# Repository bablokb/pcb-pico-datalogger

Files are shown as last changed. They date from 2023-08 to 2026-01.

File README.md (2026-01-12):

Pico Datalogger with Integrated Power-Management
================================================

This is a hardware and software solution for low-frequency
data-logging with a Raspberry Pi Pico (W). The project started as a
hardware project, but the software runs independently of the special
hardware (PCBs) provided in this repository (see some example setups
as provided in the `examples` folder). Nevertheless, the full function
set of the software is not available with standard components.

Besides logging data to a SD-card, the dataloggers can send data to a
central system (called "gateway"). Normally the gateway acts as a
relay to upstream systems, but it could do anything with the data. See
[Gateway](docs/gateway.md) for details.

Core software functions
-----------------------

  * implemented in CircuitPython
  * support for an external RTC for exact time keeping
  * cyclical sensor readout for a wide range of mostly environmental
    [sensors](docs/sensors.md) (currently 25 directly support
    including Open-Meteo weather data and Tasmota power monitoring)
  * supports I2C (two busses), UART-3V3 and UART-5V devices
  * support I2C-multiplexers (PCA954xA, TCA954xA)
  * readout in intervals or using a time-table
  * implementation of additional sensors only need a small wrapper class
    (given a driver-library is available)
  * logging of data to a micro-SD card or equivalent (e.g. XTSD-chip)
  * configurable post-collection [tasks](docs/tasks.md)
    (e.g. update of a display, sending data using WLAN or LoRa)
  * send data to a gateway (see below)
  * power-optimized programs
  * [web-interface](docs/admin_mode.md) for configuration and data download
  * no programming required for standard setups
  * supports (almost) zero current sleep with specialized hardware

For installation and operation, read the documents linked in the next
section.

Quick Links
-----------

  * [Hardware Setup](docs/hardware.md)
  * [Software (Datalogger)](docs/software_datalogger.md)
  * [Software (Gateway)](docs/software_gateway.md)
  * [Configuration](docs/configuration.md)
  * [Software deployment](docs/deployment.md)
  * [Examples](examples/README.md)
  * [Initial setup of the RTC](docs/rtc_setup.md)
  * [Tools and Scripts](docs/tools.md)
  * [Administration mode](docs/admin_mode.md)
  * [Broadcast mode](docs/broadcast_mode.md)
  * [Setup of Blues-Gateway](docs/blues-gateway.md)

Background
----------

For background on and motivation for this project, please see
<https://opendeved.net/programmes/ilce-in-tanzania/>.

Additional resources
--------------------

  * [Sensors](docs/sensors.md)
  * [Tasks](docs/tasks.md)
  * [Components](docs/components.md)
  * [Hardware Architecture](docs/hw_architecture.md)
  * [Power](docs/power.md)
  * [Pinout](docs/pins.md)
  * [Pinout V2](docs/pins-v2.md)
  * [Pinout V3](docs/pins-v3.md)
  * Case for this PCB: https://github.com/OpenDevEd/case-for-pico-datalogger-rev1.00
  * [KiCAD design-files V1](./pico-datalogger.kicad/Readme.md)
  * [KiCAD design-files V2](./pico-datalogger-v2.kicad/Readme.md)
  * [KiCAD design-files sensor-PCB](./pico-sensor-pcb.kicad/Readme.md)
  * [KiCAD design-files display-adapter](./display-adapter.kicad/Readme.md)
  * [KiCAD design-files LoRa-adapter](./lora-adapter.kicad/Readme.md)
  * [References](docs/references.md)

License
-------

Software in `src` is licensed under the GPL3. Hardware is licensed by:

[![CC BY-SA 4.0][cc-by-sa-shield]][cc-by-sa]

This work is licensed under a
[Creative Commons Attribution-ShareAlike 4.0 International
License][cc-by-sa].

[][cc-by-sa]

[cc-by-sa]: http://creativecommons.org/licenses/by-sa/4.0/
[cc-by-sa-image]: https://licensebuttons.net/l/by-sa/4.0/88x31.png
[cc-by-sa-shield]:
https://img.shields.io/badge/License-CC%20BY--SA%204.0-lightgrey.svg

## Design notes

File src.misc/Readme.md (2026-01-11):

Miscellaneous Sources
=====================

This directory contains various source files for libraries used by the
datalogger.

rtc_ext
-------

This is the source for the rtc_ext module. The compiled version is in
`src.shared/lib9/`.

dataviews
---------

These are the source files from the dataviews-repository
<https://github.com/bablokb/circuitpython-dataviews>. The compiled
version is in `src.shared/lib9/`.

From this project are also the driver files `InkyPack.py` and `phat.py`
for the Pimoroni Inky-Pack and Pimoroni e-ink pHat.

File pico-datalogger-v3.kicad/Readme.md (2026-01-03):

KiCAD-Designfiles for Version 3 PCB
===================================

Here are the KiCAD (v7) design-files for the Datalogger-V3-PCB.

Schematic
---------

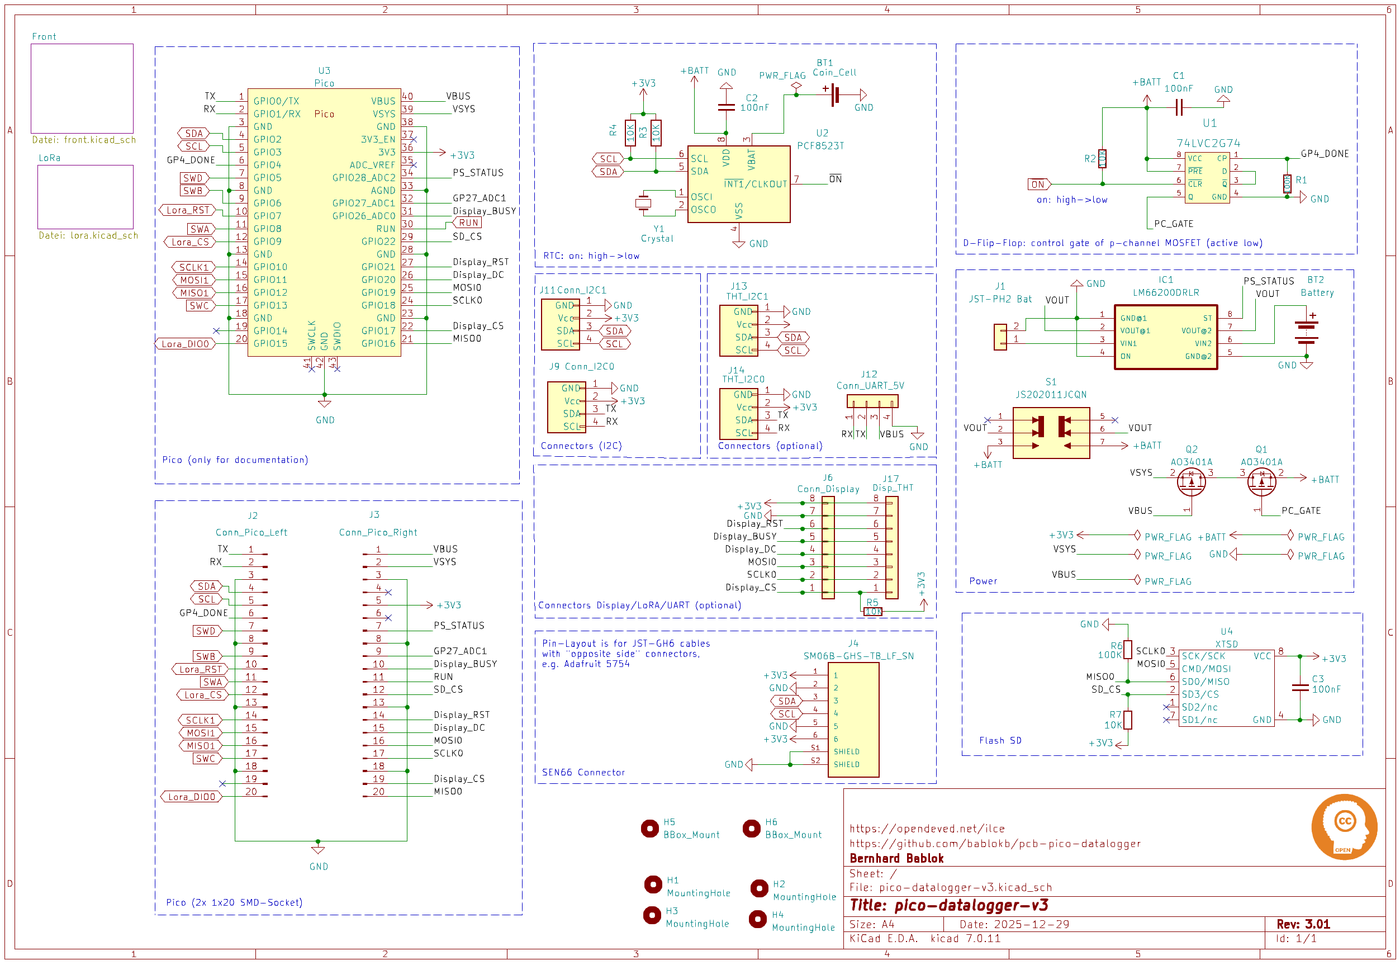
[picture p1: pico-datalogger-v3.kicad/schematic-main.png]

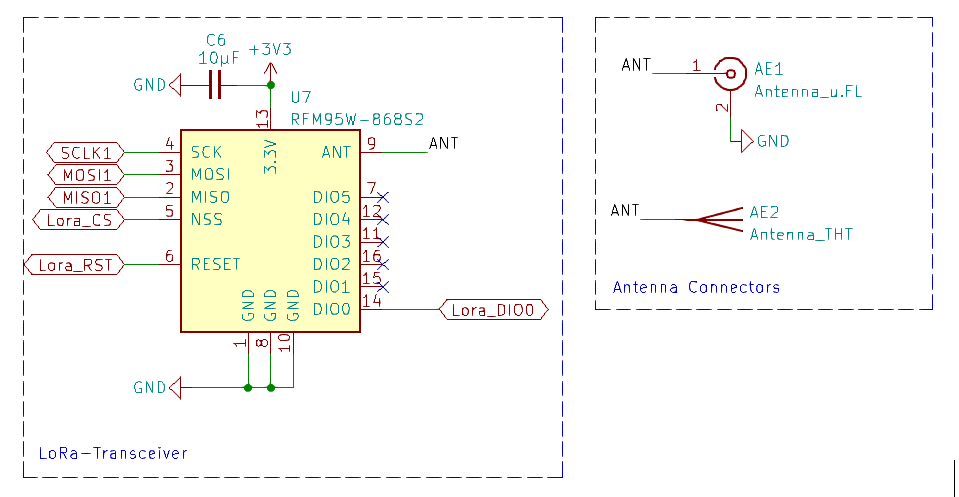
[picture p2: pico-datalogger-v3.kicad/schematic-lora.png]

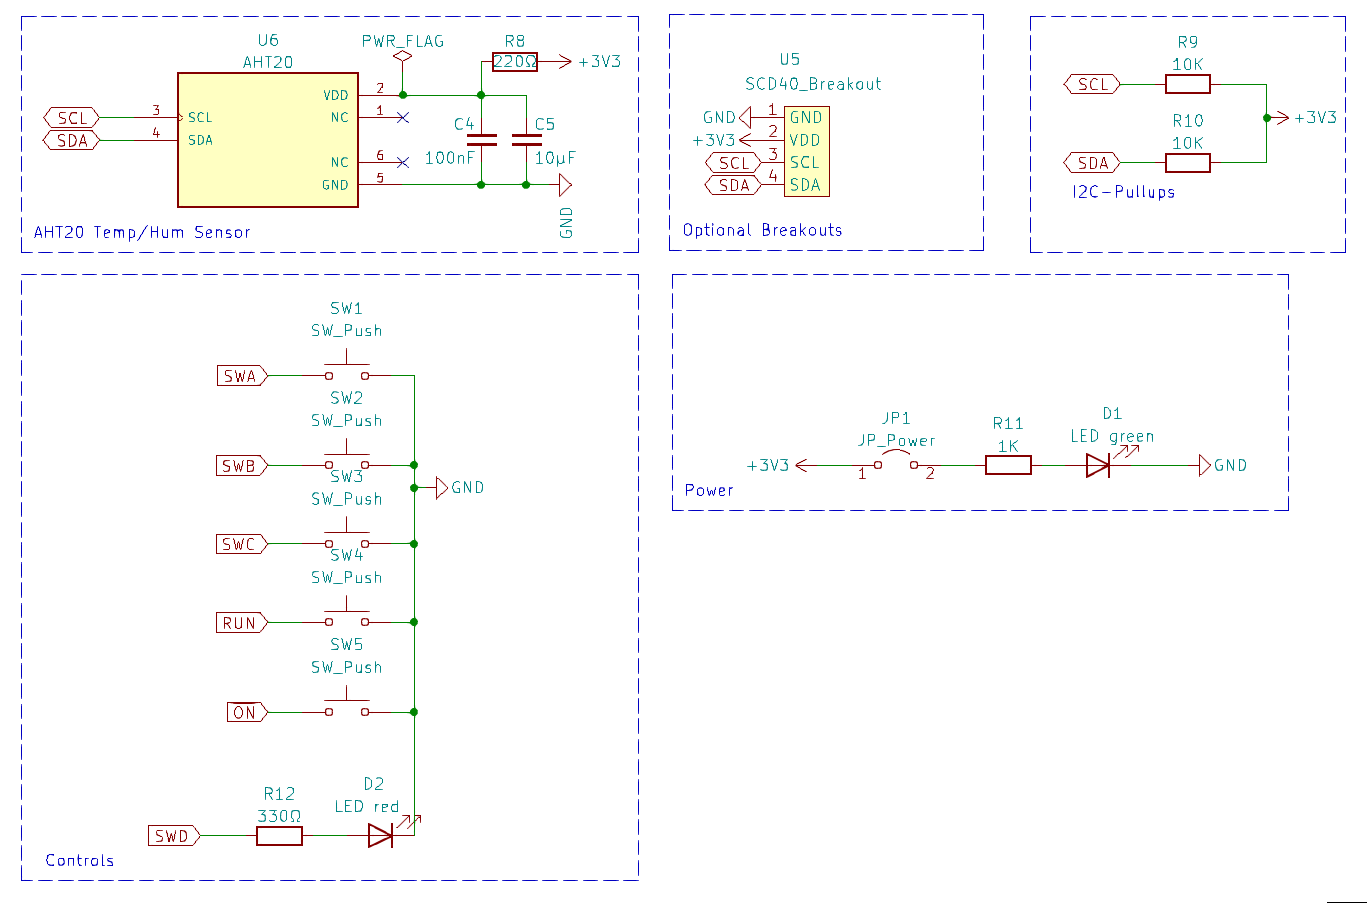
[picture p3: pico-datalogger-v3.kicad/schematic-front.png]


Layout
------

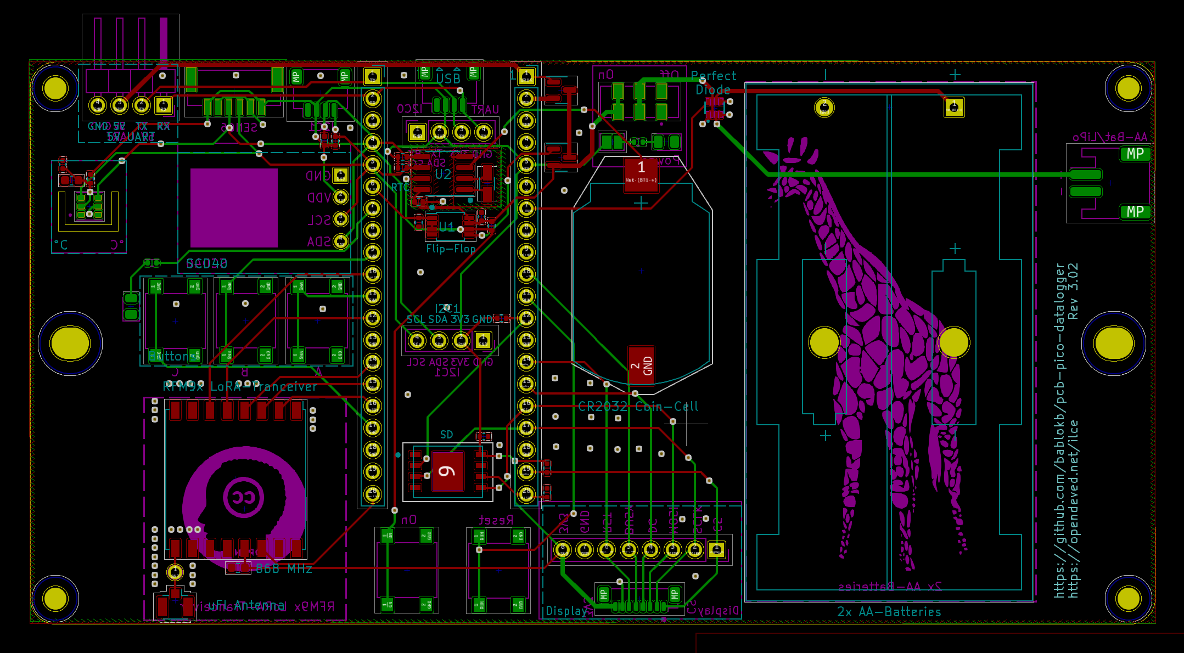
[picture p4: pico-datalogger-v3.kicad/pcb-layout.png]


3D-Views
--------

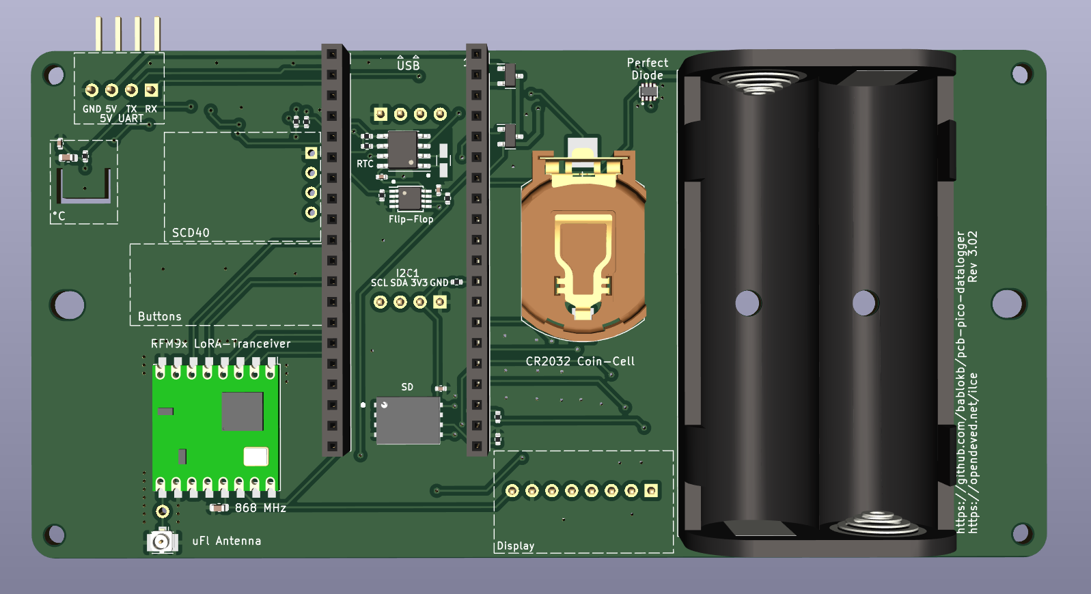
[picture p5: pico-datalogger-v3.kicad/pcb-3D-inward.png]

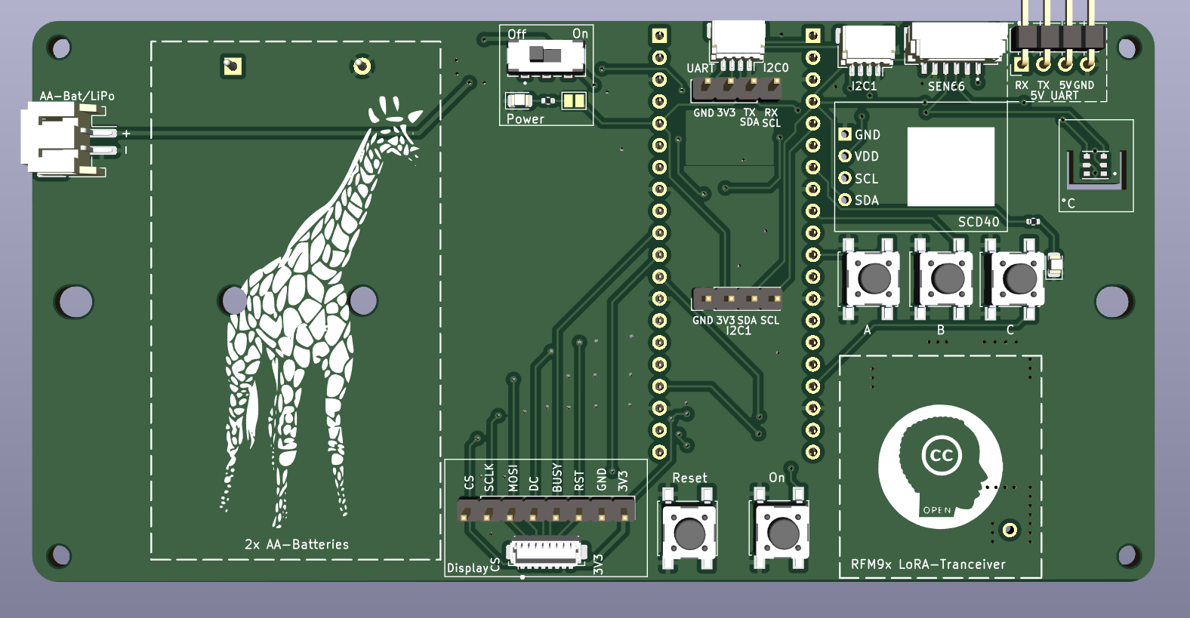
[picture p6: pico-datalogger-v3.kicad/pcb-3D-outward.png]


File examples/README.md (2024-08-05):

Examples
========

This directory contains a number of example setups for the
datalogger-software with standard breakout and components.

Badger2040W
-----------

The Badger2040W is an e-ink display with an integrated Pico-W from
Pimoroni. This device provides a RTC (PCF85063A) and very efficient
power management (with wake on RTC, so time-table based low power
operation is possible). A Stemma/Qt connector allows the connection of
standard sensor breakouts. There is no SD-card support, so data can be
collected and shown on the display, but not saved. Sending data to a
gateway using wifi is possible.

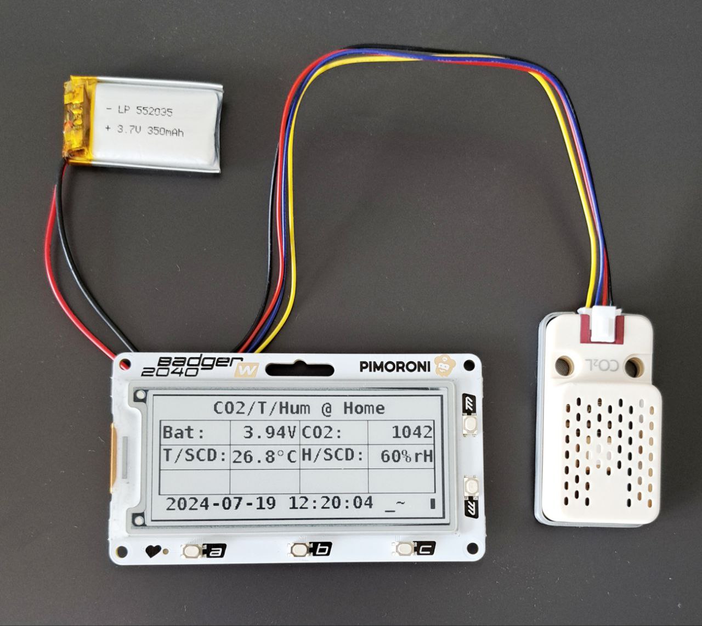
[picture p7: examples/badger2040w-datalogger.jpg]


In the example setup, an SCD41 measures temperature, humidity and
CO2. This setup is ideal for a small, mobile air-quality measurement
system.

PiCowbell-Adalogger
-------------------

The PiCowbell-Adalogger is a Pico-sized breakout with a RTC (PCF8523),
a coincell backup battery and a SD-card slot. The interrupt pin of the
RTC is not exposed, so the RTC does not support wake on RTC and
therefore time-table based operation is limited to continuous mode
with deep-sleep.

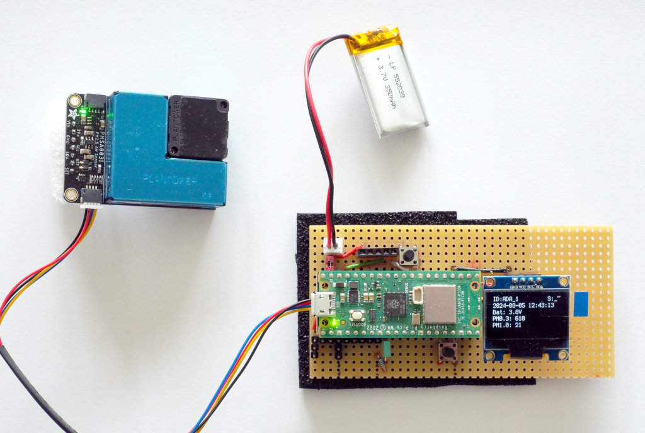
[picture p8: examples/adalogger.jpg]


The setup adds some external components on a perfboard, and thus
mimics most of the special datalogger hardware:

  - JST-PH2 connector for a battery pack/LiPo (upper left)
  - a 5-pin socket for a TPL5111 (to the right of the JST-PH2)
  - a reset button (the adalogger has one, but it is below the Pico-W)
  - a 4-pin socket for an I2C-OLED display (here with the display)
  - a button (used as application button SW_A, lower right)
  - a LED (used as application LED SW_D, in the middle)
  - some additional pins broken out (lower left)

The example here adds an PMS5003 particle sensor (connected via I2C)
and operates in continuous mode (without power-management,
i.e. without TPL511x). Data is not logged to the SD-card but the OLED
displays current data.

Picow-Solo
----------

This example is a standalone configuration for a Pico-W. It reads data
from <https://open-meteo.com> and prints the data to the console. The
sampling interval is 15 minutes, since the data-source does not
provide new data at a higher rate.

You should update the latitude and longitude in `config.py` to your
location (Open-Meteo provides a search function for this). Once up and
running, You should also disable logging in `log_config.py`:

    from log_writer import Logger
    g_logger = Logger(None)

This limits console-output to actual data:

    main.py Ausgabe:
    2024-08-05T13:22:34,22.1,63,1016,3,9.8,306,0.0
    2024-08-05T13:31:04,22.3,63,1016,3,9.7,309,0.0
    2024-08-05T13:46:04,22.5,63,1016,3,9.7,309,0.0

The configuration uses a time-table in continuous mode. In this mode,
the value of `INTERVAL` is ignored, but any interval shorter than 61
seconds still forces the system to use light-sleep instead of
deep-sleep in between sampling.

In a more realistic setup, the data would be at least written to a
SD-card.

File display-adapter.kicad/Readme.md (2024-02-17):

KiCAD-Designfiles
=================

Here are the KiCAD (v6) design-files for the display-adapter-PCB.

Schematic
---------

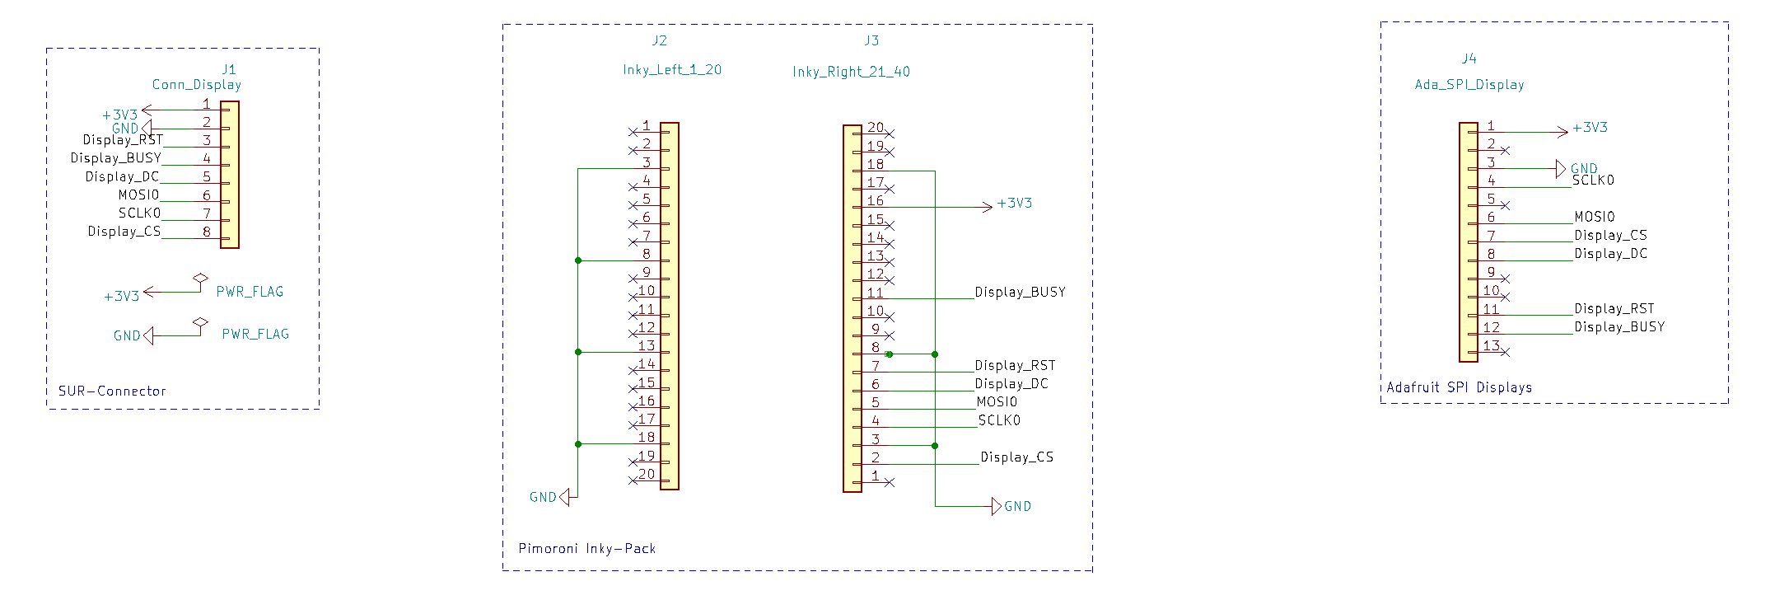
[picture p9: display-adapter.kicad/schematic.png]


Layout
------

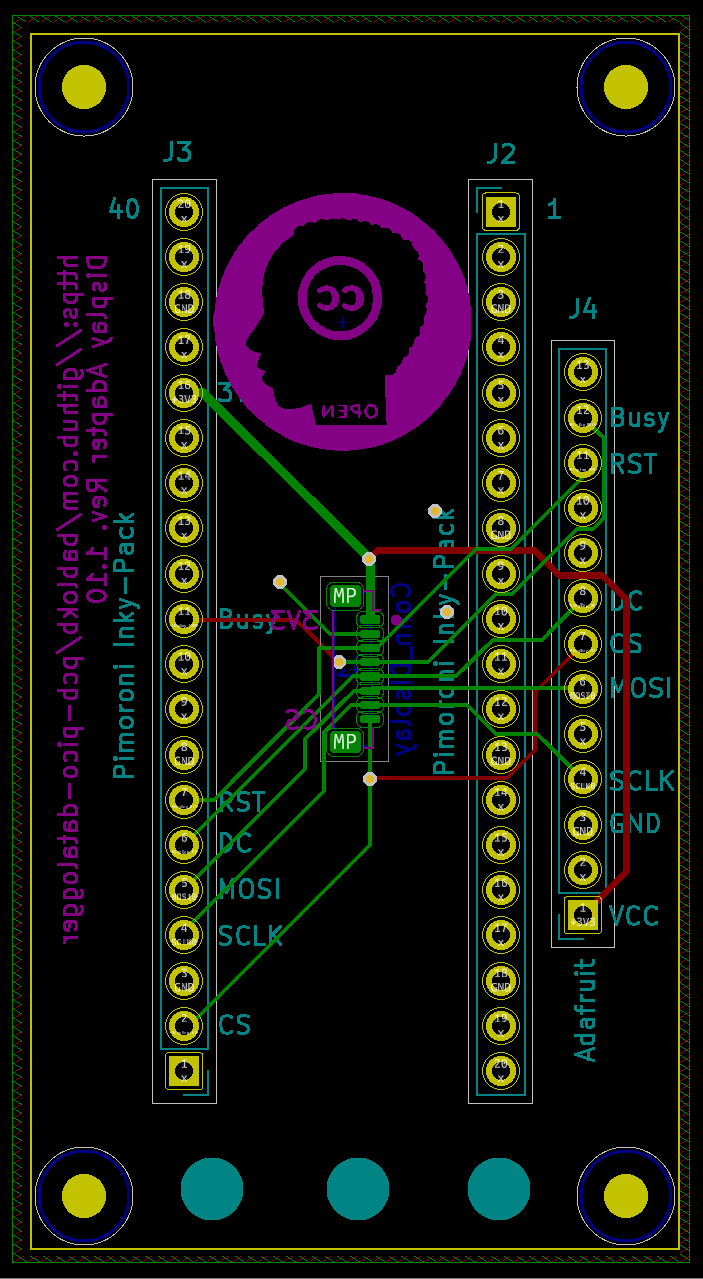
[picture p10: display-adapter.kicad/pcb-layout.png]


3D-Views
--------

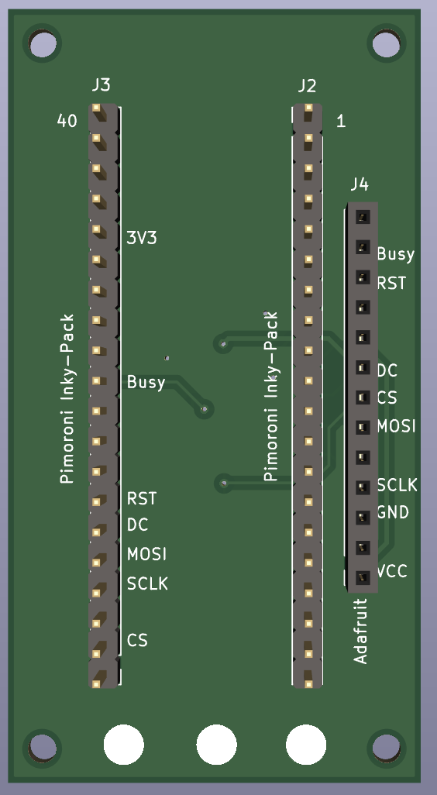
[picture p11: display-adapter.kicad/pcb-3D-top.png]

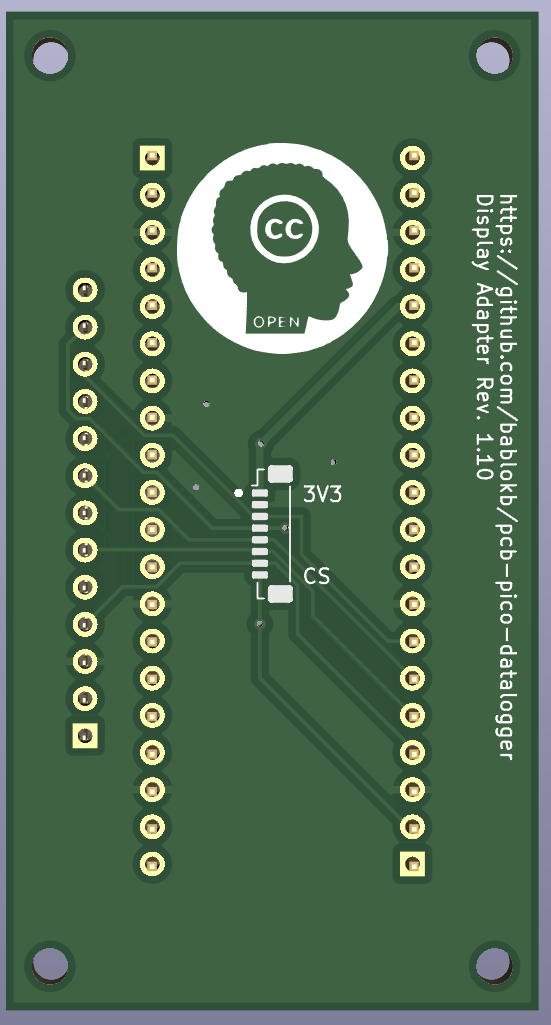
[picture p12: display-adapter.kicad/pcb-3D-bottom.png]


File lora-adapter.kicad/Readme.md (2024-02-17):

KiCAD-Designfiles
=================

Here are the KiCAD (v6) design-files for the LoRa-adapter-PCB.

Schematic
---------

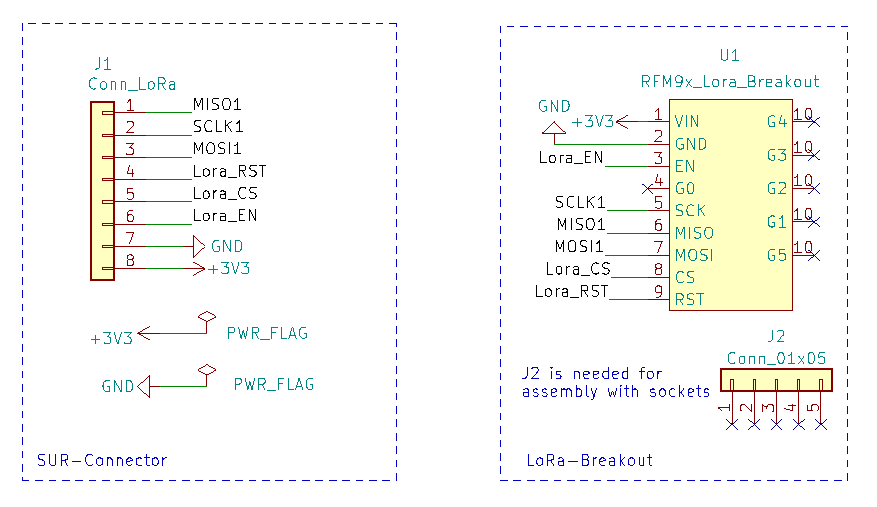
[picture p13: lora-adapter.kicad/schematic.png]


Layout
------

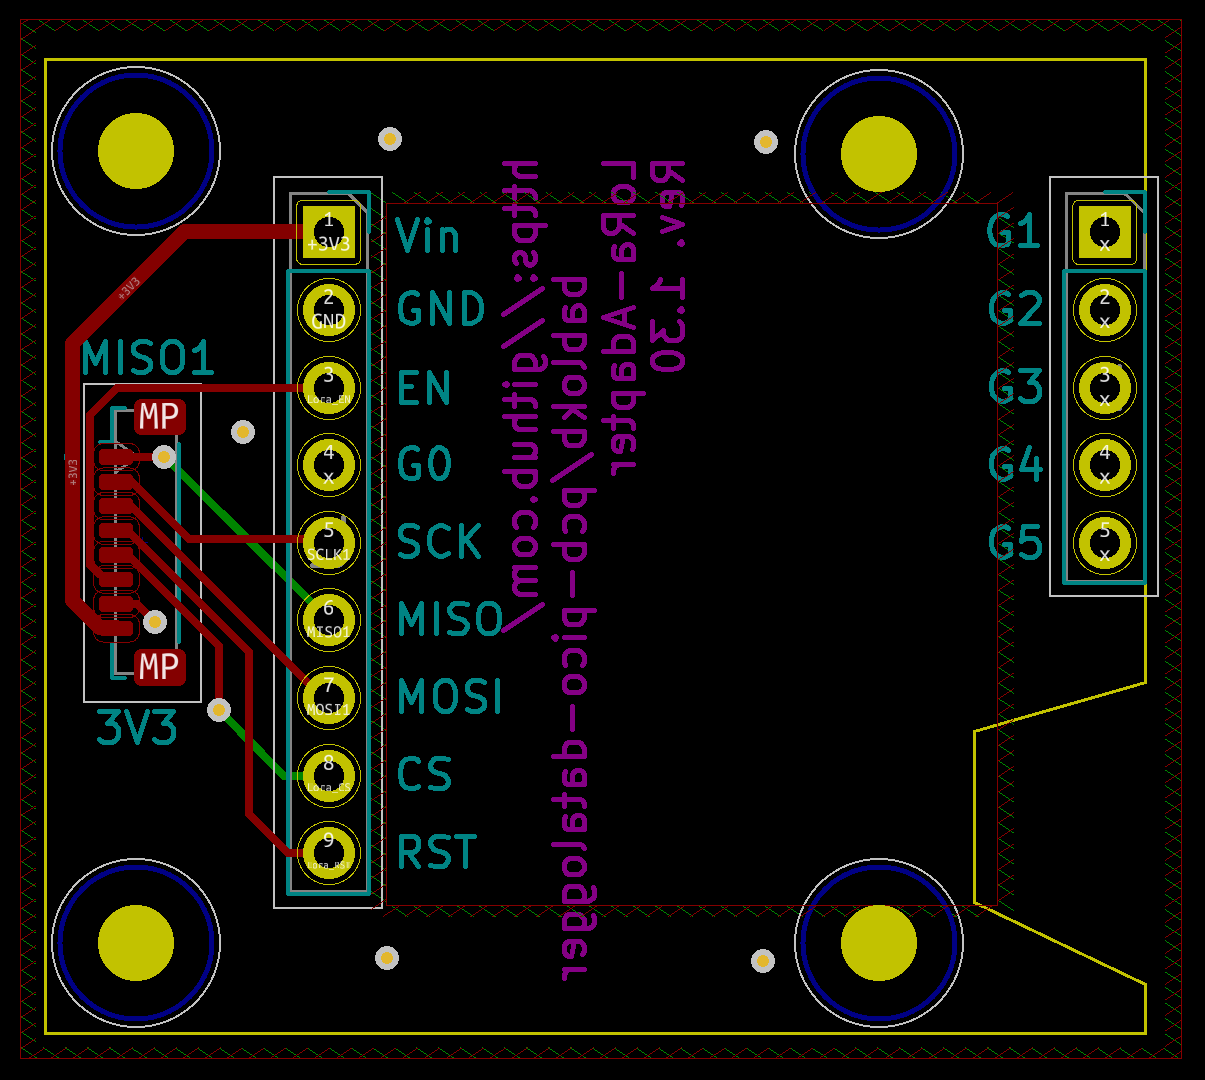
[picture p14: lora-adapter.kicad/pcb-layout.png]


3D-Views
--------

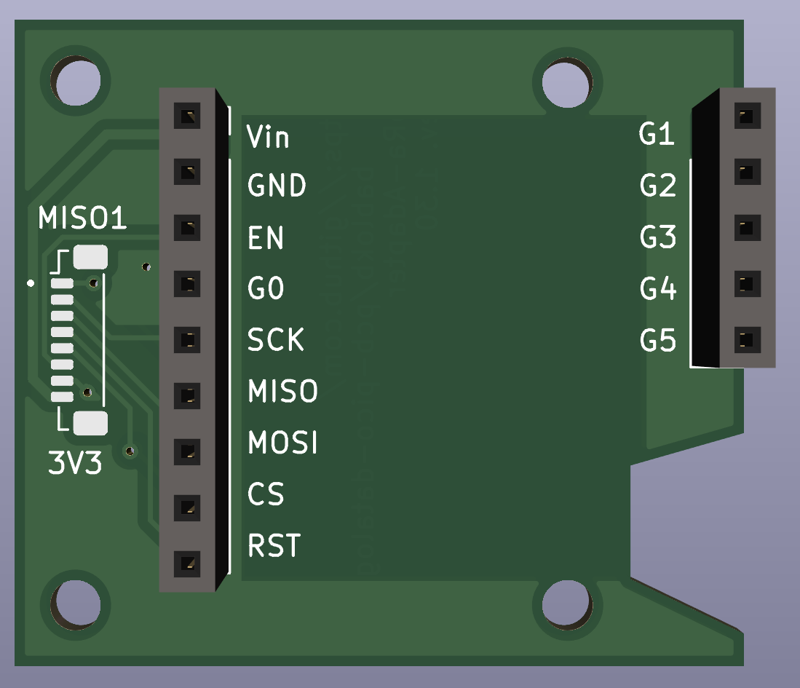
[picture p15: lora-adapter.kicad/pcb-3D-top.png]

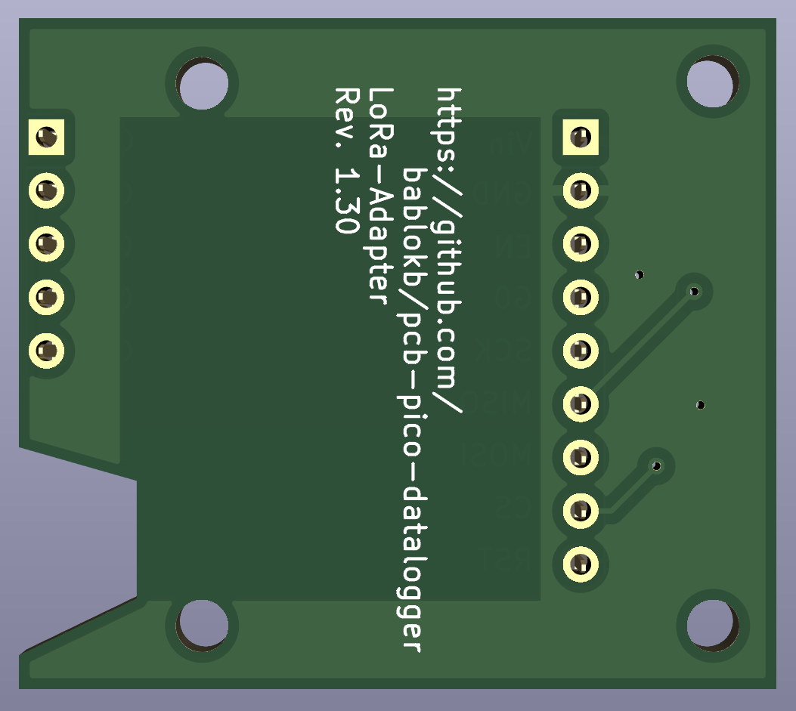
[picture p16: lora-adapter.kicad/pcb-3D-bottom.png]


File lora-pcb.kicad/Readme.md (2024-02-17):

KiCAD-Designfiles
=================

Here are the KiCAD (v6) design-files for the LoRa-PCB.

This PCB is an integrated solution for a RFM9X-SMD-module and a
SURS-connector.

Schematic
---------

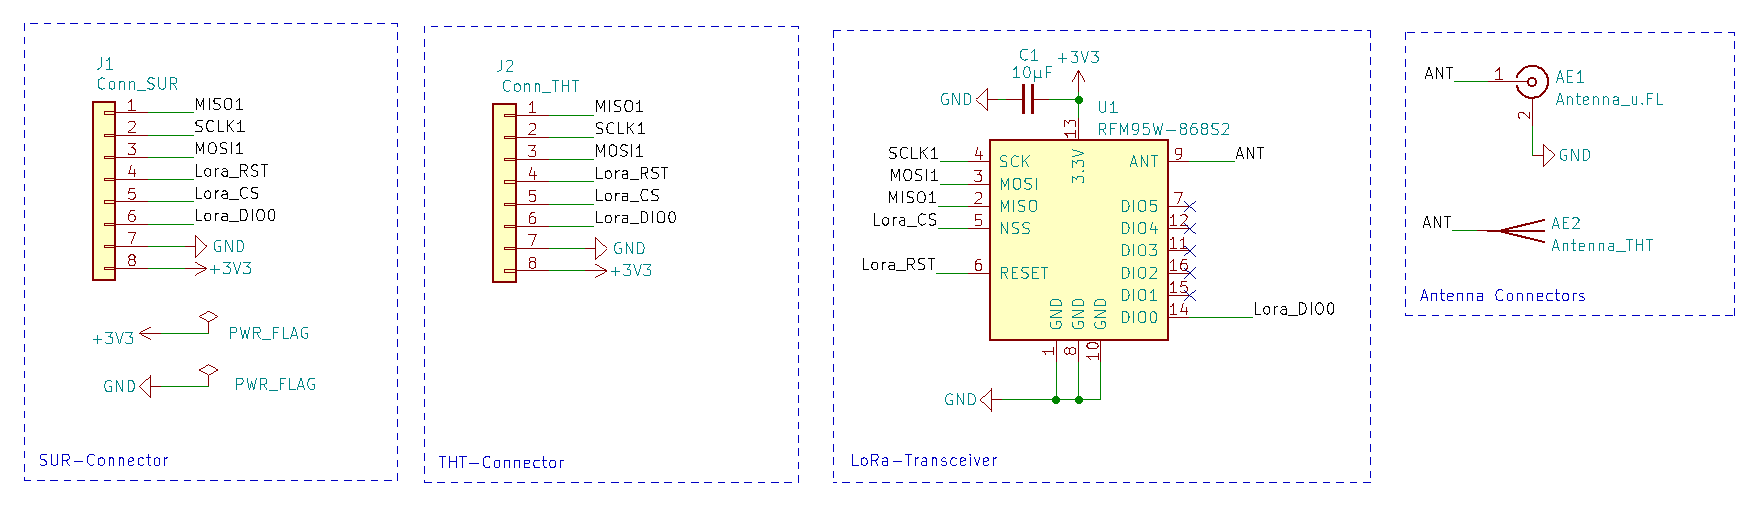
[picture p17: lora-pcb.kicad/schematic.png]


Layout
------

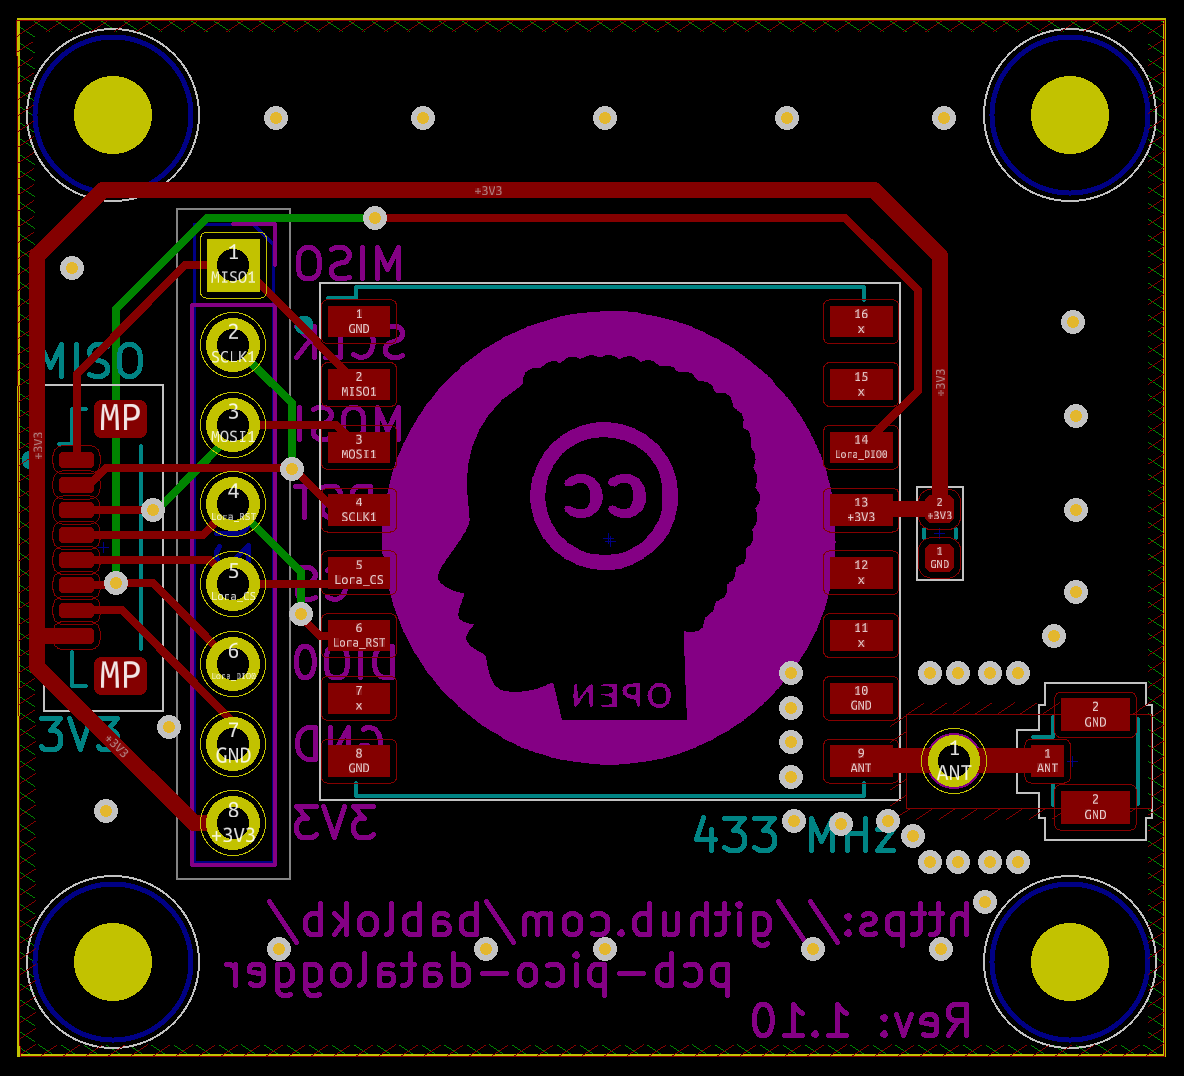
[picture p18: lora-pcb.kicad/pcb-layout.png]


3D-Views
--------

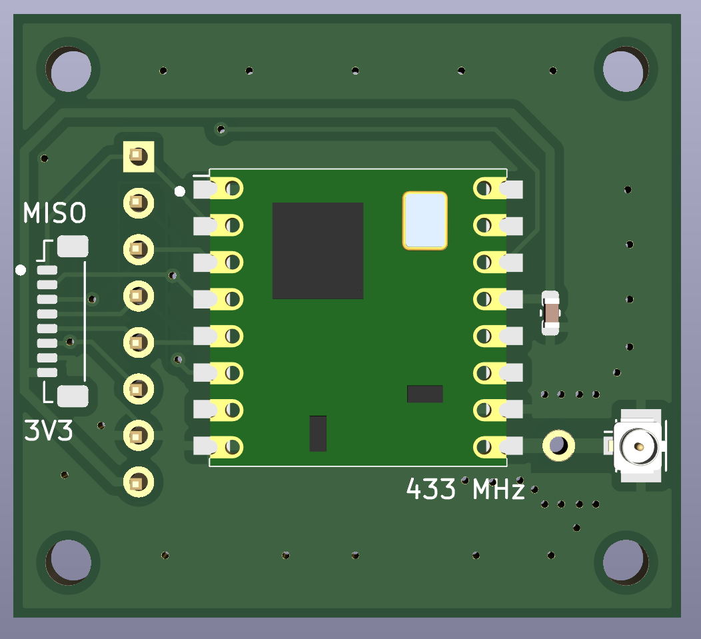
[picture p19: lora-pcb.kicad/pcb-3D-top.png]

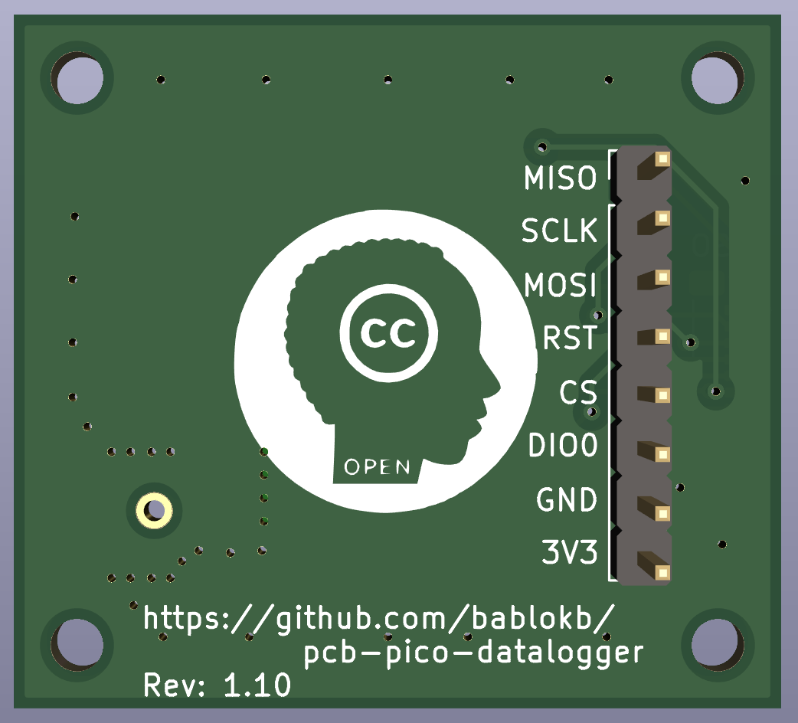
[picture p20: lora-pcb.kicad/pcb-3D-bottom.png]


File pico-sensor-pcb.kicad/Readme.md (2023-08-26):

KiCAD-Designfiles for Sensor-PCB
================================

Here are the KiCAD (v6) design-files for the sensor-pcb.

Target components:

  - connectors to pico-datalogger-v2 pcb
  - AHT20
  - BH1750
  - PDM mic
  - connectors for I2C (Adafruit + Pimoroni layout)
  - ON button
  - RUN button
  - 4 buttons or LEDs

Schematic
---------

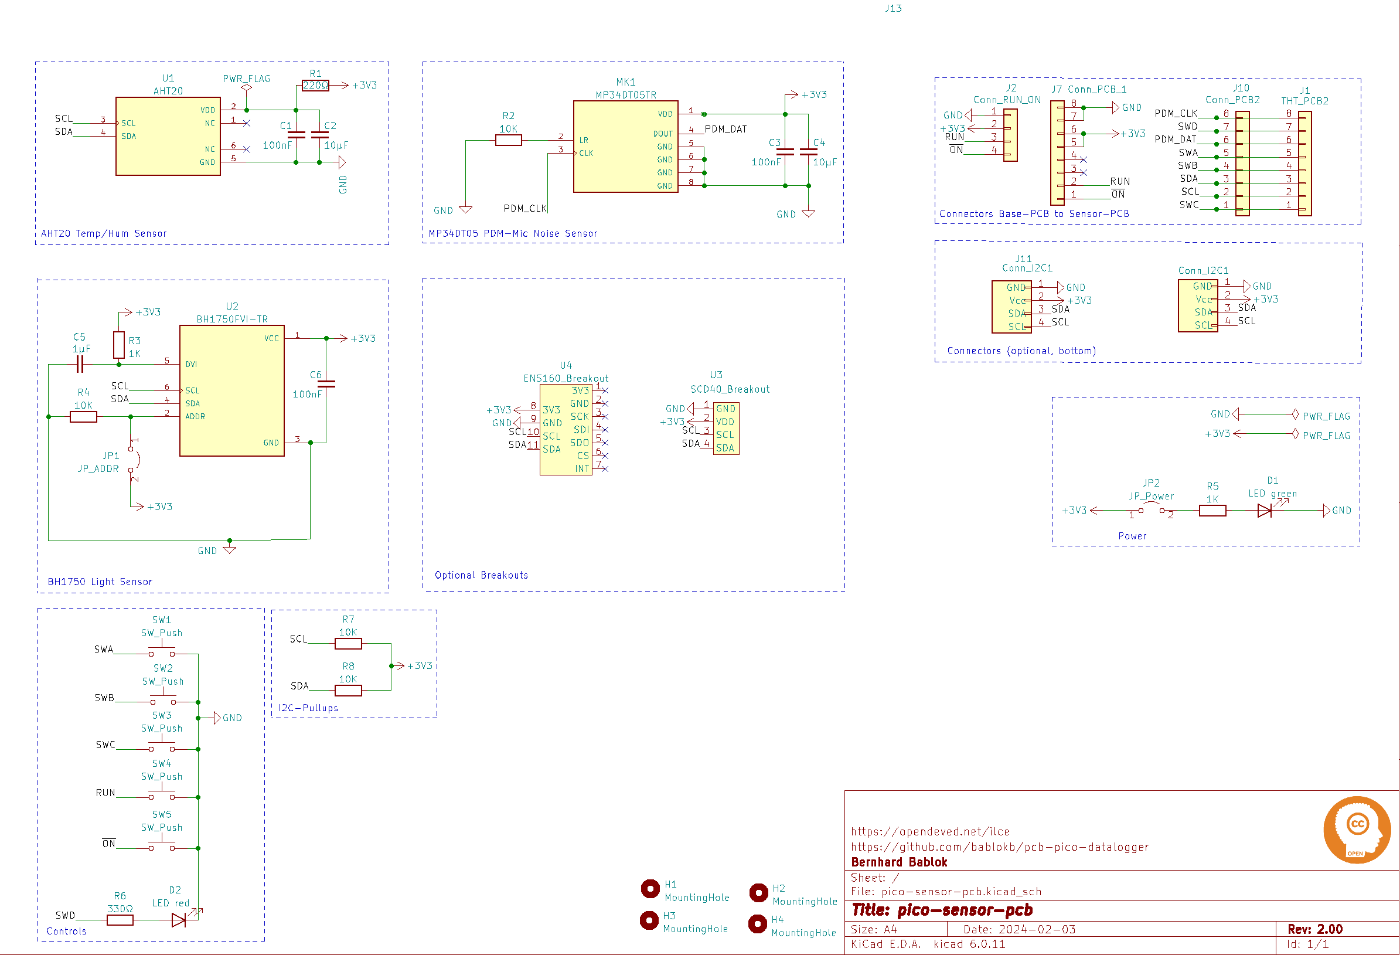
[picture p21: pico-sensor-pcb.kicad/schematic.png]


Layout
------

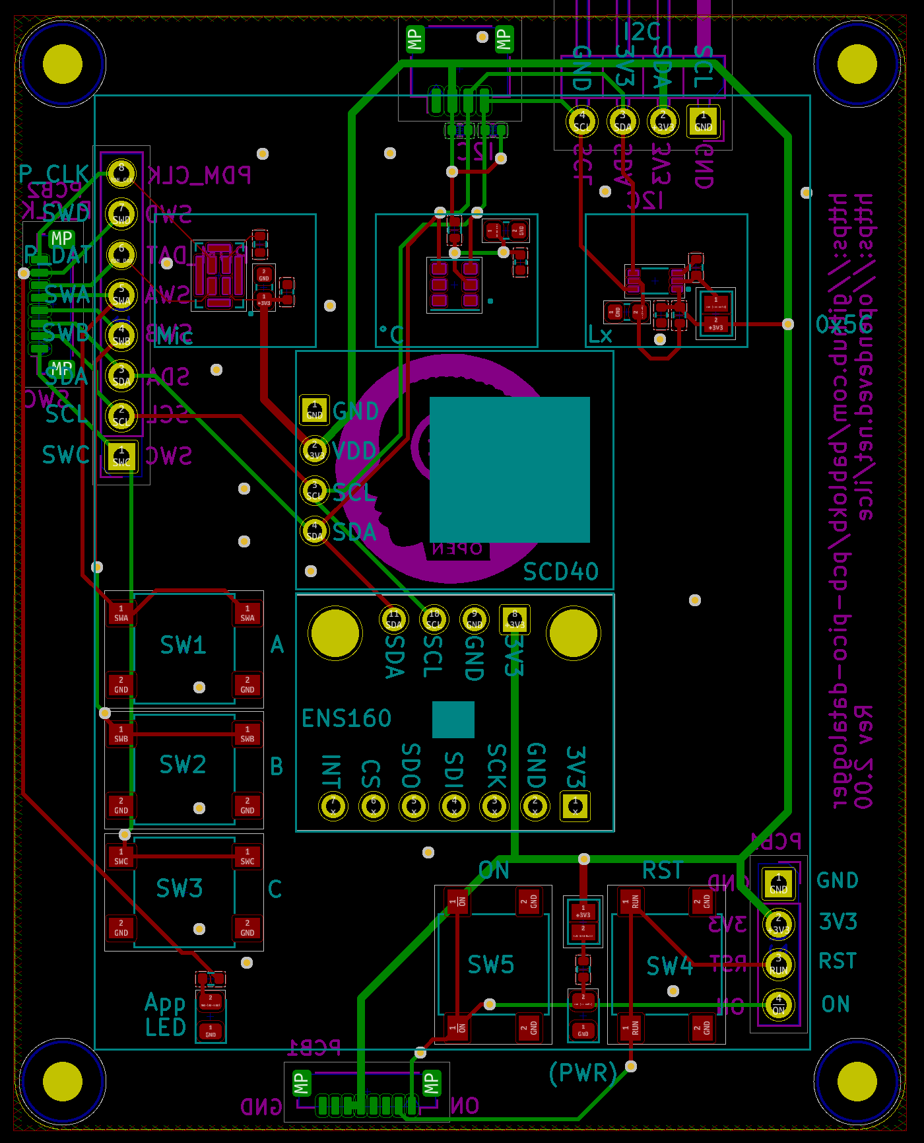
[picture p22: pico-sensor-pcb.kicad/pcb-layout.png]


3D-Views
--------

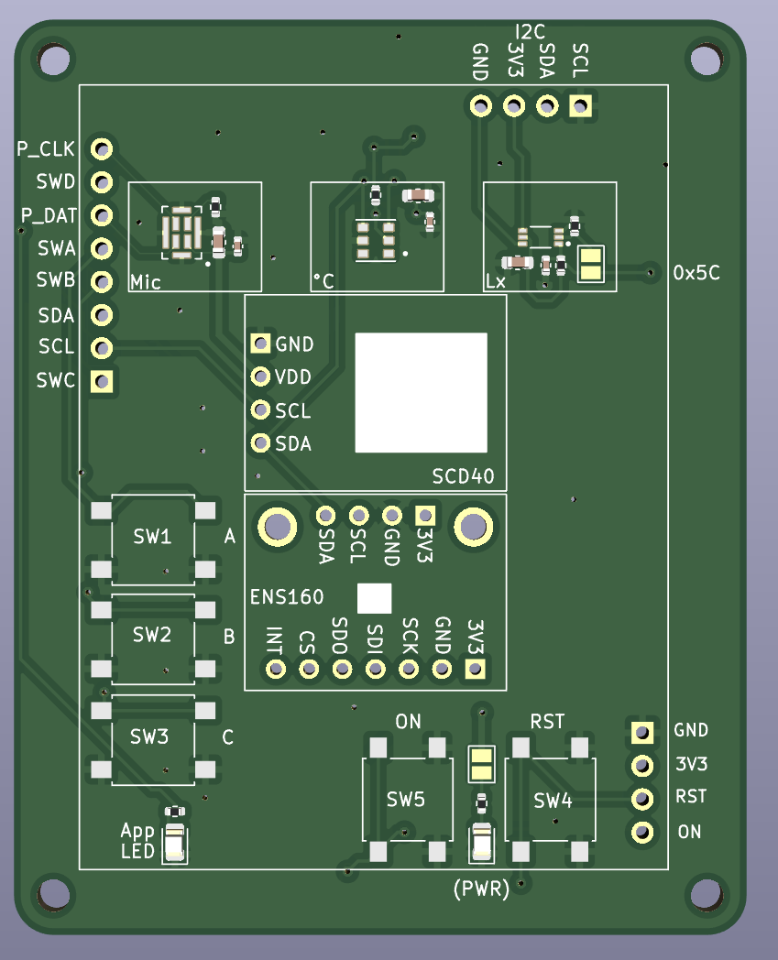
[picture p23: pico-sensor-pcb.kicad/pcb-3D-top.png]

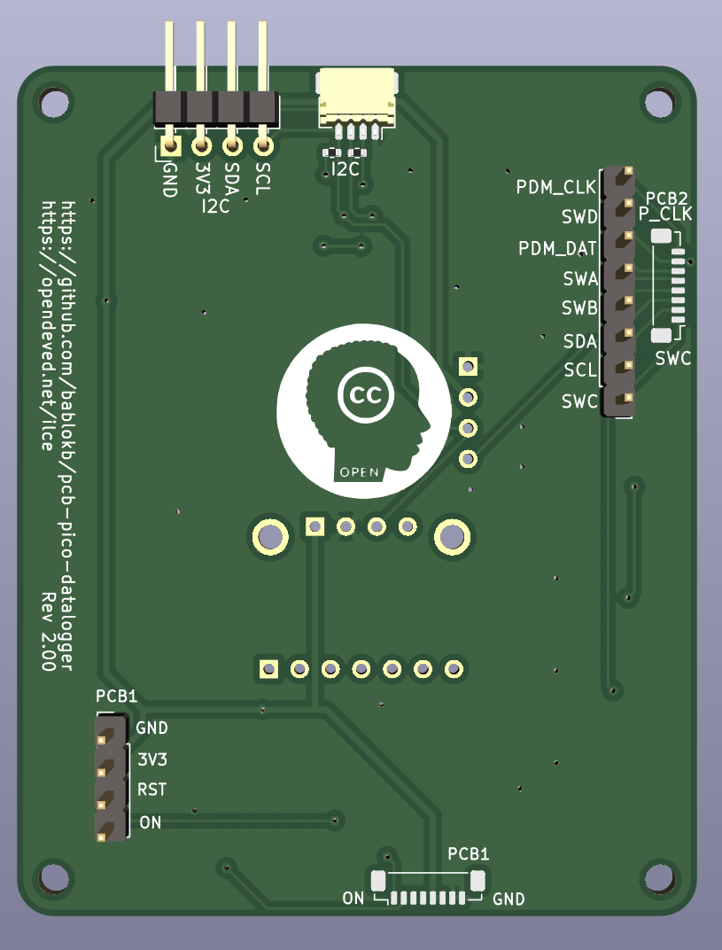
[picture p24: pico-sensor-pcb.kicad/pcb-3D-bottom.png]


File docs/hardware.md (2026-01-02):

Setup
=====

Overview
--------

In this repo you will find various KiCAD design files for the base
and sensor PCB as well as various adapters. All of this is optional, the
software will run on other hardware as well, but with limited
functionality. In the directory `production_files` you will find ready
to order production files for JCLPCB. You typically need the gerber
zipfile, a BOM (bill of materials) and a CPL (pick and place) file.

A number of components are optional. E.g. the SURS-connectors are not
strictly necessary, because you also have througholes as an alternative.
In addition you can save money if you solder the JST-connectors
yourself.

Generic Hardware
----------------

The simplest hardware-setup would be a standalone Pico-W. The device
could read it's builtin sensors or data from the internet. More
realistically, you would add some I2C-sensors, a SD-card breakout for
data-storage and a RTC (currently the PCF8523, PCF8563 and PCF85063(A)
are supported). As a quick-start, the Adafruit PiCowbell Datalogger
(<https://www.adafruit.com/product/5703>) will provide the SD-card
slot and the RTC.

For low-power operation, add a TPL5110 (<https://www.adafruit.com/product/3435>)
or a TPL5111 (<https://www.adafruit.com/product/3573>). The first one
drives power (i.e. connect to VSYS of the Pico), the second one
drives the enable pin (e.g. connect to EN). Both solutions support
sampling intervals up to two hours, but no time-table operation.

You can find some example setups with generic hardware in the
[examples](../examples/README.md) directory.

Additional steps:

  - create a file `pins<name>.py` with the correct pin-mapping. Use one
    of the existing files `src/pins*.py` as a template.
    You don't have to support (connect) all pins if you don't plan to
    use the specific hardware (e.g. LoRa).
  - Connect other hardware components as needed (power, sensors and so on).

Datalogger-PCBs
---------------

The specialized datalogger PCBs support a number of important functions:

  * power management for extremly low standby current (about 1µA)
  * embedded XTSD-chip (emulates a micro-SD card)
  * connectors (Pico, Stemma/Qt, UART, display)
  * JST-PH2 connector for LiPo or battery pack (two AA/AAA)
  * a sensor PCB with a number of standard sensors
    (temperature, humidity, light, noise)

The design has gone through multiple iterations, you can find images
of these versions in the `docs` folder.

Current PCB:




The current datalogger-v3 is a highly integrated version with AA
battery-holder, LoRa-transceiver, buttons and an AHT20 sensor. The
size is optimized to fit into a standard 2-gang backing box.

The buttons support the following functions:

  - ON: start the datalogger (e.g. for an on-demand measurement)
  - RST: restart the datalogger
  - A: hold during boot to start in [Administration mode](./admin_mode.md)
  - B: hold during boot to start in [broadcast mode](./broadcast_mode.md)
  - C: hold during boot to start in firmware update mode

The PCB has a number of connectors for external sensors: 2 Stemma/Qt
for I2C0 and I2C1, and one JST-GH6 connector (for a SEN66). Additional
throughholes allow the attachment of UART components.

Sensor PCB
----------

The sensor PCB provides a number of standard sensors (AHT20, BH1750
and PDM-microphone), five buttons and one application LED.



The sensor PCB was a compagnon PCB to the version 2 datalogger. The
buttons on the sensor PCB have the same functions as on the newest
datalogger-v3 version.

Setup Datalogger-PCBs
---------------------

To setup the PCBs of this repo:

  - Connect a battery pack (two AAA/AA batteries or a single cell LiPo)
    via the battery port
  - Add a coin cell to maintain data on the RTC (CR2032)
  - Plug in a Pico (W)
  - Add sensors to the appropriate connectors
  - v1: Always remove the jumper if you plugin the USB-cable to the Pico, e.g.
    for software updates.
  - v1: (optional) Plug in the display (Pimoroni Inky-Pack) from behind.
  - v2: connect the sensor PCB, the display (optional) and LoRa adapter
    (optional) via SURS-cables.

Software
--------

Head on to

  - [Software (Datalogger)](./software_datalogger.md)
  - [Software (Gateway)](./software_gateway.md)

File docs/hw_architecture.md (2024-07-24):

Hardware Architecture
=====================



The hardware of the breakout supports three main features:

  - Power management: the system toggles between "on" (doing measurements)
    and "off". In the off-state power-consumption is near zero.
  - Automatic wakup: the system can wakeup in fixed intervals or based on
    pre-configured time-points (e.g. at minute 00, 15, 30, 45 of every hour).
  - data-logging to an attached micro-SD card

Various additional connectors allow the user to connect sensors, 
a displays or a LoRa-breakout.

Power Management
----------------

Power management uses a D-type flip-flop. In the v1-PCB, the flip-flop
directly drives the enable pin of the Pico-(W). State changes of the flip-flop
are initiated either by a button, by the interrupt of the RTC or by the
Pico itself. The first two will turn power on, the last one will turn
power off.

When the flip-flop is in "reset"-state, the enable pin of the Pico is pulled
high and the Pico is running. The "done"-pin of the Pico is connected to the
CLK-pin of the flip-flop. A rising edge will toggle the enable pin, thus
turning the system off. The application firmware is in charge of toggling
the "done"-pin after finishing the current measurement cycle.

The v2-PCB does not drive the enable pin of the Pico, but a mosfet that
controls VSYS of the Pico. This is more efficient, since the Pico still
draws current even when the enable pin is pulled low.

Time Management
---------------

Time-keeping uses the PCF8523 RTC with integrated support for a backup-battery.
The PCF8523 supports time-based alarms from one minute to about a month
in the future.

It is the responsibility of the application firmware to set the next
wakeup time-point in the RTC prior to shutdown.

The backup-battery (coin-cell) for the PCF8523 only maintains (time) state,
it does not allow to run the system. Switchover to maintainance mode
occurs when VSYS is below V(th) of the coin-cell, which is normally around
2.5V. This is not ideal for usage with AA-batteries, since they operate
from about 3.1V (full) down to 1.9V. Therefore switchover is disabled as
long as VSYS is above 2V.

SD-Card / Chip
--------------

The v1-PCB has an onboard micro-sd card reader. The v2-PCB uses an XTX-SD
chip which emulates a micro-SD card directly.

The advantage of the chip is that there is no mechanical part involved
and the combination of reader+card is far more expensive than the chip.

Drawbacks of the chip are its smaller size and the need for special software
to download the data. The size of the smallest chip is 128MB which is sufficient
for the purpose of data-logging. The readout is supported by the
[administration mode](./admin_mode.md).

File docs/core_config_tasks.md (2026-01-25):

Task Specific Configuration
===========================

dump_data
---------

| Name | Type | O/M | Description |
|---|---|-----|---|
| SHOW_UNITS | bool |  O  | print values to console or log |

With `SHOW_UNITS = True` (default), sensor values are printed to the log
in pseudo-tabular form with units.

`SHOW_UNITS = False` will print directly in CSV-format to the serial console
(even if logging is redirected or disabled).

update_display
--------------

| Name | Type | O/M | Description |
|---|---|-----|---|
| HAVE_DISPLAY | str  |  O  | display-name (see below) |
| FONT_DISPLAY | str  |  O  | font-name (see below) |
| SIMPLE_UI | bool |  O  | show simple UI (False) |
| DISPLAY_STROBE_WAIT | int  |  O  | extra update time (3) |
| DISPLAY_LAYOUT_RC | bool |  O  | layout is row-column order (True) |
| DISPLAY_LAYOUT_MAXDIM | str  |  O  | max layout dimensions (RxC = 3x4) |

Valid values for `HAVE_DISPLAY`:

  - None (default)
  - "internal" (uses `board.DISPLAY`)
  - "Inky-Pack" (Pimoroni Inky-Pack 2.9" e-Ink display)
  - "Inky-pHat" (Pimoroni Inky-pHat e-Ink display)
  - "Display-Pack" (Pimoroni Display-Pack, needs `HAVE_SD=False`)
  - "Ada-2.13-Mono" (Adafruit 2.13" Mono e-Ink display)
  - "Ada-1.54-Mono" (Adafruit 1.54" Mono e-Ink display)
  - "WeAct-2.9" (WeAct 2.9" Mono e-Ink display)

Valid values for `FONT_DISPLAY`:

  - DejaVuSans-16-subset
  - DejaVuSansMono-12-subset
  - DejaVuSansMono-Bold-16-subset
  - DejaVuSansMono-Bold-18-subset (default)

If `SIMPLE_UI` is true, only a minimalistic (label-based) UI is shown.
This is much faster than the default tabular UI.

The layout of the tabular UI is dynamic with at most three rows and
four columns. Use `DISPLAY_LAYOUT_MAXDIM` to change the default.  Note
that larger layouts use more memory. Values that don't fit into the
layout will still be written to the CSV-file. Most sensors allow the
configuration of properties that are displayed.

`DISPLAY_STROBE_WAIT` will give the e-ink some extra time for updates
before the power-management cuts power in strobe-mode.

send_lora
---------

| Name | Type | O/M | Description |
|---|---|-----|---|
| HAVE_LORA | bool |  O  | support LoRa (RFM9x) |
| LORA_FREQ | float|  M  | 433 / 868 / 915 |
| LORA_BASE_ADDR | int  |  O  | gateway-address (def: 0) |
| LORA_NODE_ADDR | int  |  M  | node-address |
| LORA_QOS | int  |  O  | quality of service (0-7) |
| LORA_TX_POWER | int  |  O  | transmit power (5-23) |
| LORA_RECEIVE_TIMEOUT | float|  O  | LoRa receive timeout (5.0) |
| LORA_MAX_FAILED | int  |  O  | resend limit (5) |

Default transmit power is 13.

Quality of service ranges from 0 (fastest) to 7 (most robust). Default
value is 2. See [LoRa Setup](./lora.md) for details. **The QoS-parameter
must be identical for dataloggers and the gateway!**

This task will buffer data that could not be sent (no reply from the
gateway). The data will be sent the next time. To limit air-time,
a maximum of `LORA_MAX_FAILED` records will be sent at a time.

**Note**: data received at the gateway may be out of order because of
this logic. Sort the data by timestamp if necessary.

update_oled
-----------

| Name | Type | O/M | Description |
|---|---|-----|---|
| HAVE_OLED | str  |  O  | support I2C-OLED (default: None) |
| OLED_TIME | int  |  O  | show OLED at least the given time (3) |
| OLED_VALUES  | str  |  O  | see below |

Valid values for `HAVE_OLED` is `None` or
`"bus,addr,width,height[,rotation]"`.  `bus` can be either `*`, which
will probe all available busses, or an integer bus number. Providing
an explicit bus-number is more efficient.

Some examples:

  - `"0,0x3c,128,32"` (small display on bus 0)
  - `"1,0x3d,128,64"` (large display on bus 1 with alternate address)
  - `"*,0x3c,128,64,180"` (large display, probe busses, with rotation)

`OLED_TIME` is the minimal on-time of the display. Only relevant in
strobe mode (which will cut power).

On the larger 128x64 display, there is room to display two additional
sensor values in addition to basic status information. The format is

    OLED_VALUES = "sensor1(label1) sensor2(label2)"

The sensor is the same as in `SENSORS`, the label is the same as
during display on a normal (e-ink) screen.

The default is:

    OLED_VALUES = "aht20(T/AHT:) aht20(H/AHT:)"

send_udp
--------

| Name | Type | O/M | Description |
|---|---|-----|---|
| UDP_IP | IP |  M  | IP address of destination |
| UDP_PORT | int  |  M  | port of destination |

As network related configurations, these two values have to be
configured in [`secrets.py`](./secrets.md).

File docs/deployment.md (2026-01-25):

Software Deployment
===================

The usual deployment process for CircuitPython just copies all files to
the CIRCUITPY-drive and that's it. For this large project, this does
not work anymore due to space constraints. The solution is to precompile
and compress all files.

Prerequisites
-------------

Deployment needs the following tools:

  - make
  - gzip
  - mpy-cross

The first two tools should be installed on any contemporary
Linux-system (or the WSL). The last tool is part of this repository in
the `bin/`-subdirectory assuming the build-system runs on a Linux
host. See
<https://adafruit-circuit-python.s3.amazonaws.com/index.html?prefix=bin/mpy-cross/>.
for other versions.

**Note: if the versions of mpy-cross provided in `bin/` are not
correct for your OS-environment, download the correct versions and put
them somewhere in your `PATH`. Be sure to name them `mpy-cross9` and
symlink `mpy-cross10` to `mpy-cross9`.**

Simple Usage
------------

Run

    > make

in the root-directory of the project. This creates the subdirectory `deploy`.
After that, you can manualy copy all files below `deploy` to your device.

To select between CircuitPython 9.x and 10.x builds, pass `CP_VERSION=9|10`
to `make`. The default is `CP_VERSION=9`.

**`CP_VERSION=10` is currently not recommended!**.

Select Datalogger-PCB version
-----------------------------

The default builds a system for the v2 version of the datalogger PCB. To
build a system for the v1 PCB, run

    > make PCB=v1

This make-variable pulls in the correct pin-mapping
(`src/pins${PCB}.py`).  For other mappings pass in a different value
for `PCB` (e.g. when using a PicoBell Adalogger: `PCB=pbada`). Create
an appropriate named pin-configuration file if necessary.

You can also pass in a path to the mapping file, in this case the mapping
file can be out of tree (i.e. not within the `src/`-direcotory).

Direct Deployment
-----------------

Run

    > make DEPLOY_TO=/path/to/your/mounted/CIRCUITPY

This will directly update files on your device if the CIRCUITPY-drive is
already mounted.

Advanced Usage
--------------

You can pass paths to your specific configurations and secrets-files on
the commandline:

    > make PCB=v1|v2|path-to-pins.py \
         DEPLOY_TO=whatever \
         CONFIG=my_special_config.py \
         LOG_CONFIG=my_logconfiguration.py \
         AP_CONFIG=my_apconfiguration.py \
         SECRETS=my_credentials.py \
         CP_VERSION=9

After invocation of make, the commandline arguments are saved and reused.
I.e. a subsequent call to make does not need the arguments anymore.

You can even keep sets of make-variables, e.g.:

    > cat my_vars.txt
      PCB=v1|v2|path-to-pins.py
      DEPLOY_TO=whatever
      CONFIG=my_special_config.py
      LOG_CONFIG=my_logconfiguration.py
      AP_CONFIG=my_apconfiguration.py
      SECRETS=my_credentials.py
      CP_VERSION=8

    > make MAKEVARS=my_vars.txt

Again, make remembers all relevant variables (in the file `makevars.tmp`)
and does not need the argument on subsequent runs.

Building the Gateway-Firmware
-----------------------------

The buildsystem also supports the gateway. While the "default" target builds
the datalogger-firmware, the target "gateway" builds the gateway software:

    make gateway MAKEVARS=...

Otherwise, the mechanisms are the same for both.

Cleanup
-------

To cleanup a temporary `deploy`-directory (and the file `makevars.tmp`),
run

    make clean

If you deployed directly to your device, this will erase your device, so
take care.

Build Template
--------------

A set of build template files for a datalogger and a gateway are
availabe from the `build-template`-folder. See the
[Readme](../build-template/Readme.md) for instructions on how to use
them.

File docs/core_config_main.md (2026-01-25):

Main Datalogger Configuration
=============================

Logger-Identification
---------------------

| Name | Type | O/M | Description |
|---|---|-----|---|
| LOGGER_NAME | str  |  M  | Name of the logger |
| LOGGER_ID | str  |  M  | ID of the logger |
| LOGGER_LOCATION | str  |  M  | Location, e.g. plus-code |
| LOGGER_TITLE | str  |  O  | Default: ID: NAME |

CSV-File
--------

| Name | Type | O/M | Description |
|---|---|-----|---|
| CSV_FILENAME | str  |  O  | CSV filename. Details below.|
| CSV_HEADER_EXTENDED | bool |  O  | Write extended header |

`CSV_FILENAME` must start with  `/sd/`.

The name of the generated CSV-file can be dynamic. The following
placeholders are possible:

  - `{ID}`: the `LOGGER_ID`
  - `{YMD}`: the date in the format `yyyy-mm-dd`
  - `{Y}`: the year in the format `yyyy`
  - `{M}`: the month in the format `mm`
  - `{D}`: the day in the format `dd`

`CSV_HEADER_EXTENDED` will write additional header lines:

    #  nr: header

for all columns in the CSV. A normal header line

    #h0,h1,...,h<n>

is always written, regardless of the value of `CSV_HEADER_EXTENDED`.

Sensors
-------

| Name | Type | O/M | Description |
|---|---|-----|---|
| SENSORS | str  |  M  | list of sensors |
| SENSORS_CSV_ONLY | str  |  O  | sensors not for the display |

`SENSORS` is a blank delimted string with sensor specifications.
Each entry must be in **lowercase** and in any of the
following formats (no spaces allowed!):

  - sensor
  - sensor(bus)  
    bus = 0, 1, ... (higher numbers with I2C-multiplexers)
  - sensor(addr) 
    addr = 0x..
  - sensor(addr,bus)

For a list of available sensors, see [sensors](./sensors.md).

When no bus is provided, busses are probed in the order i2c0,i2c1
(i2c0 only if `HAVE_I2C0=True` below).  When no address is provided,
the default address as configured in the driver is used. `addr`
**must** have a leading `0x`.

Since the display can only show 6 values, you can exclude sensors
from the display. The data is still recorded in the CSV.
Entries in 'SENSORS_CSV_ONLY' must match exactly to entries in 'SENSORS'.

Tasks
-----

| Name | Type | O/M | Description |
|---|---|-----|---|
| TASKS | str  |  M  | List of tasks |

List of tasks to execute. This is a blank delimeted list. See
[tasks](./tasks.md) for a list of available tasks and also check
[task-specific configuration](./core_config_tasks.md).

Time Updates
------------

| Name | Type | O/M | Description |
|---|---|-----|---|
| NET_UPDATE | bool |  O  | update time from time-server|
| SAVE_WAKEUP | bool |  O  | save/restore wakeup time |

`NET_UPDATE` defaults to `False` since there is no time-server
available any more that can be used without an API-key.

`SAVE_WAKEUP` is a workaround for buggy batteries. The system
saves the wakeup time on SD-card and restores the time after the
next boot in case the time is invalid and cannot be updated
from a time-server.

Sample-Mode and Intervals
-------------------------

| Name | Type | O/M | Description |
|---|---|-----|---|
| STROBE_MODE | bool |  O  | continuous or strobe mode |
| INTERVAL | int  |  O  | interval in cont. mode |
| TIME_TABLE | |  O  | time-table |

In `STROBE_MODE`, the system cuts power after data
collection. Otherwise, the system will use deep-sleep (light-sleep for
intervals shorter than 61 seconds). Without available power-management
(see `HAVE_PM` below), the system uses deep-sleep as a fallback even
in strobe-mode.

`INTERVAL` is the time-period between samples. **`INTERVAL` is ignored
if you define a time-table**. The default value for `INTERVAL` is
900 seconds (i.e. 15 minutes).

Using `INTERVAL=0` will sample the sensors as fast as possible.
Depending on the specific sensors, this can be as low as once every
second with a RP2040.

A time-table is a list with one entry per day, starting with Monday.
For every day, two tuples define the hours and minutes when sampling
takes place.

A formal definition of an entry is:

    ((h_start,h_end,h_inc),(m_start,m_end,m_inc))

Start and end values are inclusive. The time-table

    ((7,18,1),(0,59,15)),
    ((7,18,1),(0,59,15)),
    ((7,18,1),(0,59,15)),
    ((7,18,1),(0,59,15)),
    ((7,18,1),(0,59,15)),
    (None,None),
    (None,None)
    ]

will wake up the system Mo-Fr from 07:00-18:45 every 15 minutes.

Note that time-table based wakeup will only work if either the
PM-circuitry supports wake by RTC-alarm, or in continuous-mode
(i.e. `STROBE_MODE=False`).  In the latter case, the behaviour depends
on the precision of the internal RTC, which is usually not great
(the internal RTC of the RP2040 is off by about 8s per day).

Hardware Setup
--------------

| Name | Type | O/M | Description |
|---|---|-----|---|
| HAVE_PM | bool |  O  | have power-management (True) |
| SHUTDOWN_HIGH | bool |  O  | shutdown on high-transition (True) |
| HAVE_RTC | str  |  O  | type and bus (def: PCF8523(1)) |
| HAVE_SD | bool |  O  | support SD (True) |
| HAVE_I2C0 | bool |  O  | also use I2C0 (False) |
| HAVE_I2C_MP | str  |  O  | I2C-multiplexer definition (None) |
| HAVE_LIPO | bool |  O  | use LiPo (False) |
| HAVE_DISPLAY | str  |  O  | name of the display (see below) |
| FONT_DISPLAY | str  |  O  | font for the display (see below) |
| HAVE_LORA | bool |  O  | support LoRa (RFM9x) |
| HAVE_OLED | str  |  O  | support I2C-OLED |
| BTN_A_CODEFILE | str  |  O  | run-file for button A (admin.py) |
| BTN_A_FLASH_RW | bool |  O  | remount flash rw (True) |
| BTN_B_CODEFILE | str  |  O  | run-file for button B (broadcast.py) |
| BTN_B_FLASH_RW | bool |  O  | remount flash rw (False) |
| BTN_C_CODEFILE | str  |  O  | run-file for button C (bootloader.py)|
| BTN_C_FLASH_RW | bool |  O  | remount flash rw (False) |

Valid values for `HAVE_RTC`:

  - None
  - "PCF8523(bus)"
  - "PCF8563(bus)"
  - "PCF85063(bus)"

`bus` must be a valid bus-number, usually `0` or `1` except if you
attach the RTC to an IC2-multiplexer (see below).

I2C-multiplexers are supported using `HAVE_I2C_MP`. The format is

    HAVE_I2C_MP = "spec1 spec2 ..."

where each specification is `chip(bus[,addr])`. Currently, only chips
that are implemented by the TCA9548A-library are supported, i.e.
PCA9546A, PCA9548A, TCA9546A and TCA9548A (you can ommit the trailing
'A').

The `bus`-parameter *must* be `0` or `1`. The optional address
defaults to `0x70` and must be specified in hex-notation if not
omitted.

Every multiplexer will add 4 or 8 I2C-channels. When defining sensors,
the bus-number will start at 2 and will then increment according to
the multiplexer used. E.g. when adding a 4 channel and an 8 channel
multiplexer, the bus-numbers will be 2-5 and 6-13.

See [task configuration](./core_config_tasks.md) for details about
`HAVE_DISPLAY`, `FONT_DISPLAY`, `HAVE_LORA` and `HAVE_OLED`. 

Development/Test
----------------

| Name | Type | O/M | Description |
|---|---|-----|---|
| TEST_MODE | bool |  O  | switch dev-features on (False)  |
| BLINK_START | int  |  3  | blink before data-sampling |
| BLINK_TIME_START | float| 0.5 | blink duration before sammpling |
| BLINK_END | int  |  5  | blink after data-sampling |
| BLINK_TIME_END | float| 0.25| blink duration after sampling |

Test-mode writes a lot of additional information to the console and
is therefore not useful if not connected to a console. It also slows
down sampling.

Blinking takes place before and after sensor-readout, but only in
test-mode. It blinks the LED on the Pico(W)-PCB, which is usually
not visible except in a lab-environment.

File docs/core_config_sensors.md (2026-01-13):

Sensor Specific Configuration
=============================

Most [sensors](./sensors.md) will will not need any specific configuration.
There are a few exceptions.

Some sensors will report multiple properties, e.g. temperature,
humidity and pressure. The value of `xxxx_PROPERTIES` will configure
which of them (and in which order) are shown on the display. Note that
all values will be recorded in the CSV regardless of the value of
`xxxx_PROPERTIES`. it is also possible to exclude all sensor
properties from the display by adding them to `SENSORS_CSV_ONLY`.

AHT20
-----

| Name | Type | O/M | Description |
|---|---|-----|---|
| AHT20_PROPERTIES | str  |  O  | properties for display |
| | | | ("t h") |

AM2320
-----

| Name | Type | O/M | Description |
|---|---|-----|---|
| AM2320_PROPERTIES | str  |  O  | properties for display |
| | | | ("t h") |

BME280
------

| Name | Type | O/M | Description |
|---|---|-----|---|
| ALTITUDE_AT_LOCATION | int  |  O  | altitude in meters (540)  |
| BME280_PROPERTIES | str  |  O  | properties for display |
| | | | ("t h pl ps") |

Properties:

  - t: temperature
  - h: humidity
  - pl: pressure at location
  - ps: pressure at sea-level (converted)

The altitude is necessary to convert pressure readings to sea-level
pressure. Default is 540m.

BMP280
------

| Name | Type | O/M | Description |
|---|---|-----|---|
| ALTITUDE_AT_LOCATION | int  |  O  | altitude in meters (540)  |
| BMP280_PROPERTIES | str  |  O  | properties for display |
| | | | ("t pl ps") |

Properties:

  - t: temperature
  - pl: pressure at location
  - ps: pressure at sea-level (converted)

The altitude is necessary to convert pressure readings to sea-level
pressure. Default is 540m.

ENS160
------

| Name | Type | O/M | Description |
|---|---|-----|---|
| ENS160_DISCARD | bool |  O  | only keep last readout (True) |
| ENS160_INTERVALS  | list |  O  | list of sampling intervals ([0,5]) |
| ENS160_WARMUP | int  |  O  | wait-time when status==1 (190) |
| ENS160_PROPERTIES | str  |  O  | properties for display ("AQI TVOC eCO2") |

The ENS160 gives better results with multiple samples. Normally, only
the last sample is saved to CSV, the others are discarded. For testing
purposes, this behaviour can be change with `ENS160_DISCARD`.

`ENS160_INTERVALS` will define the number of samples as well as the
intervals between samples. The default samples once at readout time
and then again five seconds later.

In case the sensor is in it's initial startup-phase (`status==2`), all
values returned will be zero. When `status==1` (warmup), the system
switches to deep-sleep for `ENS160_WARMUP` seconds.

The sensor queries three properties: an "air quality index", the
"total volatile organic compounds" and "equivalent CO2". Since the
values of the AQI seem useless and the TVOC and eCO2 are highly
correlated, only a subset of the properties can be displayed on the
display using `ENS160_PROPERTIES`. The CSV will always record all
properties (including status).

HTU31D
-----

| Name | Type | O/M | Description |
|---|---|-----|---|
| HTU31D_PROPERTIES | str  |  O  | properties for display |
| | | | ("t h") |

MHZ19
-------

| Name | Type | O/M | Description |
|---|---|-----|---|
| MHZ19_RETRIES | int  |  O  | retry reads (3) |
| MHZ19_PROPERTIES | str  |  O  | properties for display ("c t") |
| MHZ19_INIT_TIME | int  |  0  | initialization time (60) |
| MHZ19_AUTO_CALIB | bool |  0  | set auto-calibration (False) |

Open-Meteo
----------

| Name | Type | O/M | Description |
|---|---|-----|---|
| METEO_LATITUDE |float |  O  | Default: 48.6967 |
| METEO_LONGITUDE |float |  O  | Default: 13.4631 |
| METEO_PROPERTIES  | str  |  O  | properties for display |
| | | | ("t h ps code w_speed w_dir r") |

Data provided by <https://open-meteo.com> ("current weather").
Note that the default latitude/longitude are just somewhere, so
these values are technically optional, but should be treated as
mandatory nevertheless.

PMS5003
-------

| Name | Type | O/M | Description |
|---|---|-----|---|
| PMS5003_RETRIES | int  |  O  | retry reads (3) |
| PMS5003_PROPERTIES | str  |  O  | properties for display |
| | | | ("p03 p10 p25") |
| PMS5003_PN_FACTOR | float|  O  | factor for particle count |
| | | | (0.01) |

Available properties:

  - `pm<x>`: mass concentration of particles, measured in µg/m³ 
     x = 10, 25, 100 (pm10: mass concentration PM1.0 etc.)
  - `pn<x>`: number concentration of particles measured in particles/cm³ 
     x = 03, 05, 10, 25, 50, 100

The default value of `PMS5003_PN_FACTOR` converts the raw count per
0.1L to particles per cm³.

Note that particles larger than 2.5µm are *estimated* and not
measured.  The device will therefore not necessarely detect the
correct concentrations of certain pollutants, e.g. pollen or heavy
dust.

SCD40, SCD41
------------

| Name | Type | O/M | Description |
|---|---|-----|---|
| SCD4X_SAMPLES | int  |  O  | number of samples (2) |
| SCD4X_INTERVAL | int  |  O  | sampling-interval (5) |
| SCD4X_TIMEOUT | int  |  O  | timeout waiting for data (10) |
| SCD4X_DISCARD | bool |  O  | only keep last readout (True) |
| SCD4X_PROPERTIES  | str  |  O  | properties for display ("c t h") |

The SCD4x-sensors give better results with multiple samples. Normally,
only the last sample is saved to CSV, the others are discarded. For
testing purposes, this behaviour can be change with `SCD4X_DISCARD`.

Periodic measurement on SCD4x should return data every five seconds.
After `SCD4X_TIMEOUT` seconds the sensor-wrapper will give up. The
default should be ok.

If a measurement from a BME280 or BMP280 is available, the pressure
value is used to configure the ambient pressure of the SCD4x. The
sensors within the `SENSORS`-configuration variable should therefore
be ordered correctly, i.e. first the BMx280, then the SCD4x.

SEN6X
-----

| Name | Type | O/M | Description |
|---|---|-----|---|
| SEN6X_SAMPLES | int  |  O  | number of samples (2) |
| SEN6X_INTERVAL | int  |  O  | sampling-interval (5) |
| SEN6X_TIMEOUT | int  |  O  | timeout waiting for data (5) |
| SEN6X_DISCARD | bool |  O  | only keep last readout (True) |
| SEN6X_PROPERTIES | str  |  O  | properties for display (c t h) |
| SEN6X_AUTO_CALIBRATE | bool |  O  | auto-calibrate CO2 (False) |
| SEN6X_TEMP_OFFSET | [f,f]|  O  | offset and slope (see datasheet) |
| ALTITUDE_AT_LOCATION | int  |  O  | altitude in meters (540) |

Sensirion's SEN6x sensors are a family of compound sensors for
temperature, humidity, particle and various gases. Currently, the
SEN66 is the only available and supported sensor.

Available properties:

  - `t`: temperature
  - `h`: humidity
  - `c`: CO2
  - `voc`: volatile organic compount index
  - `nox`: NO index
  - `pm<x>`: mass concentration of particles, measured in µg/m³ 
     x = 10, 25, 40, 100 (pm10: mass concentration PM1.0 etc.)
  - `pn<x>`: number concentration of particles measured in particles/cm³ 
     x = 10, 25, 40, 100

The Sen6x-sensors give better results with multiple samples. Normally,
only the last sample is saved to CSV, the others are discarded. For
testing purposes, this behaviour can be change with `SEN6X_DISCARD`.

Periodic measurements on Sen6x should return data every second.
After `SEN6X_TIMEOUT` seconds the sensor-wrapper will give up. The
default should be ok.

If a measurement from a BME280 or BMP280 is available, the pressure
value is used to configure the ambient pressure of the Sen6x. The
sensors within the `SENSORS`-configuration variable should therefore
be ordered correctly, i.e. first the BMx280, then the Sen6x.

SHT45
-----

| Name | Type | O/M | Description |
|---|---|-----|---|
| SHT45_PROPERTIES | str  |  O  | properties for display |
| | | | ("t h") |

TM_POWER
--------

| Name | Type  | O/M | Description |
|---|---|-----|---|
| TM_POWER_PROPERTIES | str |  O  | properties for display |
| | | | ("P V C") |
| TM_POWER_HOSTS | list  |  O  | list of hosts or IPs |
| TM_POWER_URL | str |  O  | query URL (see below) |
| TM_POWER_TIMEOUT | float |  O  | timeout for get-request (2) |

This sensor reads the status of one or more Tasmota smart (power)
plugs, returning power, voltage and current. Setting
`TM_POWER_PROPERTIES="P"` is recommended, since voltage is more
or less constant and current is `P/V`.

The default query URL is `http://<host_or_ip>/cm?cmnd=status%2010`.

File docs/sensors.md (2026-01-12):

Sensors
=======

This is a list of supported sensors. Some of these sensors are "pseudo-sensors"
in the sense that they are not linked to a physical device. The `ID`-sensor
is an example. It returns the configured ID of the logger.

The datalogger queries properties for every sensor listed in `SENSORS`
(see [configuration](./core_config_main.md)).

Every sensor-type has a unique type-code (called "dcode"). When you
add the pseudo-sensor "dcode" to the `SENSORS`-variable, this
pseudo-sensor will return a string containing all typecodes for all
configured sensors. With this string the data in each CSV-line is
self-documented and can be parsed later without knowledge of the
original configuration.

Please note that many of the Adafruit versions of the listed sensors
are fitted with an LED. For some sensors, this can be disabled by
cutting a track, but for others you just have to destroy them.

AHT20
-----

  - Measures temperature and humidity.
  - Status: implemented
  - dcode: `3`
  - I2C-Breakout: [Adafruit  4566](https://adafru.it/4566)
  - Address: 0x38
  - Guide: <https://learn.adafruit.com/adafruit-aht20>
  - CircuitPython-driver: <https://github.com/adafruit/Adafruit_CircuitPython_AHTx0>
  - [datasheet](https://cdn-learn.adafruit.com/assets/assets/000/091/676/original/AHT20-datasheet-2020-4-16.pdf?1591047915)

AM2301B
-------

  - Measures temperature and humidity (it is an AHT20 in an enclosure)
  - Status: implemented
  - dcode: `3`
  - I2C-Breakout: [Adafruit  5181](https://adafru.it/5181)
  - Address: 0x38
  - Guide: <https://learn.adafruit.com/adafruit-aht20>
  - CircuitPython-driver: <https://github.com/adafruit/Adafruit_CircuitPython_AHTx0>
  - [datasheet](https://cdn-shop.adafruit.com/product-files/5181/5181_AM2301B.pdf)
  - Note: Non-standard wiring:  
    Red: 3V3, Black: GND, White: SCL, Yellow: SDA

AM2320
------

  - Measures temperature and humidity
  - Status: implemented
  - dcode: `4`
  - I2C-Breakout: [Adafruit  3721](https://adafru.it/3721)
  - Address: 0x5C
  - Guide: <https://learn.adafruit.com/adafruit-am2320-temperature-humidity-i2c-sensor>
  - CircuitPython-driver: <https://github.com/adafruit/Adafruit_CircuitPython_AM2320>
  - [datasheet](https://cdn-shop.adafruit.com/product-files/3721/AM2320.pdf)
  - Notes: no-pullups! Pinout left to right (from front): : 3V3, SDA, GND, SCL

BATTERY
-------

  - Measures VSYS voltage
  - Status: implemented
  - dcode: `2`

BH1750
------

  - Measures Light
  - Status: implemented
  - dcode: `5`
  - I2C-Breakout: [Adafruit  4681](https://adafru.it/4681)
  - Address: 0x23 (default) or 0x5C (addr-pin high)
  - Guide: <https://learn.adafruit.com/adafruit-bh1750-ambient-light-sensor>
  - CircuitPython-driver: <https://github.com/adafruit/Adafruit_CircuitPython_BH1750>
  - [datasheet](https://www.mouser.com/datasheet/2/348/bh1750fvi-e-186247.pdf)

BME280
------

  - Measures temperature, humidity and pressure
  - Status: implemented
  - dcode: `6`
  - Breakouts: China or [Adafruit 2652](https://adafru.it/2652)
  - Address: 0x76 or 0x77
  - Guide: <https://learn.adafruit.com/adafruit-bme280-humidity-barometric-pressure-temperature-sensor-breakout>
  - CircuitPython-driver: <https://github.com/adafruit/Adafruit_CircuitPython_BME280>
  - [datasheet](https://cdn-learn.adafruit.com/assets/assets/000/115/588/original/bst-bme280-ds002.pdf?1664822559)
  - Note: Only I2C supported. Chinese breakouts often claim to be a BME280
    but are in fact only a BMP280.
  - Note: This sensor supports [sensor-specific configuration](./core_config_sensors.md)

BMP280
------

  - Measures temperature and pressure
  - Status: implemented
  - dcode: `7`
  - Breakouts: China or [Adafruit 2651](https://adafru.it/2651)
  - Address: 0x76 or 0x77
  - Guide: <https://learn.adafruit.com/adafruit-bmp280-barometric-pressure-plus-temperature-sensor-breakout/overview>
  - CircuitPython-driver: <https://github.com/adafruit/Adafruit_CircuitPython_BMP280>
  - [datasheet](http://www.adafruit.com/datasheets/BST-BMP280-DS001-11.pdf)
  - Note: Only I2C supported.
  - Note: This sensor supports [sensor-specific configuration](./core_config_sensors.md)

CPUTEMP
-------

  - Pseudo-sensor: returns the value of `microcontroller.cpu.temperature`
  - Status: implemented
  - dcode: `K`

DCODE
-----

  - Pseudo-sensor: returns configured sensors (data-code, see `src/sensors/dcode.py`)
  - Status: implemented
  - dcode: `1`

DS18B20
-------

  - Measures temperature
  - Status: implemented
  - dcode: `8`
  - Breakouts: IC [Adafruit 374](https://adafru.it/374) or shielded versions available
  - Address: n.a.
  - Guide: <https://learn.adafruit.com/using-ds18b20-temperature-sensor-with-circuitpython>>
  - CircuitPython-driver: <https://github.com/adafruit/Adafruit_CircuitPython_DS18X20>
  - [datasheet](https://cdn-shop.adafruit.com/datasheets/DS18B20.pdf)
  - Note: Uses the 1-wire protocol.

ENS160
------

  - Measures TVOC and calculates eCO2 and AQI ("air quality index")
  - Status: implemented
  - dcode: `9`
  - I2C-Breakouts:
      - [Adafruit  5606](https://adafru.it/5606)
      - [DFRobot SEN0515]()
  - Address: 0x53 (default) and 0x52
  - Guide: <https://learn.adafruit.com/adafruit-ens160-mox-gas-sensor>
  - CircuitPython-driver: <https://github.com/adafruit/Adafruit_CircuitPython_ENS160>
  - [datasheet](https://cdn-learn.adafruit.com/assets/assets/000/115/331/original/SC_001224_DS_1_ENS160_Datasheet_Rev_0_95-2258311.pdf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)
  - Note: Only I2C supported.
  - Note: This sensor supports [sensor-specific configuration](./core_config_sensors.md)

HDC302x
-------

  - Measures temperature and humidity.
  - Status: implemented
  - dcode: `M`
  - I2C-Breakout: [Adafruit  5989](https://adafru.it/5989)
  - Address: 0x44 (or 0x45-0x47)
  - Guide: <https://learn.adafruit.com/adafruit-hdc3021-precision-temperature-humidity-sensor>
  - CircuitPython-driver: <https://github.com/adafruit/Adafruit_CircuitPython_HDC302x>
  - [datasheet](https://cdn-learn.adafruit.com/assets/assets/000/131/097/original/hdc3021-q1.pdf?1720448563)

HTU31D
------

  - Measures temperature and humidity
  - Status: implemented
  - dcode: `A`
  - I2C-Breakout: [Adafruit  4832](https://adafru.it/4832)
  - Address: 0x40 or 0x41
  - Guide: n.a.
  - CircuitPython-driver: <https://github.com/adafruit/Adafruit_CircuitPython_HTU31D>
  - [datasheet](https://www.te.com/usa-en/product-CAT-HSC0007.datasheet.pdf)

ID
--

  - Pseudo-sensor: returns the ID of the logger (`LOGGER_ID` from the configuration)
  - Status: implemented
  - dcode: `0` (zero)

LM66200
-------

  - Power-source of LM66200 ideal diode (used in v3-datalogger hardware)
  - Status: implemented
  - dcode: `O` (oh)
  - Guide: n.a.
  - CircuitPython-driver: not required
  - [datasheet](https://www.ti.com/lit/ds/symlink/lm66200.pdf)
  - Note: values:
      - "U" - undefined
      - "E" - external (VIN1, JST-PH connector)
      - "I" - internal (VIN2, 2xAA battery connector)

LOCATION
--------

  - Pseudo-sensor: returns the location of the logger
    (`LOGGER_LOCATION` from the configuration)
  - Status: implemented
  - dcode: `J`

LTR-559
-------

  - Measures Light
  - Status: implemented
  - dcode: `B`
  - I2C-Breakout: [Pimoroni PIM413](https://shop.pimoroni.com/products/ltr-559-light-proximity-sensor-breakout)
  - Address: 0x23
  - Guide: n.a.
  - CircuitPython-driver: <https://github.com/pimoroni/Pimoroni_CircuitPython_LTR559>
  - [datasheet](https://optoelectronics.liteon.com/upload/download/DS86-2013-0003/LTR-559ALS-01_DS_V1.pdf)

MCP9808
-------

  - Measures temperature
  - Status: implemented
  - dcode: `C`
  - I2C-Breakout: [Adafruit  5027](https://adafru.it/5027)
  - Address: 0x18-0x20
  - Guide: <https://learn.adafruit.com/adafruit-mcp9808-precision-i2c-temperature-sensor-guide>
  - CircuitPython-driver: <https://github.com/adafruit/Adafruit_CircuitPython_MCP9808>
  - [datasheet](https://ww1.microchip.com/downloads/en/DeviceDoc/25095A.pdf)

METEO
-----

  - Queries meteological data from Open-Meteo
  - Status: implemented
  - dcode: `I`
  - Needs internet-access
  - Configuration: METEO_LATITUDE and METEO_LONGITUDE in `config.py`
  - [API-Documentation](https://open-meteo.com/en/docs) 

MHZ19
-----

  - Low-cost IR based CO2 sensor
  - Status: implemented
  - dcode: `L`
  - Uses UART
  - CircuitPython-driver: <https://github.com/bablokb/circuitpython-mhz19>
  - [datasheet](https://https://www.winsen-sensor.com/d/files/manual/mh-z19c.pdf)
  - Note: the device needs very stable Vdd in the range 4.9-5.1V
  - Note: UART-level is 3V3

PDM-Micro
---------

  - Measures noise
  - Status: implemented
  - dcode: `D`
  - Breakout: [Adafruit  3492](https://adafru.it/3492)
  - Address: n.a.
  - Guide: <http://learn.adafruit.com/adafruit-pdm-microphone-breakout/>
  - CircuitPython-driver: uses builtin module `audiobusio` and class `PDMin`.
  - [datasheet](https://cdn-learn.adafruit.com/assets/assets/000/049/977/original/MP34DT01-M.pdf)
  - Note: The sensor-PCB uses the similar [MP34DT05TR](https://www.st.com/resource/en/datasheet/mp34dt05-a.pdf)

PMS5003
-------

  - Measures particles
  - Status: implemented
  - dcode: `E`
  - Breakouts:
      - [Adafruit UART 3686](https://adafru.it/3686)
      - [Adafruit I2C 4632](https://adafru.it/4632)
      - [Pimoroni UART COM1707](https://shop.pimoroni.com/products/pms5003-particulate-matter-sensor-with-cable)
  - Address: 0x12 (I2C-version)
  - Guide: <https://learn.adafruit.com/pm25-air-quality-sensor>
  - CircuitPython-driver: <https://github.com/adafruit/Adafruit_CircuitPython_PM25>
  - [datasheet](https://cdn-shop.adafruit.com/product-files/3686/plantower-pms5003-manual_v2-3.pdf)
  - Note: UART-versions need 5V. The Adafruit I2C-version has an onboard regulator.

SCD40/SCD41
-----------

  - Measures CO2, temperature, humidity
  - Status: implemented
  - dcode: `F` and `G`
  - Breakouts:
      - [SCD40: Adafruit  5187](https://adafru.it/5187)
      - [SCD41: Adafruit  5190](https://adafru.it/5190)
      - [SCD40: M5Stack U103](https://shop.m5stack.com/products/co2-unit-with-temperature-and-humidity-sensor-scd40)
      - [SCD41: M5Stack U104](https://shop.m5stack.com/products/co2l-unit-with-temperature-and-humidity-sensor-scd41)
  - Address: 0x62
  - Guide: <https://learn.adafruit.com/adafruit-scd-40-and-scd-41>
  - CircuitPython-driver: <https://github.com/adafruit/Adafruit_CircuitPython_SCD4x>
  - [datasheet](https://www.sensirion.com/media/documents/48C4B7FB/64C134E7/Sensirion_SCD4x_Datasheet.pdf)
  - Note: This sensor supports [sensor-specific configuration](./core_config_sensors.md)
  - Note: See [tools](./tools.md) for a manual calibration-tool.

SEN66
-----

  - Measures temperature, humidity, CO2, NOx, VOC, PM
  - Status: implemented
  - dcode: `N`
  - Sensor: <https://www.digikey.de/de/products/detail/sensirion-ag/SEN66-SIN-T/25700945>
  - Address: 0x6B
  - Guide: n.a.
  - CircuitPython-driver: <https://github.com/adafruit/Adafruit_CircuitPython_SEN6x/>
  - [datasheet](https://sensirion.com/media/documents/FAFC548D/6731FFFA/Sensirion_Datasheet_SEN6x.pdf)
  - Note: This sensor supports [sensor-specific configuration](./core_config_sensors.md)
  - Note: See [tools](./tools.md) for a manual calibration-tool.

SHT45
-----

  - Measures temperature and humidity
  - Status: implemented
  - dcode: `H`
  - I2C-Breakout: [Adafruit  5665](https://adafru.it/5665)
  - Address: 0x44
  - Guide: <https://learn.adafruit.com/adafruit-sht40-temperature-humidity-sensor>
  - CircuitPython-driver: <https://github.com/adafruit/Adafruit_CircuitPython_SHT4x>
  - [datasheet](https://cdn-learn.adafruit.com/assets/assets/000/117/503/original/Datasheet_SHT4x.pdf?1673387912)

TM_POWER
--------

  - Queries power-data from (multiple) Tasmota smart-plugs
  - Status: implemented
  - dcode: `P`
  - Needs network-access
  - [API-Documentation](https://tasmota.github.io/docs/Commands/#power-monitoring)
  - Note: This sensor supports [sensor-specific configuration](./core_config_sensors.md)

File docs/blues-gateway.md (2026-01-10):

Installation, Configuration and Operation of the Blues-Gateway
==============================================================

Hardware
--------

The current hardware setup uses these components:

  - iLabs Challenger-RP2040-Lora
  - LoRa-antenna with u.FL connector
  - Blues Carrierboard F v1.3
  - Blues Notecard
  - LiPo-battery capable of providing 2A peak current
    (i.e. with at least 2000mAh capacity)
  - Solar-Panel with 6V

The Challenger, solar-panel and LiPo plug into the F-carrierboard. The
antenna plugs into the Challenger. **Since the F-carrierboard does not have
any over-discharge protection, the LiPo must provide the protection
itself!**

On the back of the F-carrierboard is a switch. Remove the protective
foil and use a very small screwdriver and push the switch to the right.



No additional hardware-setup is necessary for productive use.

Configuration
-------------

See [gateway configuration](./gateway_config.md).

Deployment
----------

The source of the software is in `src.gateway`. The `notecard`-API
libraries from Blues are in `src.misc/notecard`.

As usual, you have to provide two configuration files: `config.py` and
`log_config.py`. The recommended way of building and installing the
software is to use the Makefile in the toplevel directory:

    make gateway CONFIG=xxx.py LOG_CONFIG=yyy.py \
                 USER_LIBS=src.misc/notecard DEPLOY_TO=gw_challenger

This creates the directory `gw_challenger` with all the necessary
files. See [Software deployment](./deployment.md) for details about
the build-system. After the build is complete, copy all files below
`gw_challenger/` (or any other directory you use in the make-command)
to the device.

Operation
---------

The current implementation will run the gateway every day during a
number of *active windows*. The start of each active window has to be
defined in `config.py` using the `TIME_TABLE` configuration-variable
(see [main configuration](./core_config_main.md)). The duration of the
active windows must be configured with the variable `ON_DURATION` (in
minutes).

The active windows should match the time-table of the dataloggers. The
following setting will run the gateway from 07:00 - 17:00 every day
(i.e.  using a single active window):

    TIME_TABLE = [
      ((7,7,1),(0,0,1)),
      ((7,7,1),(0,0,1)),
      ((7,7,1),(0,0,1)),
      ((7,7,1),(0,0,1)),
      ((7,7,1),(0,0,1)),
      ((7,7,1),(0,0,1)),
      ((7,7,1),(0,0,1))
      ]
    ON_DURATION = 600   # 600 = 10*60

The very first startup of the gateway after a cold boot (i.e. after
power loss) will take a few minutes (up to 2 minutes here, to be
verified for Tanzania). Normal restarts are fast.

The notecard is a very low power-device (8µA) and should run 7x24. It
will wake up the Challenger on the F-carrierboard at the start of each
active window and will shutdown the device at the end of the active
window.

There are two methods of synchronisation of the data to the cloud
(i.e. to <https://nothub.io>):

  - synchronisation directly after receiving the data from the
    datalogger via LoRa
  - buffering the data on the notecard and synchronisation at the
    end of the active window

The modes are controlled by the variable `BLUES_SYNC_ACTION`:

  - `BLUES_SYNC_ACTION = True` will sync immediately
  - `BLUES_SYNC_ACTION = False` will sync after the end of the
    active window
  - `BLUES_SYNC_ACTION = None` will print to the log and discard the
    data (useful only during development)

The second option is for now the recommended option. It is more efficient
(less data-transfer, less power-consumption). The only reason *not* to
use the second option is the potential problem of a low-battery at
the end of the day (to be verified).

Power Requirements
------------------

Power consumption during the active window is dominated by the
Challenger listening for incoming LoRa-transmissions. At 3.6V, this
is about 44 mA. The following plot uses immediate sync, and the
node (datalogger) sends data every two minutes.



During sync with the cloud, the current rises to about 200 mA
with spikes up to 1200mA (for GPRS in Tanzania this is expected
to be much higher with up to 2A peak usage). The above plot (left side)
also demonstrates the additional current needed during a cold start.

In contrast, power consumption with delayed sync has this profile:



On the right side of the plot, the gatway shuts down at the end of
the active window. In this state, the gateway draws about 2mA.
This is mainly due to the Challenger - the onboard regulator does
not seem to shut down completely when the EN-pin of the feather
is pulled low.

The power requirement could be drastically reduced if the nodes would
only send once a day. In this case, the *active window* could be one
hour instead of ten hours. This needs changes in the way the nodes
operate and is planned for a future iteration. The gateway itself
already supports this alternative operation mode.

Solar Power Recommendations
---------------------------

Total energy-harvesting per day using a solar-panel should therefore
provide at least

    50 mAh * hours in receive-mode + 2mA * hours not in receive mode + ???mAh

The absolute term on the right side of the equation is for the final
sync to the cloud and depends on the amount of data sent by the nodes.
This has to be evaluated emperically.

So a typical 2W-panel (6V/330mA peak) should run at least at a mean of
20% of its peak performance. If possible, a larger panel (e.g. 3.5W)
should be used. Note that the charging range of the F-carrierboard is
3.94V-7.18V, so panels with other voltages (e.g. 5V) can be used as
long as they are in this range.

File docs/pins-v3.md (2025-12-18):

Pins
====

Reserved Pins on Raspberry Pi Pico
----------------------------------

Note that the default I2C-bus is I2C1. The UART-header could also
be used for I2C0.

If LoRa is not used, the LoRa pins GP12/GP13 also provide I2C0.

| | Pin  | Pin  | |
|---|---|---|---|
| UART-TX / I2C0-SDA  | GP0  | VBUS |
| UART-RX / I2C0-SCL  | GP1  | VSYS |
| | GND  | GND  |
| I2C1-SDA (RTC) | GP2  | EN |
| I2C1-SCL (RTC) | GP3  | 3V3  |
| DONE | GP4  | VREF |
| Front-LED | GP5  | GP28 | PS_STATUS LM66200
| | GND  | GND  |
| SWB | GP6  | GP27 | ext (ADC/1-Wire)
| LoRa-RST | GP7  | GP26 | Display Busy
| SWA | GP8  | RUN  | RUN
| LoRa-CS | GP9  | GP22 | SD-CS
| | GND  | GND  |
| SCLK1, LoRa | GP10 | GP21 | Display Reset
| MOSI1, LoRa | GP11 | GP20 | Display D/C
| MISO1, LoRa | GP12 | GP19 | MOSI0 (Display, SD-Card)
| SWC | GP13 | GP18 | SCLK0 (Display, SD-Card)
| | GND  | GND  |
| n.a. | GP14 | GP17 | Display CS
| LoRa-DIO0 | GP15 | GP16 | MISO0 (Display, SD-Card)

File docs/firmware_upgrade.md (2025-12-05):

Upgrading the CircuitPython Firmware
====================================

Standard Procedure
------------------

Entering the firmware update mode works by keeping the boot-button
of the Pico pressed while plugging in the Pico to the host computer.
As an alternative, if CircuitPython is already installed, double click
the reset button - this might need some retries to get the speed of
the double-click right.

After the Pico is in firmware update mode, you should have a new drive
(Windows) or device (Linux) with 128 MB. Follow the normal procedure
on how to [update
CircuitPython](https://learn.adafruit.com/welcome-to-circuitpython/installing-circuitpython).

If the standard procedure does not work, e.g. because the boot-button
is not exposed (i.e. within an enclosure) and the double-click trick
does not work, use the method in the next section.

Procedure for Assembled Dataloggers
-----------------------------------

Assembled dataloggers don't expose the boot-button. To enter firmware
upgrade mode, use the following steps:

If the device is still running CircuitPython 8.0.5:

  - switch to the branch 8.0.5 of the datalogger repository
    (`git switch 8.0.5`)
  - build and deploy the newest version of the datalogger software. This
    version is still for 8.0.5-systems.
  - update the datalogger software on the device

When done:

  - **restart the device while keeping button C pressed**
  - the device will boot into (C=CircuitPython) firmware update mode
  - once in firmware update mode, follow the standard procedure to
    update the firmware
  - switch back to the main branch of the datalogger repository
    (git switch main)
  - build and deploy the newest version of the datalogger software. This
    is now the version for 9.2.x-systems.
  - update the datalogger software on the device
  - you should now have both a 9.2.x CircuitPython firmware and the
    application code compiled for 9.2.x

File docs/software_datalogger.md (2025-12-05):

Application-Firmware
====================

Overview
--------

The application firmware of the datalogger is implemented in CircuitPython.
The sources are in the subdirectory `src` and below.

The program is a framework with these main blocks:

  - setup of the base hardware (including RTC, display, sd-card)
  - configuration of the [sensors](./sensors.md)
  - data-collection
  - execution of post-collection [*tasks*](./tasks.md)
    (e.g. save to sd, update display)
  - configuration of next wake-up alarm
  - signal shutdown to the power management circuit

The typical run-mode of the datalogger is called "strobe-mode": 

  - the power management of the datalogger-pcb turns the Pico on
  - the application firmware runs
  - power is turned off again

This mode is energy efficient and allows the operation on a pair of
AA batteries for month.

Architecture
------------

Besides the basic setup of the hardware, the program runs in two phases:

  - collect data from every configured [sensor](./sensors.md)
  - execution of post-collection tasks

The configuration file `config.py` will drive these phases. See
[configuration](./configuration.md) for details on configuration.

Every [sensor](./sensors.md) needs a simple wrapper that interfaces to
the respective driver-library, reads the values and updates the
data. Adding new sensors is simple, just add a python-file for the
sensor in the directory `src/sensors`. One of the existing files can
be used as a blueprint.

[Tasks](./tasks.md) are similar. Every task needs a wrapper in `src/tasks`.

Installation
------------

First step is to install CircuitPython on the board. The currently
tested and supported version is 9.2.9. **Although CircuitPython 10.0.x
and later works, it is not recommended** due to performance reasons.

Sources:

  - If you have a Pico, install  
    <https://circuitpython.org/board/raspberry_pi_pico/>
  - If you have a Pico W, install  
    <https://circuitpython.org/board/raspberry_pi_pico_w/>

Notes:

  - Newer boards (Pico2 and Pico2-W) should also work
  - If you want to upgrade the CircuitPython software,
    please read the [firmware upgrade instructions](./firmware_upgrade.md).

After installation of CP and a power-cycle, mount the device if not done
automatically by your operating system. Then follow the instructions
within [Software deployment](./deployment.md).

Updates
-------

The datalogger program will usually run only for a very short time. This
makes updates difficult. To enter update mode, the recommended actions are:

  - on a v1-pcb with attached batteries: remove the jumper
  - connect the device to your computer
  - if the device does not start automatically, turn it on
    using the "on"-button
  - wait a few seconds
  - hit CTRL-C

If you are connected with a serial console (e.g. from Thonny) the system
should now enter the REPL.

Next Reading
------------

  - [Configuration](./configuration.md)
  - [Initial setup of the RTC](./rtc_setup.md) 
  - [Administration mode](./admin_mode.md)

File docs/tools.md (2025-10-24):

Tools
=====

A number of tools (python scripts) are available in `tools`. They are
copied to the device and can be started from the REPL or on a computer.

show_sd.py
----------

This tool allows REPL access to CSV-files and logs (if the SD is
configured as the logger-target).

From the REPL, run:

    from tools import show_sd

and follow the instructions. Basically, you can run the following functions:

  - show_sd.dump_file(filename)
  - show_sd.del_file(filename)

scd4x_config.py
---------------

This is a configuration tool for SCD40/SCD41 sensors.

From the REPL, run:

    from tools import scd4x_config

and follow the instructions. The import configures I2C and defines the
function

    scd4x_config.run(altitude=None,persist=False,duration=10,ppm=418,temp_offset=4)

Running this function, e.g. with

    scd4x_config.run(altitude=525,persist=True,temp_offset=8)

will set the altitude and the temperature offset. The latter has to be
determined emperically (the sensor default builtin value is 4).

sen6x_config.py
---------------

This is a configuration tool for the SEN66 sensor.

From the REPL, run:

    from tools import sen6x_config

and follow the instructions. The import configures I2C and defines the
function

    sen6x_config.run(duration=60,ppm=None,persist=False)

Running this function, e.g. with

    sen6x_config.run(ppm=418,persist=True)

will set the baseline co2 concentration to 418ppm.

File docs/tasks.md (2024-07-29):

Post Datacollection Tasks
=========================

After datacollection, an arbitrary number of tasks can be
executed. This is [configured](./core_config_main.md) with the
variable `TASKS` (a blank delimited list of tasks).

Each task needs a wrapper file in `src/tasks` and must define a
`run()`-method.  To create a new task, use one of the existing files
as a template.

Some tasks have task-specific configuration options. See [task
configuration](./core_config_tasks.md) for details.

Available and planned tasks are listed below.

dump_data
---------

This will write sensor-data either to the log or to the serial console.
Note that this task is not really useful in a productive environment, but
is useful for testing.

save_data
--------- 

This task writes the collected sensor data to the configured CSV-file.
Downloading of CSV-files is possible using [administration
mode](./admin_mode.md) or with a [script](./tools.md) started from the
REPL.

update_display
--------------

Update the main main display with sensor measurement data. This task
should run after "save_data" and "send_lora", since it also displays
the status of SD-card writes and transmissions.

update_oled
-----------

Update an attached OLED-display with basic status information and at most
two lines of measurement-data.

This task will only work for setups without main display. It is a diagnostic
task that allows to temporarily plug in an OLED-I2C display, start the
system and see the status. In normal productive environments running in
strobe mode, the display will only be powered for a short time, but that
should be enough to verify the status.

For systems running in continuous mode, this task can be used to update a
permanently attached OLED.

send_lora
---------

Send collected sensor-data to the LoRa-gateway. The data-format is
the same as the data written to the CSV-file with task "save_data".

send_udp
--------

Same as "send_lora", but send data via UDP to a configured target
host/port.

A sample implementation of an UDP gateway is available in
`tools/udp_gateway.py`.

send_ble_nus
------------

**Planned, but not implemented**

Same as "send_lora", but send data via BLE Nordic UART service. This
task does not work on devices without BLE support like the Pico-W.

send_mqtt
---------

**Not planned, but PR is welcome**

Same as "send_lora", but send data via MQTT.

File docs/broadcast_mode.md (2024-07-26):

Broadcast Mode
==============

Overview
--------

Broadcast mode supports the initial deployment of a datalogger. This
mode sends messages to the gateway using LoRa. The gateway echos these
messages with added information regarding the signal strength, thus
enabling an optimized orientation of the datalogger and it's antenna.

Prerequisites
-------------

Broadcast mode needs at least the gateway to be up and running.

To fully utilize the broadcast-mode, you should

  - plug in an OLED-display (SSD1306 128x64 or 128x32) into one
    of the free I2C-ports
  - add `HAVE_OLED=xxx` to `config.py` (see task "update_oled" in
[task-configuration](./core_config_tasks.md for details).

Starting Broadcast Mode
-----------------------

Broadcast mode can only be entered during start or reset. When the
device is powered down, keep holding SW-B and shortly press the on-button.
If running , keep holding SW-B and shortly press the reset-button.

Keep pressing the SW-B button until broadcast-mode is up and running. In
this state, you can see the state on the OLED-display. On a v2-system with
sensor-PCB, the red-LED is full on.

For the v1 datalogger-PCB, the SW-B button is available from the display.
For the v2-PCB, the SW-B button is on the sensor-PCB.

Using Broadcast Mode
--------------------

When in broadcast mode, the program queries the current time from the
gateway and updates the time on the device. After the time is updated,
the program switches to a send-receive scheme within a loop.

With an OLED-display, a new test-packet is sent every 10 seconds (this
is customizable with `BROADCAST_INT=xxx` in `config.py`). Without the
OLED, the interval is at least 60 seconds to protect the e-ink display.

On the display, the following information is available:

  - LoRa-node and Logger-ID
  - SNR (signal to noise ratio) and RSSI
    (Received Signal Strength Indication)
  - count of successful packets vs. total packets
  - RTT (round trip time - only available on the 128x64 OLED)
  - current time (only available on the 128x64 OLED)

Now the location and antenna can be optimized for maximal signal strength.

The range of RSSI is from `-120dBm` (weak) to `-30dBm` (strong). SNR
values are between `-20dB` to `+10dB`.

Absolute values are not really relevant. More important is a reliable
send-receive roundtrip as indicated by the count-number.

Stopping Broadcast Mode
-----------------------

To stop the broadcast mode, remove the OLED-display and press the reset
button. In addition to prevent excessive current draw, the system will
automatically trigger a reset after a maximum duration of xxx minutes (TBD).

Current draw
------------

Note that broadcast-mode drains the battery fast and therefore should not
be kept running on batteries longer than necessary.

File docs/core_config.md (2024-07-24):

Core Configuration
==================

Overview
--------

The complete configuration of the datalogger engine is within the file
`src/config.py`. This file is listed in `.gitignore` and not synchronized
with Github. The template file `src/config_template.py` serves as a
starting point for your own `config.py`.

Since the path to `config.py` can be passed to the makefile, it can
be maintained out-of-tree. See [deployment](./deployment.md) for details.

Configuration variables can be divided into a number of realms:

  - **main**: all variables of the datacollection-engine
  - **sensors**: variables specific to individual [sensors](./sensors.md)
  - **tasks**: variables specific to individual [tasks](./tasks.md)
  - **broadcast**: variables specific to the [broadcast mode](./broadcast_mode.md)

Most variables have sensible defaults and can be omitted from
the configuration. But some are mandatory, e.g. the selection of
sensors and tasks.

Variables by Realm
------------------

  - [main](./core_config_main.md)
  - [sensors](./core_config_sensors.md)
  - [tasks](./core_config_tasks.md)
  - [broadcast](./core_config_broadcast.md)

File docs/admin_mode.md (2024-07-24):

Admin-Mode
==========

Overview
--------

Administration mode supports the following tasks:

  - download and update of the base configuration file `config.py`
  - download and delete of the logfile (if logging to sd-card is enabled)
  - download and delete of csv-files with sensor-measurements
  - set the time of the device

To enter the administration mode, use the steps outlined below. Leaving
the administration mode needs a hard reset using the reset-button.

Configuration
-------------

Various aspects of the admin-mode can be configured. The optional
file `ap_config.py` can be used to override settings. See
[AP configuration](./ap_config.md) for details.

Start Admin-Mode
----------------

Administration mode can only be entered during start or reset. When the
device is powered down, keep holding SW-A and shortly press the on-button.
If running (e.g. in continuous mode), keep holding SW-A and shortly press
the reset-button.

Keep pressing the SW-A button until admin-mode is up and running. In
this state, you can see the state on the display. On a v2-system with
sensor-PCB, the red-LED is full on.

For the v1 datalogger-PCB, the SW-A button is available from the display.
For the v2-PCB, the SW-A button is on the sensor-PCB.

Using the Admin-Mode
--------------------

Admin-mode creates a dedicated WLAN-network with the SSID as
configured in `ap_config.py` (defaults to `datalogger`). Connect your
browser to the IP of the access-point (usually `192.168.4.1`).

The interface is responsive and should be simple to use from desktop
or mobile systems.

Critical functions (i.e. upload of a new `config.py` or the manual
configuration of `config.py`) is disabled on low battery.

Stop Admin-Mode
---------------

Admin-mode must be stopped with a hard-reset, e.g. a power-cycle or
pressing the reset button.

Current draw
------------

Note that admin-mode drains the battery fast and therefore should not
be kept running on batteries longer than necessary.

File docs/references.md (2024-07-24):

Links
=====

This is a collection of links to products, datasheets, documentation and so on.

Datasheets for hardware used in conjunction with the board
----------------------------------------------------------

Required:

  - Raspberry Pi Pico or Pico W  
  (https://www.raspberrypi.com/products/raspberry-pi-pico/) or a
  pin-compatible device, such as the [Pico
  Lipo](https://shop.pimoroni.com/products/pimoroni-pico-lipo), is
  required for the operation of the board. Details on which device to
  chose are below.

Optional:

  - Adafruit RFM96W LoRa Radio Transceiver Breakout - 433 MHz - RadioFruit:  
  <https://www.adafruit.com/product/3073>
  This is optional. It is used for offloading data from the Pico to a
  'base station'. If you have public LoRa gateways where you are, you
  can also use one of those gateways.
  *Important:* We are selecting the 433 MHz version of this board, as
  this is the appropriate frequency for Tanzania. There is an 868 /
  915 MHz version available https://www.adafruit.com/product/3072.

  - Pico Inky Pack:  
  <https://shop.pimoroni.com/products/pico-inky-pack>
  Used to shows sensor data.

  - A micro-SD card

Datasheets for components used on the board
-------------------------------------------

Note: some of the components can be replaced with similar components but this might
need some rework on the pcb.

  - PCF8523: <https://www.nxp.com/docs/en/data-sheet/PCF8523.pdf>
  - SN74HC74: <https://www.ti.com/lit/ds/symlink/sn74hc74.pdf>
  - Micro-SD Card Reader/connector/socket:  
    <https://datasheet.lcsc.com/lcsc/1912111437_SHOU-HAN-TF-PUSH_C393941.pdf>
  - Oscillator:  
    <https://datasheet.lcsc.com/lcsc/1810171817_Seiko-Epson-Q13FC1350000400_C32346.pdf>
  - CR2032-Holder:  
    <https://datasheet.lcsc.com/lcsc/2012121836_MYOUNG-BS-08-B2AA001_C964777.pdf>

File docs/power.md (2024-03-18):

Power
=====

The board needs to be powered with one of the following options:

  - Two AA or AAA batteries
  - A LiPo battery

The RTC supports a CR2032 cell. This cell is not used for operation, it
just keeeps the internal state of the RTC when the standard batteries
are not connected. **Adding this coin-cell will shut down the RTC at
about 2.5V. This has no negative effect for LiPo-batteries which operate
above 3.0V, but for batteries, this severely limits the usable capacity.**

The power-management circuit has a leakage current of about 1.5µA during
"off-time" (at 3V).

Pico-W Current vs. Voltage
--------------------------

The Pico (-W) does not follow Ohm's law. It is more of a constant
energy-device. The consequence is that the current draw is higher for
lower voltages than for higher voltages. Also, the current ripple is
higher for low voltages, probably due to the internal DC-DC converters
that try to maintain the internal 1.8V and 3.3V voltages.

Some measurements (Pico-W):

| Voltage (V)| Idle Current (mA)|
|---|---|
| 3.2| 49|
| 3.0| 53|
| 2.8| 55|
| 2.6| 65|
| 2.4| 69|
| 2.2| 82|

Operation Voltage and Capacity
------------------------------

The Pico-W works down to 1.8V, even with attached sensors. The exact
threshold voltage probably depends on the current draw of the attached
sensors and maybe some other factors (e.g. sample variation). Since
alkalines are considered "empty" at about 0.9V, this means that the
datalogger can theoretically use the full capacity of the cells.

Current Measurements
--------------------

The test-setup uses the datalogger-v2 PCB with the standard sensor-PCB:

  - AHT20 (temperature/humidity)
  - BH1750 (light)
  - PDM-mic (noise)

The results for these sensors (including writing to the XTSD-card,
update of the e-ink display and LoRa transmission):



The spike occurs during LoRa transmission and uses a relative high
current for a very short time. This spike is not the driver of the
total energy consumption.

The average current during a measurment cycle depends on the voltage
of the batteries. Some figures (mean of 10 measured cycles):

  - 2.5V: 28.5mA (0.47mAh per cycle)
  - 3.0V: 21.1mA (0.35mAh per cycle)
  - 3.7V: 15.9mA (0.27mAh per cycle)

These figures include current during "on-time" and current during
"off-time" which is essentially neglegible.

Without the display update, the "on-time" is much shorter and the
energy per cycle is also much smaller:



  - 2.5V: 6.6mA (0.11mAh per cycle)

A typical power curve will show a fast initial discharge followed by
a linear phase and again a final steep voltage drop at the end of the
life of the batteries:



This curve was created with one measurement cycle per minute which is
not the target setup. It is expected that lower duty-cycles will give
the battery more time to recover.

Extrapolated Current Usage
--------------------------

Using the figures from above for 2.5V (mean battery voltage during lifetime)
we have:

Four measurements per hour for 10 hours, i.e. 40 measurements
per day will consume

  - 40 * 0.47mAh = 18,8mAh (with display)
  - 40 * 0.11mAh =  4,4mAh (without display)

With measurements from Monday to Friday this would result in a runtime
of about 28 weeks (with display) or 122 weeks (without display) under the
assumption of a total capacity of 2700mAh for two fresh AA-batteries.

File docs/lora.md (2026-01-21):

LoRa
====

Introduction
------------

This document describes the technical aspects of the LoRa-communication
between the dataloggers and the gateway.

Operation Modes
---------------

There are two types of operation:

  - **normal mode**: The dataloggers send data (usually after readout
    of the sensors), and the gateway acknowledges the receipt by
    sending back the content-length of the received package as a very
    minimal quality check. A more formal checking using CRCs is possible,
    but the integrity of the data is already checked on the transport
    level by hardware.
  - **broadcast mode**: Here the dataloggers sends data continuously,
    and the gateway echos packet-number and technical infos e.g. SNR
    (signal-to-noise ratio) and RSSI (received signal strength
    indicator). This mode is useful for optimizing the physical setup
    of antennas.

Data Protocol
-------------

Currently, the system supports three types of request "message-types":

  - **S**: This type of messages ("Single record") are used during
    normal operation mode.
  - **T**: "Time-request" messages query the current time of the
    gateway. At the
    beginning of the broadcast-mode, the datalogger sends a T-message
    and synchronizes
    it's time with the time of the gateway.
  - **B**: Payloads of type "Broadcast message" are used during
    broadcast-mode.

Requests are always sent from the dataloggers to the gateway. The
gateway will always answer with a response.

The payload of a request is always a string and is converted to bytes
during transfers.  Responses in contrast can be string or bytes. The
maximum length of a message is 252 bytes.

S-Message Format
----------------

The format of a S-message is:

    S,<csv-record>

The format of the response is a single byte with the length of the
csv-record:

    len(<csv-record>).to_bytes(1,'little')

T-Message Format
----------------

The format of a T-message is:

    T

The format of the response are four bytes with the current time of the
gateway:

    struct.pack("i",time.time())

B-Message Format
----------------

The format of a B-message is:

    B,<hex-coded timestamp>,<logger-id>,<package-nr>

The format of the response is:

    <package-nr>,<snr>,<rssi>

During broadcast mode, the datalogger increments the package-nr for
every message sent.  The SNR and RSSI are the values measured at the
gateway.

LoRa Quality-of-Service Configuration
-------------------------------------

LoRa supports a number of parameters to tune the physical
communication:

  - **spreading factor**: The SF is between 7 and 12. The higher the
    SF, the lower the data-transmission rate is. The value is
    logarithmic, so a spreading factor increase of one cuts the
    transmission rate by about a factor of 2 (see below for the exact
    formula).
  - **bandwidth**: The data-rate is linear in bandwidth. For technical
    reasons, the bandwidth is fixed at 125K.
  - **coding-rate**: The coding-rate is the amount of error-correction
    bits used for four bits of data. Coding rates range from 5 to 8,
    i.e. four bits and one to four correction-bits.

The application bit-rate is calculated as:

    bit-rate = SF*(4/CR)*BW/2**SF

The datalogger-software uses eight predefined combinations of SF/CR/BW
(configuration variable `LORA_QOS`). The following table lists the
settings, the bitrate, byte-rate and the theoretical transmission time
for 80 bytes:

| QOS| Settings | Bit-rate | Byte-rate |  t/80 |
|----|---|---|---|---|
| 0| SF7, CR5,BW125k | 5469 bps | 684 B/s | 0.12s |
| 1| SF7, CR7,BW125k | 3906 bps | 488 B/s | 0.17s |
| 2| SF8, CR7,BW125k | 2232 bps | 279 B/s | 0.29s |
| 3| SF9, CR7,BW125k | 1256 bps | 157 B/s | 0.51s |
| 4| SF10,CR5,BW125k |  977 bps | 122 B/s | 0.66s |
| 5| SF11,CR5,BW125k |  537 bps | 67 B/s | 1.20s |
| 6| SF11,CR8,BW125k |  336 bps | 42 B/s | 1.91s |
| 7| SF12,CR6,BW125k |  244 bps | 30 B/s | 2.67s |

The default value for `LORA_QOS` is `2`.

Measuring Signal Quality
------------------------

When in broadcast-mode, the system returns two values: "SNR" and
"RSSI" that describe signal quality.

"SNR" is the "Signal to Noise Ratio" and is the difference of the
signal compared to the background noise on a logarithmic scale. A SNR
above zero means that the signal is stronger than the noise. If the
signal is weaker than the noise, the signal is below the "noise floor"
and the SNR is below zero.

LoRa can demodulate signals below the noise floor:

| SNR | Quality
|---|---
| +10 dB | Excellent
| 0 dB | Just OK
| -10 dB | Weak and noisy
| -20 dB | Likely corrupted

"RSSI" in contrast is the "Receive Signal Strengh Indicator" and
measures the strength of the incoming signal. The RSSI-values are
always smaller than zero. Higher values (i.e. nearer to zero) are
better:

| RSSI | Quality
|---|---
| -30 dBm | Extremely strong
| -70 dBm | Good
| -90 dBm | Fair
|-120 dBm | Very weak
|-127 dBm | Barely detectable

In a lab-environment, a SNR of about 6.5dB and a RSSI of -65dBm is
typical. For practical setups, SNR and RSSI depend on many factors,
mainly on distance and a clear line-of-sight.

LoRaWAN Regional Parameters
---------------------------

Although the dataloggers don't use the LoRaWAN stack, the regional
parameters (especially available ISM bands) are of interest.

The most current version is available from
<https://resources.lora-alliance.org/technical-specifications>. The
current version as of this writing is
[RP002-1.0.5](https://resources.lora-alliance.org/technical-specifications/rp002-1-0-5-lorawan-regional-parameters).

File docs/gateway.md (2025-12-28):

Gateway
=======

The gateway is an optional central component for a network of dataloggers.
A gateway will *receive* data from the dataloggers (i.e. from downstream)
and *transmit* data to an upstream location. This second step is optional.

There are three components on every gateway:

  - The receiver: on the hardware side, this is a technology component
    like a LoRa-chip (or WLAN, BLE ...). On the software side, this is
    a class that implements a certain interface (e.g. a receive()-method).
  - The transmitter: this is similar to the receiver but used to send
    data upstream.
  - The gateway-MCU itself providing configuration and the framework for
    running the gateway.

Like dataloggers, the gateway can run continuously or in intervals. While
active, the gateway runs a receive-process loop. The receive part
queries the receiver for new packets, the process part runs a number of
configured tasks for the data (tranmitting is one task of many).

Implementations
---------------

One implementation uses [Blues](https://dev.blues.io). Blues provides
a LTE/GSM-chip in a special hardware package suitable for data-transfer into
the cloud.

A simpler implementation just runs on the normal datalogger hardware. In
this case, there is no upstreaming of data, but the data is collected
and stored centrally on the XTSD-card of the datalogger.

Software
--------

See [Application Firmware](./software_gateway.md) for details of the
software architecture, for building the firmware and for configuration.

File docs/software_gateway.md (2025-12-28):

Application-Firmware
====================

Overview
--------

The application firmware of the gateway is implemented in CircuitPython.
The sources are in the subdirectory `src.gateway` and below.

The program is a framework with these main blocks:

  - core gateway services
  - receiver: a component waiting for data-transmissions from the dataloggers
  - sender: a component sending data upstream

The gateway uses the same [build system](./deployment.md) as the core
datalogger (using targets `gateway` and `copy2gateway`).

Configuration of the gateway is detailed in [Gateway
Configuration](./gatway_config.md).

Architecture
------------

The core gateway service performs the following steps:

  - reads the configuration
  - create the receiver and sender components
  - initializes the hardware (RTC, SD, OLED if configured)
  - triggers setup for the receiver and sender
  - runs during the "active window" waiting for incoming data

The core polls the receiver for new data, passes the data on to the
sender and (optionally) saves the data to SD and updates an OLED-display.

Receivers
---------

Currently implemented receivers:

  - `LoraReceiver` (in `src.gateway/gw_rx_lora.py`)
  - `NoopReceiver` (in `src.gateway/gw_rx_noop.py`)  
    Does nothing, can be used as a template or for local operation, i.e.
    if the core services are sufficient for operation

Planned receivers:

  - `UDPReceiver`
  - `BLEReceiver`
  - `HttpReceiver`

Senders
-------

Currently implemented senders:

  - `NoopSender` (in `src.gateway/gw_tx_noop.py`)  
    Does nothing, can be used as a template or for local operation, i.e.
    if the core services are sufficient for operation
  - `BluesSender` (in `src.gateway/gw_tx_blues.py`)  
    Sends data to Blues.io via a Blues-notecard
  - `UDPSender` (in `src.gateway/gw_tx_udp.py`)  
    Sends data to a [central receiver](../src.receiver_service/Readme.md)
    using UDP
  - `TCPSender` (in `src.gateway/gw_tx_tcp.py`)  
    Sends data to a [central receiver](../src.receiver_service/Readme.md)
    using TCP

Planned senders:

  - `BLESender`
  - `HttpSender`
  - `MqttSender`

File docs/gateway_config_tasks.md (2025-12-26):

Gateway Tasks Specific Configuration
====================================

This document lists all available gateway tasks and the respective
special configuration variables.

bc_save_data
------------

This tasks is a post-broadcast task and allows the gateway to log broadcast
packets including technical data to a file for later analysis and for
documentation.

| Name | Type | O/M | Description |
|---|---|-----|---|
| BCAST_CSV_FILENAME | str  |  O  | filename for saved data |

The default value of `BCAST_CSV_FILENAME` is `"/sd/bcast_{GW_ID}_{ID}.csv"`,
so the default creates a distinct file for every datalogger.

bc_send_udp
-----------

A post-broadcast task to log broadcast packets to an UDP-host.

| Name | Type | O/M | Description |
|---|---|-----|---|
| BC_UDP_IP | IP |  M  | IP address of destination |
| BC_UDP_PORT | int  |  M  | port of destination |

bc_update_oled
--------------

This post-broadcast task updates a locally attached oled-display with
technical information about received broadcast packets. Besides the
normal oled-configuration, no special configuration is available.

buffer_data
-----------

This tasks writes data packets to a buffer file (`"/sd/tx_buffer.csv"`)
for later processing, typically during shutdown from other components.

save_data
---------

Write data packets to a CSV-file.

| Name | Type | O/M | Description |
|---|---|-----|---|
| CSV_FILENAME | str  |  O  | CSV filename. Details below.  |
| CSV_FIELDNR_ID | int  |  O  | field number of logger-id (1) |

For details about `CSV_FILENAME`, see the respective section of
[Main Configuration](./core_config_main.md). In the context of a
gateway, there is an additional placeholder available: `{GW_ID}`.

The task tries to extract the logger-id from the received csv-data
packet using `CS_FIELDNR_ID`. This allows to write a single csv-file
per logger. The default value of `CS_FIELDNR_ID=1` corresponds to
a SENSORS definition on the logger with `SENSORS="id ...."`.

tx_send
-------

Pass data packets to the transmitter plugin for further processing.
Used to send data to upstream destinations.

update_oled
-----------

Update a locally attached oled-display from the received data-packet.

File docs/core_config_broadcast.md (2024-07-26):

Configuration of Broadcast-Mode
===============================

Broadcast mode needs a few configuration variables in `config.py`.

| Name | Type | O/M | Description |
|---|---|-----|---|
| HAVE_OLED | str  |  O  | support I2C-OLED (default: None) |
| BROADCAST_INT | int  |  O  | broadcast-interval (10) |

For valid values of `HAVE_OLED`, see task "update_oled" in
[task-configuration](./core_config_tasks.md).

The `BROADCAST_INT` configures the interval of LoRa-messages sent to
the gateway-address. If no OLED is connected, this will fall back to
60s to protect the main (e-ink) display.

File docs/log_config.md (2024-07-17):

Log-Configuration
=================

The file `src/log_config.py` defines the destination of technical
log messages. Various options exist:

  - no output
  - output to the console
  - output to the file `messages.log` on the sd-card
  - output to UART-serial

The last option lets you monitor the system even when running on batteries.

In a stable environment the recommended setting is

    g_logger = Logger(None)

Logging to the console only makes sense during development with an attached
PC/Laptop. Logging to SD-card is ideal for the ex-post analysis of problems,
but consumes more energy.

Copy and adapt the file `src/log_config_template.py` to your needs.

Since the path to `log_config.py` can be passed to the makefile, it can
be maintained out-of-tree. See [deployment](deployment.md) for details.

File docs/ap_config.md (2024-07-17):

AP-Configuration
================

The administration mode provides a web-interface running with a dedicated
WLAN-SSID.

Various aspects of the web-interface can be configured. The optional
file `ap_config.py` can be used to override settings.

The file needs the following content:

    from wifi import AuthMode
    ap_config = {
      'debug': False,
      'cache': True,
      'ssid': 'datalogger',
      'password': '12345678',                      # ignored for wifi.AuthMode.OPEN
      'auth_modes': [AuthMode.WPA2, AuthMode.PSK], # [wifi.AuthMode.OPEN]
      'hostname': 'datalogger'                     # msdn hostname
    }

Changing `debug` to `True` and `cache` to `False` is only needed during
development. The current version of CircuitPython does not support
AP-mode in open-mode, i.e. you need to set a password of at least 8 chars.

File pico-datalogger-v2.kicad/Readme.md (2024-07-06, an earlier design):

KiCAD-Designfiles for Version 2 PCB
===================================

Here are the KiCAD (v6) design-files for the Datalogger-V2-PCB.

Schematic
---------



Layout
------



3D-Views
--------




Wiring Version 2.00 (Gray Buttons, no Rim)
------------------------------------------

  - Base PCB to sensor PCB: 1x8pin type B, 1x4pin type B
  - Base PCB to display: 1x8pin type A

Wiring Version 2.10 (Red Buttons, with Rim)
-------------------------------------------

  - Base PCB to sensor PCB: 2x8pin type B
  - Base PCB to display: 1x8pin type B

Wiring LoRa-Adapter and LoRa-PCB
--------------------------------

The LoRa-adapter is for the Adafruit LoRa breakouts. The LoRa-PCB is our
own PCB including the RFM-chip, SURS-connector and u.FL-connector.

Wiring is independent of the base-PCB version.

LoRa adapters:

  - **Base PCB to LoRa-adapter 1.00**: 1x8pin **type B**<br>
    (SURS and sockets on opposite sides of PCB)
  - **Base PCB to LoRa-adapter 1.20**: 1x8pin **type A**<br>
    (SURS and sockets on the same side of the PCB)
  - **Base PCB to LoRa-adapter 1.30**: 1x8pin **type B**<br>
    (SURS and sockets on the same side of the PCB)

LoRa-PCBs:

  - **Base PCB to LoRa-PCB 0.90**: 1x8pin type **type A**<br>
    (0.90 is the 868 MHz version)
  - **Base PCB to LoRa-PCB 1.00**: 1x8pin type **type A**<br>
    (1.00 is the first 433 MHz version, maybe never in production?!)
  - **Base PCB to LoRa-PCB 1.10**: 1x8pin type **type B**<br>
    (1.10 is the second 433 MHz version)

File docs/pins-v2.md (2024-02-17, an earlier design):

Pins
====

Reserved Pins on Raspberry Pi Pico
----------------------------------

Note that the default I2C-bus is I2C1. The UART-header could also
be used for I2C0.

If LoRa is not used, the LoRa pins GP12/GP13 also provide I2C0.

| | Pin  | Pin  | |
|---|---|---|---|
| UART-TX / I2C0-SDA  | GP0  | VBUS |
| UART-RX / I2C0-SCL  | GP1  | VSYS |
| | GND  | GND  |
| I2C1-SDA (RTC) | GP2  | EN |
| I2C1-SCL (RTC) | GP3  | 3V3  |
| DONE | GP4  | VREF |
| ext (PDM-CLK) | GP5  | GP28 | ext (PDM-DAT)
| | GND  | GND  |
| ext (SWD or LED) | GP6  | GP27 | ext (ADC/1-Wire)
| ext (SWA or LED) | GP7  | GP26 | Display Busy
| ext (MISO1, LoRa) | GP8  | RUN  | RUN
| ext (SWB or LED) | GP9  | GP22 | SD-CS
| | GND  | GND  |
| ext (SCLK1, LoRa) | GP10 | GP21 | Display Reset
| ext (MOSI1, LoRa) | GP11 | GP20 | Display D/C
| ext (LoRa-RST) | GP12 | GP19 | MOSI0 (Display, SD-Card)
| ext (LoRa-CS) | GP13 | GP18 | SCLK0 (Display, SD-Card)
| | GND  | GND  |
| ext (SWC or LED) | GP14 | GP17 | Display CS
| ext (LoRa-EN) | GP15 | GP16 | MISO0 (Display, SD-Card)

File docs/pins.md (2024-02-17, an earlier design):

Pins
====

Reserved Pins on Raspberry Pi Pico
----------------------------------

Note that the default I2C-bus is I2C1. The UART-header could also
be used for I2C0.

If LoRa is not used, the LoRa pins GP8/GP9 also provide I2C0.

| | Pin  | Pin  | |
|---|---|---|---|
| UART-TX / I2C0-SDA  | GP0  | VBUS |
| UART-RX / I2C0-SCL  | GP1  | VSYS |
| | GND  | GND  |
| I2C1-SDA (RTC) | GP2  | EN |
| I2C1-SCL (RTC) | GP3  | 3V3  |
| DONE | GP4  | VREF |
| I2S/PDM (BCLK/CLK)  | GP5  | GP28 | I2S/PDM (DOUT/DAT)
| | GND  | GND  |
| I2S (LRCL) | GP6  | GP27 | ADC ext
| LoRa-RST | GP7  | GP26 | Inky Busy
| MISO1 (LoRa) | GP8  | RUN  | Inky Run
| LoRa-CS | GP9  | GP22 | SD-CS
| | GND  | GND  |
| SCLK1 (LoRa) | GP10 | GP21 | Inky Reset
| MOSI1 (LoRa) | GP11 | GP20 | Inky D/C
| Inky SWA | GP12 | GP19 | MOSI0 (Inky, SD-Card)
| Inky SWB | GP13 | GP18 | SCLK0 (Inky, SD-Card)
| | GND  | GND  |
| Inky SWC | GP14 | GP17 | Inky CS
| LoRa-EN | GP15 | GP16 | MISO0 (Inky, SD-Card)

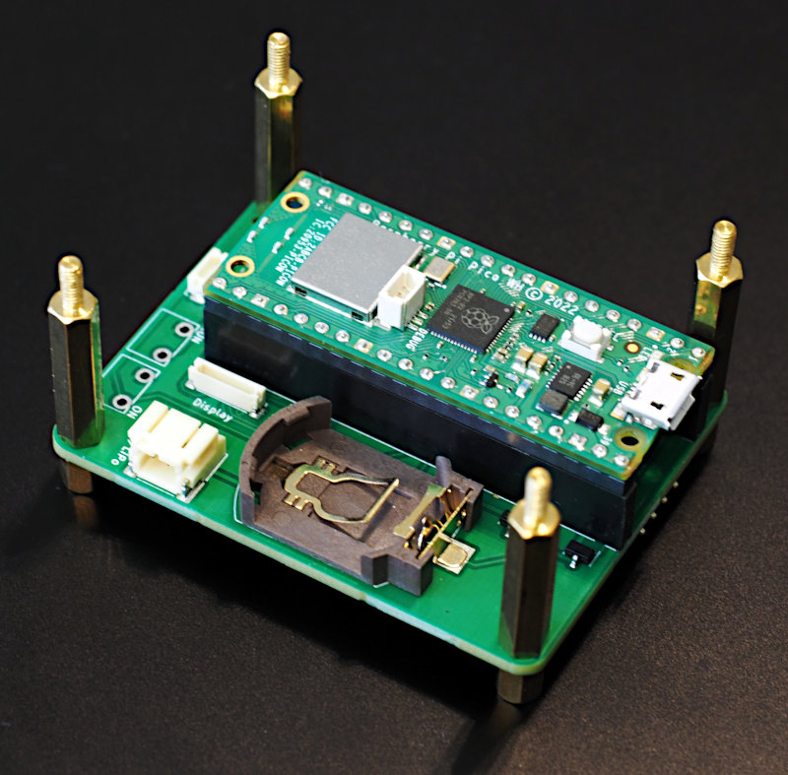
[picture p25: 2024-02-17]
docs/pcb-datalogger-v2.jpg

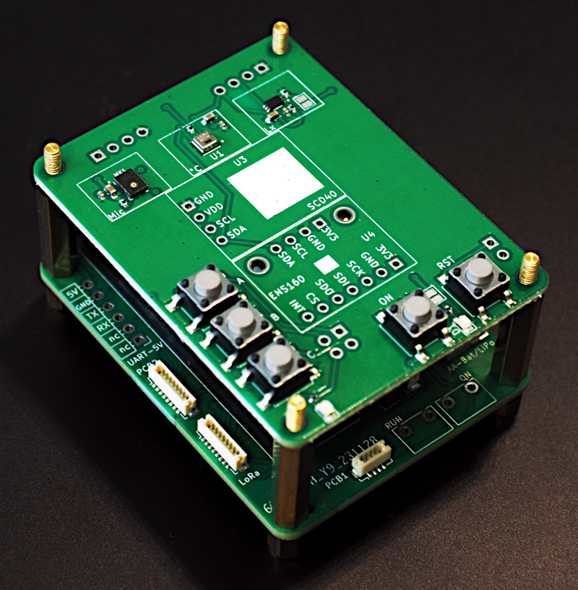
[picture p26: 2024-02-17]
docs/pcb-sensor.jpg

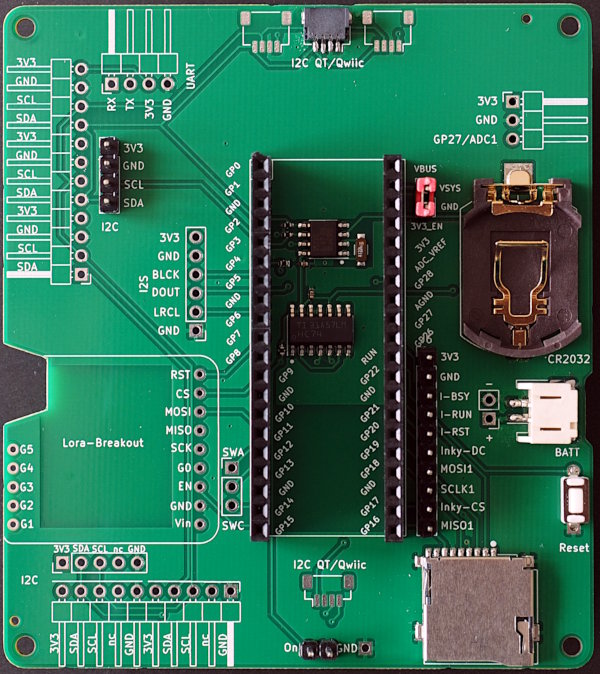
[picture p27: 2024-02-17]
docs/pcb-datalogger-v1-1.jpg

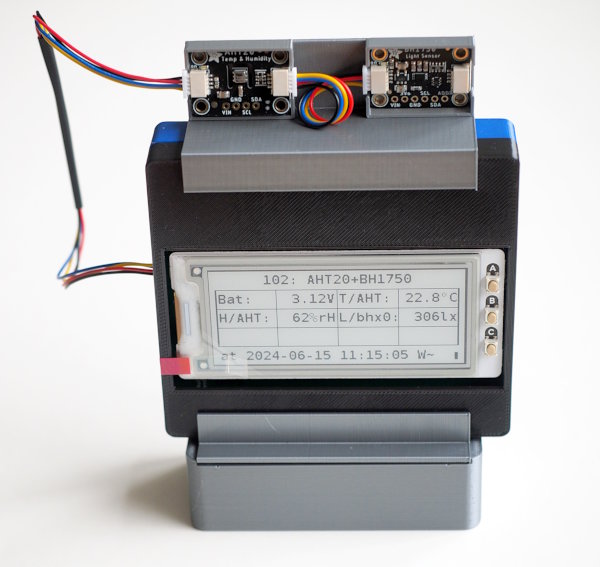
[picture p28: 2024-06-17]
docs/slim-case-v1-front-2.jpg

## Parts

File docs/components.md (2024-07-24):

Components
==========

Overview
--------

Currently, two iterations of the datalogger (v1, v2) exist. The v2 has
been produced in two sub-versions with slightly different PCB-sizes and
differences in connectors.

In addition to the dataloggers ("base-PCBs"), there is a sensor-PCB
(also in two iterations) and two adapter-PCBs for the display and
the LoRa breakout.

Unless otherwise noted, components are shared between iterations.

Microcontroller-Board
---------------------

The dataloggers use the Pico-W both for price and functionality. The
v1-datalogger will also work with the Pico but with limited functionality.

Basically, the software will also run with other MCUs as long as it is
supported by CircuitPython and as long as it provides the required
interfaces (this depends on the sensors and displays used).

Power-Management
----------------

The datalogger boards operate the MCU in on/off mode for low-power
consumption using the following components

  - PCF8523: This RTC will keep time and wakeup the system with it's
    programmable alarm
  - CR2032: backup coin-cell for the RTC
  - SN74HC74 (v1): Double D-type flip-flop driving the enable-pin of the Pico-W
  - 74LVC2G74 (v2): Single D-type flip-flop driving the p-mosfet
  - AO3401A (v2): P-channel mosfet

For details, see [Hardware Architecture](./hw_architecture.md).

Storage
-------

For data storage, the v1-PCB uses a micro-sd card socket. The v2-PCB has
an integrated flash chip emulating a micro-sd card (XTSD). This chip is
available in 1,2, 4 and 8GBit versions. The v2-PCB uses the 1GBit version,
since 128MB of storage are sufficient.

The XTSD-chip is more expensive than the card socket, but cheaper than
an additional micro sd card. Also, it is more robust (no mechanical parts).
From the viewpoint of power-efficiency, the XTSD-chip is also better
because mount-time is much shorter.

Drawback of the integrated SD-chip is the need for a special program
to readout the collected data. For this reason, the software provides
a web-interfaces ([admin mode](./admin_mode.md)).

Sensor-PCB
----------

The sensor-PCB has three sensors for noise, temperature/humidity and light:

  - MP34DT05TR: PDM microphone
  - AHT20: temperature and humidity
  - BH1750: light

Besides the sensors, the PCB has some control buttons and LEDs.

The sensor-PCB connects to the datalogger-v2 with JST-SURS cables (8-pin).
As an alternate, THT connections are also supported (starting with
v2-PCB 2.10).

A separate sensor-PCB has a few advantages:

  - no heat creap from other components
  - flexible assembly options (panel mount possible)
  - independent development of base-PCB and sensor-PCB

Adapters
--------

The datalogger v1 connects directly to a display (back to back with
stacking headers). Also, there are THT-connectors for the LoRa-breakout
from Adafruit.

The datalogger v2 has cable connectors (8-pin JST-SURS) instead. They
connect to small adapter-PCBs that have the SURS-connectors on one side
and THT connectors for the display and the LoRa.

LoRa
----

Dataloggers optionally connect to a central gateway using LoRa.
Currently, the software supports the LoRa-RFM9x breakout from
Adafruit. A special PCB with SURS-connector and builtin
RFM9x-chip is available.

Datasheets
----------

Note: some of the components can be replaced with similar components
but this might need some rework on the PCB.

- PCF8523: <https://www.nxp.com/docs/en/data-sheet/PCF8523.pdf>
- SN74HC74: <https://www.ti.com/lit/ds/symlink/sn74hc74.pdf>
- Micro-SD Card Reader/connector/socket: <https://datasheet.lcsc.com/lcsc/1912111437_SHOU-HAN-TF-PUSH_C393941.pdf>
- Oscillator: <https://datasheet.lcsc.com/lcsc/1810171817_Seiko-Epson-Q13FC1350000400_C32346.pdf>
- CR2032-Holder: <https://datasheet.lcsc.com/lcsc/2012121836_MYOUNG-BS-08-B2AA001_C964777.pdf>
- 74LVC2G74: <https://assets.nexperia.com/documents/data-sheet/74LVC2G74.pdf>
- AO3401A: <https://datasheet.lcsc.com/lcsc/1810171817_Alpha---Omega-Semicon-AO3401A_C15127.pdf>
- MP34DT05TR: https://www.st.com/resource/en/datasheet/mp34dt05-a.pdf
- AHT20: <https://cdn-learn.adafruit.com/assets/assets/000/091/676/original/AHT20-datasheet-2020-4-16.pdf?1591047915>
- BH1750: <https://www.mouser.com/datasheet/2/348/bh1750fvi-e-186247.pdf>

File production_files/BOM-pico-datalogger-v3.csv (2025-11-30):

Comment | Designator | Footprint | LCSC
1K | R11 | R_0402_1005Metric | C11702
SM06B-GHS-TB_LF_SN | J4 | JST_SM06B-GHS-TB_LF_SN | C133065
AO3401A | Q1,Q2 | SOT-23 | C15127
100nF | C1,C2,C3,C4 | C_0402_1005Metric | C1525
Conn_I2C1 | J11,J9 | JST_SH_SM04B-SRSS-TB_1x04-1MP_P1.00mm_Horizontal | C160404
10µF | C5,C6 | C_0603_1608Metric | C19702
JS202011JCQN | S1 | SW_JS202011JCQN | C221665
SW_Push | SW1,SW2,SW3,SW4,SW5 | SW_SPST_B3S-1000 | C221869
LED green | D1 | LED_0805_2012Metric | C2297
220Ω | R8 | R_0402_1005Metric | C25091
330Ω | R12 | R_0402_1005Metric | C25104
100K | R1,R6 | R_0402_1005Metric | C25741
10K | R10,R2,R3,R4,R5,R7,R9 | R_0402_1005Metric | C25744
PCF8523T | U2 | SOIC-8_3.9x4.9mm_P1.27mm | C2651516
74LVC2G74 | U1 | TSSOP-8_3x3mm_P0.65mm | C282355
RFM95W-868S2 | U7 | HOPERF_RFM9XW_SMD | C2844472
JST-PH2 Bat | J1 | JST_PH_S2B-PH-SM4-TB_1x02-1MP_P2.00mm_Horizontal | C295747
AHT20 | U6 | AHT20 | C3012622
Battery | BT2 | BatteryHolder_Keystone_2462_2xAA | C3029547
Crystal | Y1 | Crystal_SMD_3215-2Pin_3.2x1.5mm | C32346
LM66200DRLR | IC1 | LM66200DRLR | C3235556
Conn_Pico_Left | J2,J3 | PinSocket_1x20_P2.54mm_Vertical | C429947
Conn_Display | J6 | JST_SUR_BM08B-SURS-TF_1x08-1MP_P0.80mm_Vertical | C5143489
XTSD | U4 | XTSD | C7429710
LED red | D2 | LED_0805_2012Metric | C84256
Antenna_u.FL | AE1 | U.FL_Hirose_U.FL-R-SMT-1_Vertical | C88374
Coin_Cell | BT1 | CR2032_Holder | C964777

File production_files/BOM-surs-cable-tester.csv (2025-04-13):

Comment | Designator | Footprint | LCSC
SURS_1 | J1,J3 | JST_SUR_BM08B-SURS-TF_1x08-1MP_P0.80mm_Vertical | C5143489

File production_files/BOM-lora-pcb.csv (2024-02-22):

Comment | Designator | Footprint | LCSC
10µF | C1 | C_0603_1608Metric | C19702
RFM95W-868S2 | U1 | HOPERF_RFM9XW_SMD | C2844474
Conn_SUR | J1 | JST_SUR_BM08B-SURS-TF_1x08-1MP_P0.80mm_Vertical | C5143489
Antenna_u.FL | AE1 | U.FL_Hirose_U.FL-R-SMT-1_Vertical | C88374

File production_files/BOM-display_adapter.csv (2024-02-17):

Comment | Designator | Footprint | LCSC
Conn_Display | J1 | JST_SUR_BM08B-SURS-TF_1x08-1MP_P0.80mm_Vertical | C5143489
Inky_Left_1_20 | J2,J3 | PinHeader_1x20_P2.54mm_Vertical | C725952

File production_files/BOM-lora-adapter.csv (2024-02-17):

Comment | Designator | Footprint | LCSC
Conn_01x05 | J2 | PinSocket_1x05_P2.54mm_Vertical | C2897368
RFM9x_Lora_Breakout | U1 | PinSocket_1x09_P2.54mm_Vertical | C2897372
Conn_LoRa | J1 | JST_SUR_BM08B-SURS-TF_1x08-1MP_P0.80mm_Vertical | C5143489

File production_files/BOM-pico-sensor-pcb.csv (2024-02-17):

Comment | Designator | Footprint | LCSC
1K | R3,R5 | R_0402_1005Metric | C11702
100nF | C1,C3,C6 | C_0402_1005Metric | C1525
1µF | C5 | C_0603_1608Metric | C15849
Conn_I2C1 | J11 | JST_SH_SM04B-SRSS-TB_1x04-1MP_P1.00mm_Horizontal | C160404
10µF | C2,C4 | C_0603_1608Metric | C19702
SW_Push | SW1,SW2,SW3,SW4,SW5 | SW_SPST_B3S-1000 | C221869
LED green | D1 | LED_0805_2012Metric | C2297
220Ω | R1 | R_0402_1005Metric | C25091
330Ω | R6 | R_0402_1005Metric | C25104
10K | R2,R4,R7,R8 | R_0402_1005Metric | C25744
MP34DT05TR | MK1 | MP34DT05TR | C2688664
AHT20 | U1 | AHT20 | C3012622
Conn_PCB2 | J10,J7 | JST_SUR_BM08B-SURS-TF_1x08-1MP_P0.80mm_Vertical | C5143489
BH1750FVI-TR | U2 | BH1750 | C78960
LED red | D2 | LED_0805_2012Metric | C84256

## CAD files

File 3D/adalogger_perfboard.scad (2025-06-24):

//-----------------------------------------------------------------------------
// 3D-Model (OpenSCAD): enclosure for Adalogger on a perfboard.
//
// Author: Bernhard Bablok
// License: GPL3
//
// https://github.com/bablokb/pcb-pico-datalogger
//---------------------------------------------------------------------------

include <dimensions.scad>
include <BOSL2/std.scad>
include <pcb_holder.scad>

x_perfboard = 100.0;
y_perfboard =  50.2;
z_perfboard =   4.6;
z_support   =   4.6;

pcb_holder(x_pcb = x_perfboard,
           y_pcb = y_perfboard,
	        z_pcb = z_perfboard,
	        z_support = z_support,
          screws = [0,0,0,0]);

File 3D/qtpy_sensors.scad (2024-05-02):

// -----------------------------------------------------------------------------
// 3D-Model (OpenSCAD) shapes for datalogger.
//
// Two shapes for the datalogger:
//   - qtpy: for standard qtpy breakouts
//
// Author: Bernhard Bablok
// License: GPL3
//
// https://github.com/bablokb/pcb-pico-datalogger
// ---------------------------------------------------------------------------

include <dimensions.scad>
include <BOSL2/std.scad>

x_sensor     = 3.4;
y_sensor     = 3.4;
y_sensor_off = 1.27;

y_stemma     = 8;
z_stemma     = 3.1;
z_pcb        = 1.6;

x_qtpy      = 25.4  + gap;
y_qtpy      = 17.98 + gap;

// --- sensor   ----------------------------------------------------------------

module qtpy_breakout(z) {
  z_sensor = z_pcb + z_stemma;
  translate([0,0,z-fuzz]) {
    difference() {
      // wall around breakout
      rect_tube(size=[x_qtpy+2*w2,y_qtpy+2*w2],wall=w2,h=z_sensor,
                      anchor=BOTTOM+CENTER);
      // cutouts for Stemma/Qt
      translate([-x_qtpy/2-w2/2-fuzz,0,0])
          cuboid([w2+2*fuzz,y_stemma,z_sensor+fuzz],anchor=BOTTOM+CENTER);
      translate([+x_qtpy/2+w2/2-fuzz,0,0])
          cuboid([w2+2*fuzz,y_stemma,z_sensor+fuzz],anchor=BOTTOM+CENTER);
    }
    // wall around sensor
    translate([0,y_sensor_off,0])
         rect_tube(size=[x_sensor+2*w2,y_sensor+2*w2],wall=w2,h=z_stemma+2*fuzz,
                   anchor=BOTTOM+CENTER);
  }
}

// --- base for qtpy-formfactor   ----------------------------------------------

module qtpy_base(z) {
  cuboid([x_qtpy+2*w2,y_qtpy+2*w2,z],anchor=BOTTOM+CENTER);
}

// --- sensor in qtpy-formfactor   ---------------------------------------------

module qtpy_sensor(z) {
  difference() {
    // base plate
    qtpy_base(z);
    // cutout for sensor
    translate([0,y_sensor_off,-fuzz]) 
      cuboid([x_sensor,y_sensor,z+2*fuzz], anchor=BOTTOM+CENTER);
  }
  qtpy_breakout(z);
}

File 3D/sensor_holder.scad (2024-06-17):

// -----------------------------------------------------------------------------
// 3D-Model (OpenSCAD) case (bottom) for datalogger.
//
// Sensor-holder for the top of the printed case.
//
// Author: Bernhard Bablok
// License: GPL3
//
// https://github.com/bablokb/pcb-pico-datalogger
// ---------------------------------------------------------------------------

include <dimensions.scad>
include <dimensions_top.scad>
include <dimensions_bottom.scad>
include <dimensions_foot.scad>
include <shared_modules.scad>
include <BOSL2/std.scad>

// dimensions for standard adafruit-breakout   ---------------------------------

x_stemma     = 8;
z_stemma     = 3.2;
z_pcb        = 1.6;

b_breakout = 0.8;
x_breakout = 17.98 + gap;
y_breakout = 25.4  + gap;
z_breakout = z_pcb + z_stemma;

// --- standard-breakout from Adafruit   ---------------------------------------

module breakout() {
  cuboid([x_breakout+2*w2,y_breakout+2*w2,b_breakout],anchor=BOTTOM+CENTER);
  zmove(b_breakout-fuzz) difference() {
     // wall around breadboard
     rect_tube(size=[x_breakout+2*w2,y_breakout+2*w2],wall=w2,h=z_breakout,
                     anchor=BOTTOM+CENTER);
     // cutouts for Stemma/Qt
     translate([0,-y_breakout/2-w2/2-fuzz,0])
         cuboid([x_stemma,w2+2*fuzz,z_breakout+2*fuzz],anchor=BOTTOM+CENTER);
     translate([0,+y_breakout/2+w2/2+fuzz,0]) 
         cuboid([x_stemma,w2+2*fuzz,z_breakout+2*fuzz],anchor=BOTTOM+CENTER);
   }
}

// --- sensor-holder   -------------------------------------------------------

module sensor_holder() {
  // this is printed on the side, so change names
  height  = x_bat_holder - 3*gap;
  xlength = z_bat_holder;
  union() {
    // the cover (top)
    cuboid([w4,z_case+2*w4+gap,height],anchor=BOTTOM+CENTER);
     // holder for sensors
    ymove(z_case/2+0.5*w4+gap/2)
      xmove(xlength/2-fuzz)
        cuboid([x_breakout+2*w2,w4,height],anchor=BOTTOM+CENTER);
     // holder for main sensor-case
     ymove(z_case/2+0.5*w4+gap/2)
        xmove(-xlength/4+fuzz)
          cuboid([xlength/2,w4,height],anchor=BOTTOM+CENTER);
     ymove(-z_case/2-0.5*w4-gap/2)
      xmove(-xlength/4+fuzz)
        cuboid([xlength/2,w4,height],anchor=BOTTOM+CENTER);
  }
}

// --- top-level object   ----------------------------------------------------

sensor_holder();
//breakout();

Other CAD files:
3D/sensor_holder_2.scad
3D-stevenson/battery_cage.scad
3D-stevenson/battery_cage_dims.scad
3D-stevenson/dimensions.scad
3D-stevenson/dl_holder.scad
3D-stevenson/dl_holder_dims.scad
3D-stevenson/lora_pcb_holder.scad
3D-stevenson/main.scad
3D-stevenson/stevenson_holder.scad
3D-stevenson/stevenson_holder_dims.scad
3D/bmx280_holder.scad
3D/bottom.scad
3D/btn_pcb.scad
3D/case.scad
3D/dimensions.scad
3D/dimensions_bottom.scad
3D/dimensions_foot.scad
3D/dimensions_top.scad
3D/foot_base.scad
3D/m5_holder.scad
3D/pcb_holder.scad
3D/sensor_holder_3.scad
3D/shared_modules.scad
3D/top.scad

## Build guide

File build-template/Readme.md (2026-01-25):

Build Template
==============

This directory contains build template files for a datalogger (`DL1`)
and for a gateway (`GW`).

For building you need a unix-like environment with at least GNU-make.
Besides Linux, MacOS works. WSL ("Windows Subsystem for Linux")
probably also works, but hasn't been tested.

Preparation
-----------

After checkout, create a directory `configs.local` and copy the
**contents** of `build-template` to `configs.local`. *Never edit any
files from `build-template` directly*.

    git clone https://github.com/bablokb/pcb-pico-datalogger.git
    cd pcb-pico-datalogger
    mkdir configs.local
    cp -a build-template/* configs.local/

Build Configuration
-------------------

Edit the file `makevars.mk` in the folders `DL1` and `GW`. You will
have to set the correct PCB version (`PCB=v?`) and select the
log-configuration.

If you rename the folder names (or add additional folders for more
dataloggers) you must also edit the `makevars.mk` to match the
paths.

Logger and Gateway Configuration
--------------------------------

The folders `DL1` and `GW` contain example `config.py`-files for a
datalogger and for a gateway. Note that there are far more
configuration options, see the docs for a complete list. Most of them
are not necessary except for special cases.

Things you typically want to change are the identification strings,
the `SENSORS=` configuration and the LoRa-settings. Make sure that
`LORA_BASE_ADDR` for the datalogger matches `LORA_NODE_ADDR` from the
gateway. Also, the quality-of-service setting (`LORA_QOS`) must match
between logger and gateway.

Building the Datalogger
-----------------------

From the toplevel directory (`pcb-pico-datalogger`) run

    make default MAKEVARS=configs.local/DL1/makevars.mk

This will create a folder `DL1.local`. Copy everything **below** this
folder to the Pico of the datalogger.

*Re-building*, e.g. you only changed the configuration, just needs a

    make

To cleanup the build-environment, run

    make clean

Building the Gateway
--------------------

Before building the gateway, make sure to clean the build environment
as described above.

From the toplevel directory (`pcb-pico-datalogger`) run

    make gateway MAKEVARS=configs.local/GW/makevars.mk

This will create a folder `GW.local`. Copy everything **below** this
folder to the Pico of the gateway.

*Re-building*, e.g. you only changed the configuration, just needs a

    make

To cleanup the build-environment, run

    make clean

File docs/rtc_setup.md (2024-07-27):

Initial RTC-Setup
=================

Exact timestamps are important for datalogging. After startup, the
internal time (RTC) of the device is usually not valid. This is
checked by an heuristic algorithm. If the time seems invalid, the
program updates the time from the following sources if necessary:

  - external RTC (if available)
  - internet
  - (optional) saved wake up timestamp from the SD-card

Since updating the time from the internet is costly in terms of runtime
and current-draw (if possible at all), the external RTC should usually
be the source of the current time.

For the datalogger PCBs, the external RTC is powered by the battery/LiPo,
so after shutdown of the MCU this RTC keeps a valid time. In addition,
there is a backup battery (coin-cell) that should even keep the time if
the battery fails (but see below).

Nevertheless, the time of the external RTC has to be set once to a correct
value. There are a few options for this task.

Net-Update
----------

This needs access to a WLAN with correct [credentials](./secrets.md) and
the configuration of `NET_UPDATE = TRUE`. With this setup, the program
will update the external and internal RTCs automatically at startup. As
long as the external RTC is powered, this will be a one time task. So this
could be done before initial deployment in a suitable location with WLAN.

Thonny
------

Connecting to the MCU with Thonny usually sets the internal RTC to a
correct value. After startup, if the internal RTC-time is valid, this
time is propagated to the external RTC.

Administration Mode
-------------------

The time can be set manually using the [administration mode](admin_mode.md).
The main menu of the admin webpage offers an option to set the device
time to the browser time.

Broadcast Mode
--------------

Starting the device in [broadcast mode](./broadcast_mode.md) will set the
RTCs of the device from the time of the LoRa gateway.

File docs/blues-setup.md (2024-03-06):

Blues Setup
===========

Mainly follow setup quickstart-guide on <https://dev.blues.io>.

Hardware
--------

  - remove screw from carrier-board
  - insert notecard
  - reinsert screw
  - connect LTE and GPS antennas

Serial Test
-----------

  - connect with USB
  - use Chrome with webserial
  - send: {"req": "card.version"}
    ```> {"req":"card.version"}
    {
     "version": "notecard-5.3.1.16292",
     "device": "dev:860264054673802",
     "name": "Blues Wireless Notecard",
     "sku": "NOTE-WBEXW",
     "board": "5.13",
     "wifi": true,
     "cell": true,
     "gps": true,
     "api": 5,
     "body": {
       "org": "Blues Wireless",
       "product": "Notecard",
       "target": "u5",
       "version": "notecard-u5-5.3.1",
       "ver_major": 5,
       "ver_minor": 3,
       "ver_patch": 1,
       "ver_build": 16292,
       "built": "Sep 17 2023 20:32:47"
     }
    }```

Create Notehub-Account
----------------------

Goto <https://notehub.io/sign-up> and follow directions.

Create Notehub-Project
----------------------

After login to account, follow link and instructions.
This creates a "ProductUID".

ProductUID for development: de.gmx.bablokb:datalogger.dev

Link Notecard to ProductUID
---------------------------

Send

    > {"req":"hub.set", "product":"de.gmx.bablokb:datalogger.dev"}
    > {"req":"hub.sync"}
    > {"req":"hub.sync.status"}
    {
     "status": "idle {disconnected} {transport}",
     "mode": "{modem-on}",
     "requested": 29
    }
    > {"req":"hub.sync.status"}
      {
       "mode": "{modem-off}",
       "time": 1707124205,
       "completed": 16
      }

CircuitPython Libraries
-----------------------

Download from <https://github.com/blues/note-python>.

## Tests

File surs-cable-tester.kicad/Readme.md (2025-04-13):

SURS Cable Tester
=================

Here are the KiCAD (v7) design-files for the SURS cable tester.

Schematic
---------

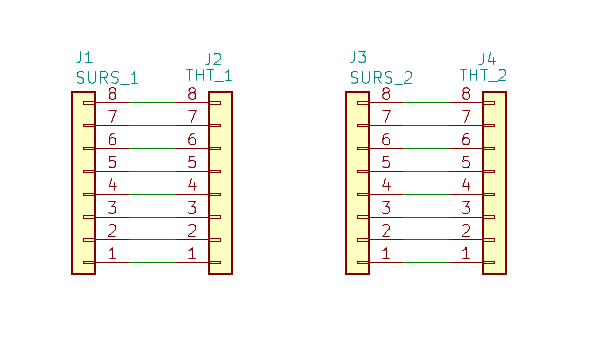
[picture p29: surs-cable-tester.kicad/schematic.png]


Layout
------

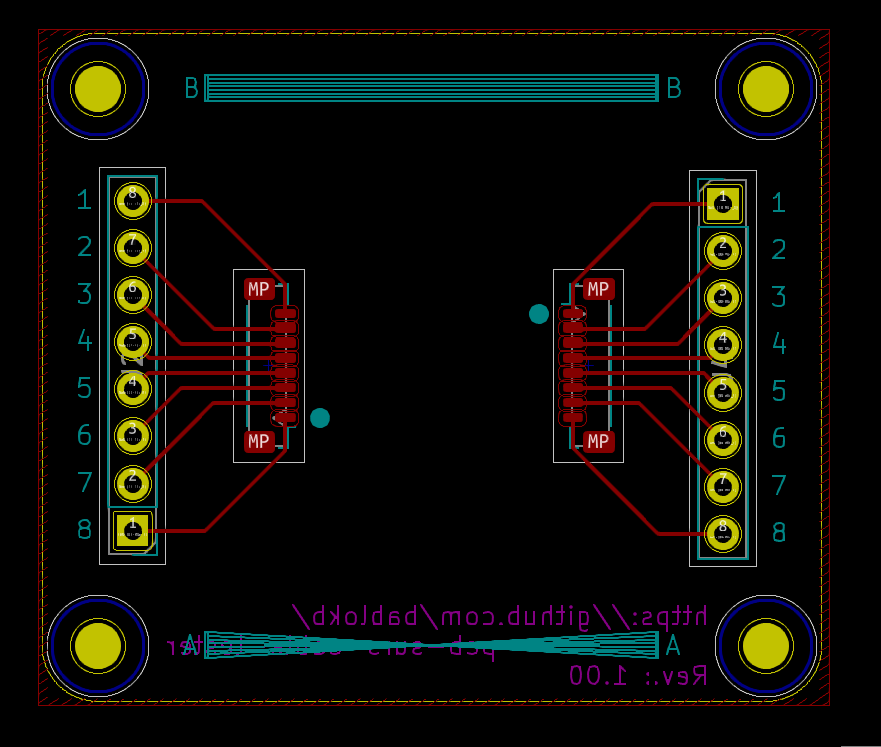
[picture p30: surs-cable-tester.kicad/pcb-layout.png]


3D-Views
--------

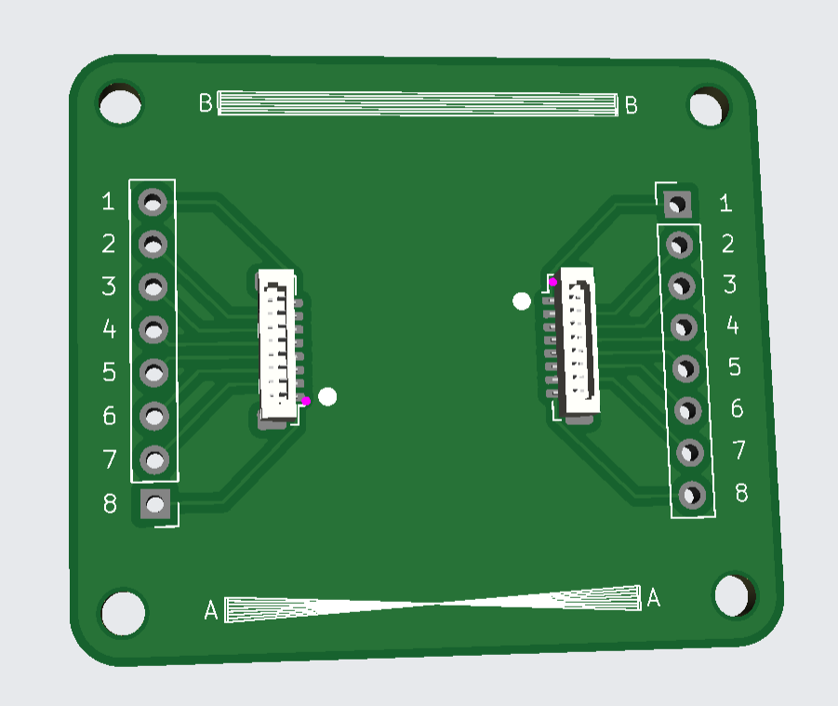
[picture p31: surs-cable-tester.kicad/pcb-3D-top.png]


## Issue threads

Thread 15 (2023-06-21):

Tasks

bablokb, 2023-06-21:
- [ ] Test: sd-mount, if /sd exists and has content
- [ ] Measure power-consumption with sensors and display
- [ ] Measure power-consumption with sensors and without display
- [ ] make csv-name configurable
- [ ] implement write to pico-internal flash (create `boot.py`)
- [ ] refactor sensor-code (one py-file for every sensor, dynamic loading, configure sensors in `config.py`)
- [ ] try to verify 8.1+ e-ink problems with Adafruit-e-ink and file issue with circuitpython
- [ ] support ENS160
- [ ] implement management-mode (use GP27, needs some more specs)
- [ ] measure power-consumption with reduced CPU-frequency
- [ ] integrate data-transfer with LORA
- [ ] implement data-transfer with UDP (WLAN)
- [ ] implement data-transfer with BLE (once available)

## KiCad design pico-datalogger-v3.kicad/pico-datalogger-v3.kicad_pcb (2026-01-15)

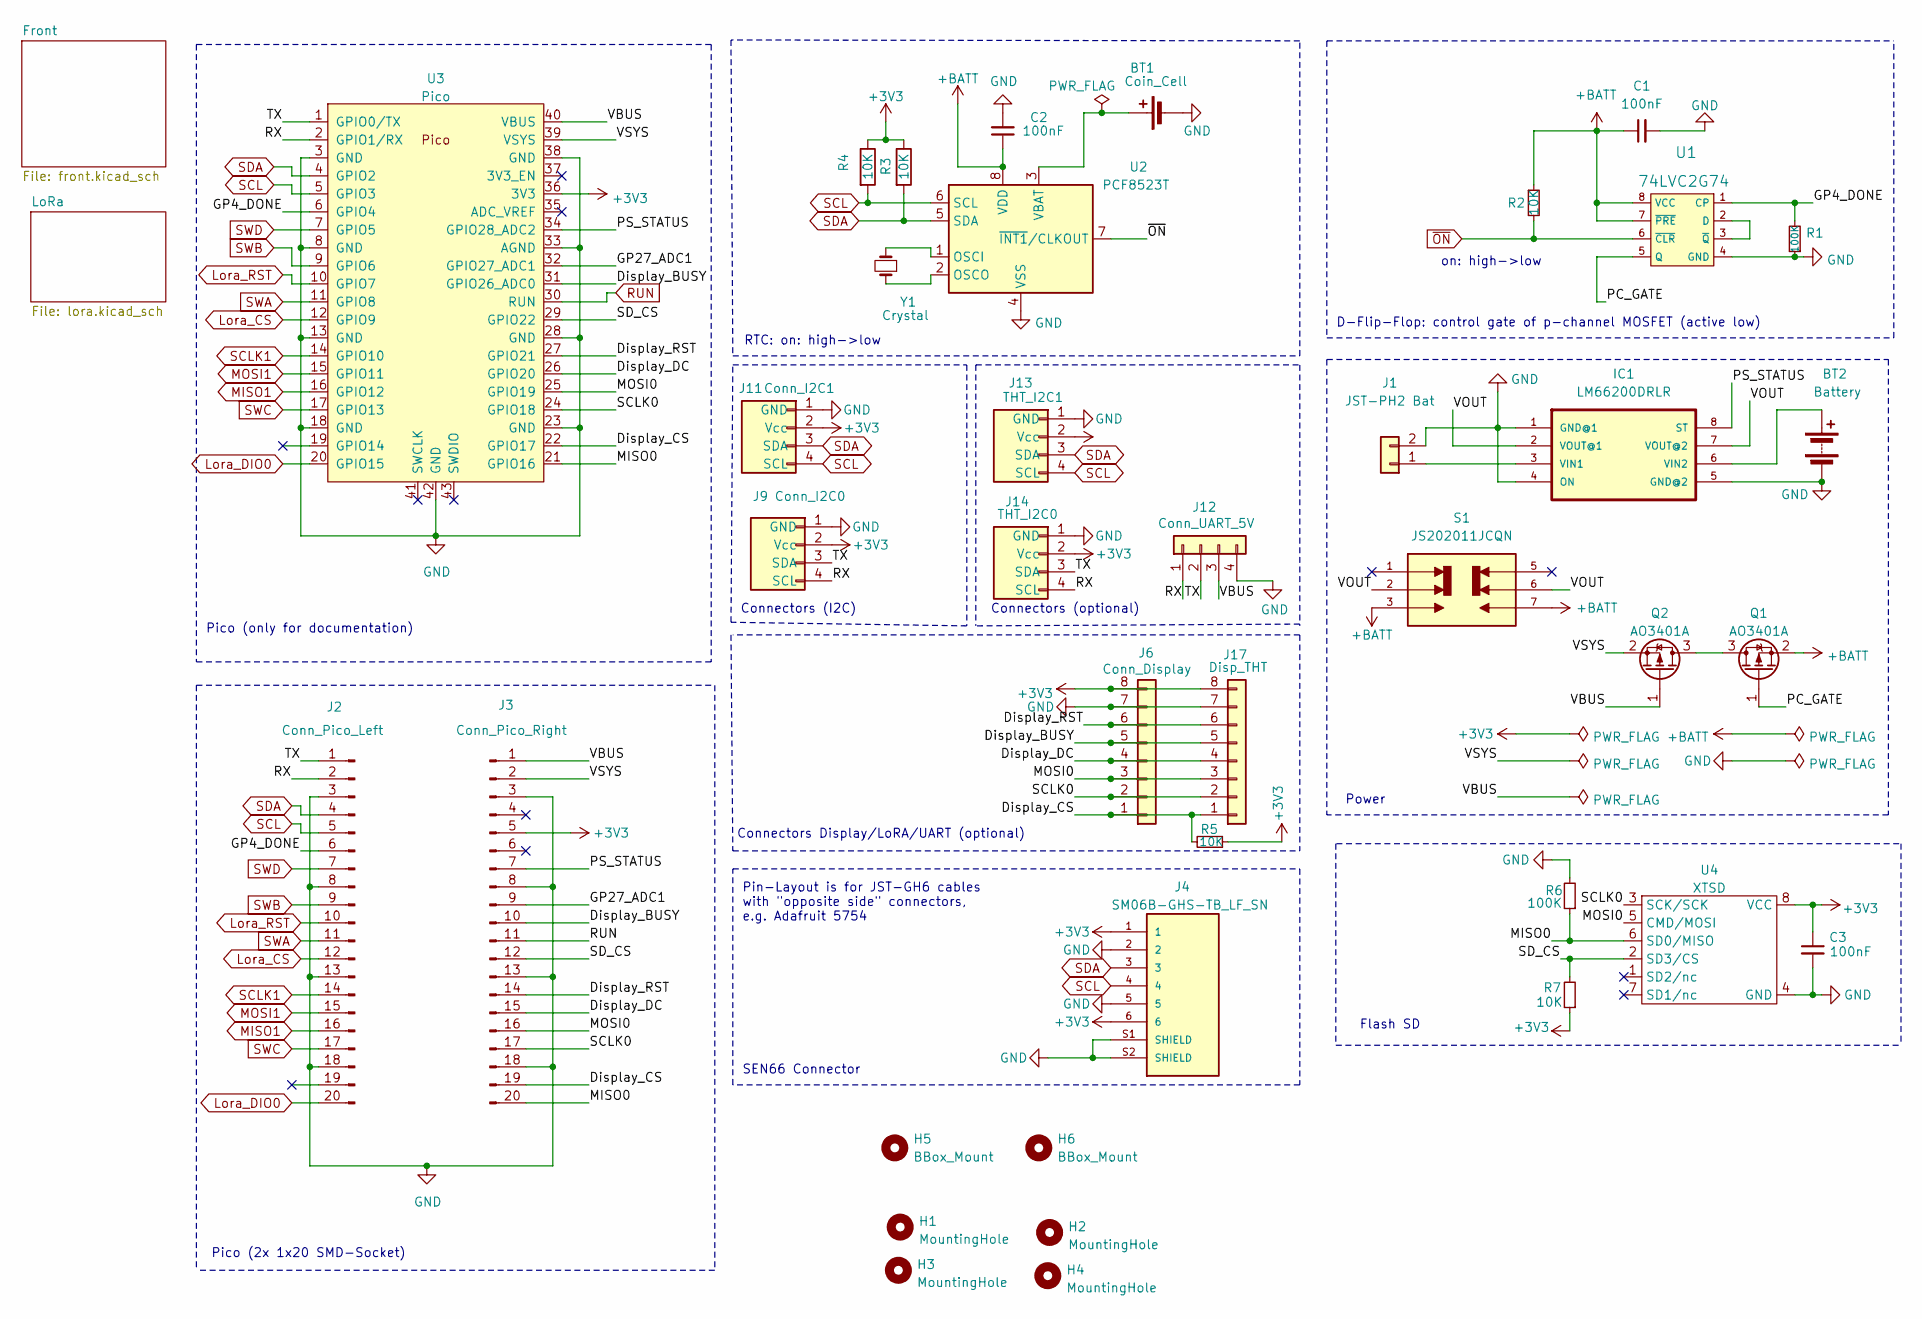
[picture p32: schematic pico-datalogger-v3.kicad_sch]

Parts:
BT1: Coin_Cell; CR2032_Holder; LCSC C964777
BT2: Battery; BatteryHolder_Keystone_2462_2xAA; LCSC C3029547
C1, C2, C3: 100nF; C_0402_1005Metric; LCSC C1525
H1, H2, H3, H4: MountingHole; MountingHole_2.5mm
H5, H6: BBox_Mount; MountingHole_3.5_slotted
IC1: LM66200DRLR; LCSC C3235556
J1: JST-PH2 Bat; JST_PH_S2B-PH-SM4-TB_1x02-1MP_P2.00mm_Horizontal; LCSC C295747
J2: Conn_Pico_Left; PinSocket_1x20_P2.54mm_Vertical; LCSC C429947
J3: Conn_Pico_Right; PinSocket_1x20_P2.54mm_Vertical; LCSC C429947
J4: SM06B-GHS-TB_LF_SN; JST_SM06B-GHS-TB_LF_SN; LCSC C133065
J6: Conn_Display; JST_SUR_BM08B-SURS-TF_1x08-1MP_P0.80mm_Vertical; LCSC C5143489
J9: Conn_I2C0; JST_SH_SM04B-SRSS-TB_1x04-1MP_P1.00mm_Horizontal; LCSC C160404
J11: Conn_I2C1; JST_SH_SM04B-SRSS-TB_1x04-1MP_P1.00mm_Horizontal; LCSC C160404
J12: Conn_UART_5V; PinHeader_1x04_P2.54mm_Horizontal
J13: THT_I2C1; PinHeader_1x04_P2.54mm_Vertical
J14: THT_I2C0; PinHeader_1x04_P2.54mm_Vertical
J17: Disp_THT; PinHeader_1x08_P2.54mm_Vertical
Q1, Q2: AO3401A; SOT-23; LCSC C15127
R1, R6: 100K; R_0402_1005Metric; LCSC C25741
R2, R3, R4, R5, R7: 10K; R_0402_1005Metric; LCSC C25744
S1: JS202011JCQN; SW_JS202011JCQN; LCSC C221665
U1: 74LVC2G74; TSSOP-8_3x3mm_P0.65mm; MPN SN74HC74N; Digi-Key_PN 296-1602-5-ND
U2: PCF8523T; SOIC-8_3.9x4.9mm_P1.27mm; LCSC C2651516
U3: Pico; RPi_Pico_TH_nodbg
U4: XTSD; LCSC C7429710
Y1: Crystal; Crystal_SMD_3215-2Pin_3.2x1.5mm; LCSC C32346

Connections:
+3V3: C3.1, J3.5, J4.1, J4.6, J6.8, J9.2 (Vcc), J11.2 (Vcc), J13.2 (Vcc), J14.2 (Vcc), J17.8, R3.1, R4.1, R5.1, R7.1, U3.36 (3V3), U4.8 (VCC); also elsewhere on the board
+BATT: C1.1, C2.1, Q1.2 (S), R2.1, S1.3, S1.7, U1.7 (~PRE), U1.8 (VCC), U2.8 (VDD)
/Display_BUSY: J3.10, J6.5, J17.5, U3.31 (GPIO26_ADC0)
/Display_CS: J3.19, J6.1, J17.1, R5.2, U3.22 (GPIO17)
/Display_DC: J3.15, J6.4, J17.4, U3.26 (GPIO20)
/Display_RST: J3.14, J6.6, J17.6, U3.27 (GPIO21)
/GP4_DONE: J2.6, R1.2, U1.1 (CP), U3.6 (GPIO4)
/GP27_ADC1: J3.9, U3.32 (GPIO27_ADC1)
/MISO0: J3.20, R6.1, U3.21 (GPIO16), U4.6 (SD0/MISO)
/MOSI0: J3.16, J6.3, J17.3, U3.25 (GPIO19), U4.5 (CMD/MOSI)
/PC_GATE: Q1.1 (G), U1.5 (Q)
/PS_STATUS: IC1.8 (ST), J3.7, U3.34 (GPIO28_ADC2)
/RX: J2.2, J9.4 (SCL), J12.1, J14.4 (SCL), U3.2 (GPIO1/RX)
/SCLK0: J3.17, J6.2, J17.2, U3.24 (GPIO18), U4.3 (SCK/SCK)
/SD_CS: J3.12, R7.2, U3.29 (GPIO22), U4.2 (SD3/CS)
/TX: J2.1, J9.3 (SDA), J12.2, J14.3 (SDA), U3.1 (GPIO0/TX)
/VBUS: J3.1, J12.3, Q2.1 (G), U3.40 (VBUS)
/VOUT: IC1.2 (VOUT@1), IC1.7 (VOUT@2), S1.2, S1.6
/VSYS: J3.2, Q2.2 (S), U3.39 (VSYS)
GND: BT1.2 (-), BT2.2 (-), C1.2, C2.2, C3.2, IC1.1 (GND@1), IC1.4 (ON), IC1.5 (GND@2), J1.2, J2.3, J2.8, J2.13, J2.18, J3.3, J3.8, J3.13, J3.18, J4.2, J4.5, J4.S1 (SHIELD), J4.S2 (SHIELD), J6.7, J9.1 (GND), J11.1 (GND), J12.4, J13.1 (GND), J14.1 (GND), J17.7, R1.1, R6.2, U1.4 (GND), U2.4 (VSS), U3.3 (GND), U3.8 (GND), U3.13 (GND), U3.18 (GND), U3.23 (GND), U3.28 (GND), U3.33 (AGND), U3.38 (GND), U3.42 (GND), U4.4 (GND); also elsewhere on the board
Lora_CS: J2.12, U3.12 (GPIO9); also elsewhere on the board
Lora_DIO0: J2.20, U3.20 (GPIO15); also elsewhere on the board
Lora_RST: J2.10, U3.10 (GPIO7); also elsewhere on the board
MISO1: J2.16, U3.16 (GPIO12); also elsewhere on the board
MOSI1: J2.15, U3.15 (GPIO11); also elsewhere on the board
unnamed: BT1.1 (+), U2.3 (VBAT)
unnamed: BT2.1 (+), IC1.6 (VIN2)
unnamed: IC1.3 (VIN1), J1.1
unnamed: Q1.3 (D), Q2.3 (D)
unnamed: U1.2 (D), U1.3 (~Q)
unnamed: U2.1 (OSCI), Y1.2
unnamed: U2.2 (OSCO), Y1.1
RUN: J3.11; also elsewhere on the board
SCL: J2.5, J4.4, J11.4 (SCL), J13.4 (SCL), R4.2, U2.6 (SCL), U3.5 (GPIO3); also elsewhere on the board
SCLK1: J2.14, U3.14 (GPIO10); also elsewhere on the board
SDA: J2.4, J4.3, J11.3 (SDA), J13.3 (SDA), R3.2, U2.5 (SDA), U3.4 (GPIO2); also elsewhere on the board
SWA: J2.11, U3.11 (GPIO8); also elsewhere on the board
SWB: J2.9, U3.9 (GPIO6); also elsewhere on the board
SWC: J2.17, U3.17 (GPIO13); also elsewhere on the board
SWD: J2.7, U3.7 (GPIO5); also elsewhere on the board
~ON: R2.2, U1.6 (~CLR), U2.7 (~INT1/CLKOUT); also elsewhere on the board

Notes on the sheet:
on: high->low
D-Flip-Flop: control gate of p-channel MOSFET (active low)
Connectors Display/LoRA/UART (optional)
Pico (only for documentation)
Power
Pico (2x 1x20 SMD-Socket)
SEN66 Connector
RTC: on: high->low
Connectors (optional)
Pin-Layout is for JST-GH6 cables with "opposite side" connectors, e.g. Adafruit 5754
Connectors (I2C)
Flash SD

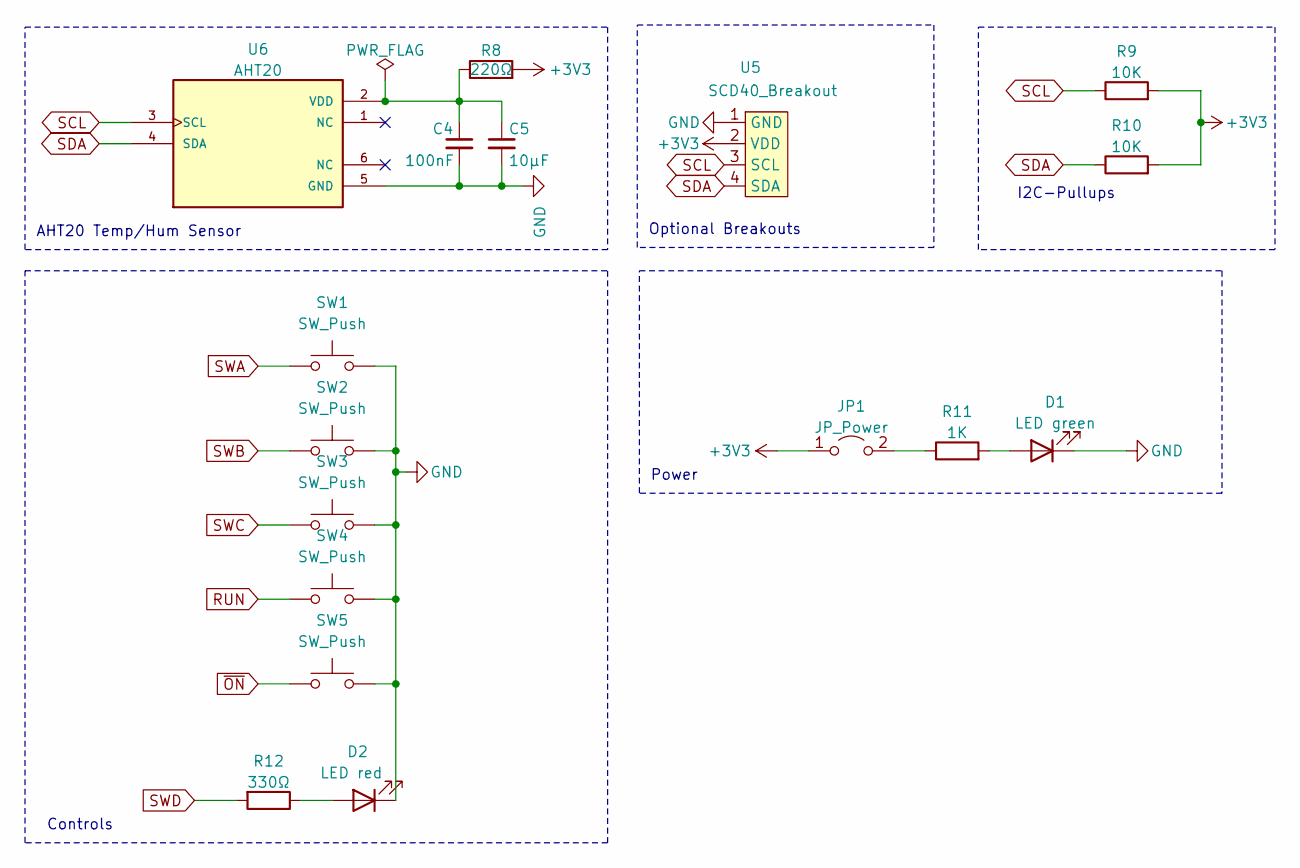
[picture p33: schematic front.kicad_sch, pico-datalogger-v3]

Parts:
C4: 100nF; C_0402_1005Metric; LCSC C1525
C5: 10µF; C_0603_1608Metric; LCSC C19702
D1: LED green; LED_0805_2012Metric; LCSC C2297
D2: LED red; LED_0805_2012Metric; LCSC C84256
JP1: JP_Power; SolderJumper-2_P1.3mm_Open_Pad1.0x1.5mm
R8: 220Ω; R_0402_1005Metric; LCSC C25091
R9, R10: 10K; R_0402_1005Metric; LCSC C25744
R11: 1K; R_0402_1005Metric; LCSC C11702
R12: 330Ω; R_0402_1005Metric; LCSC C25104
SW1, SW2, SW3, SW4, SW5: SW_Push; SW_SPST_B3S-1000; LCSC C221869
U5: SCD40_Breakout
U6: AHT20; LCSC C3012622

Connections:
+3V3: JP1.1 (A), R8.2, R9.2, R10.2, U5.2 (VDD); also elsewhere on the board
GND: C4.2, C5.2, D1.1 (K), D2.1 (K), SW1.2, SW2.2, SW3.2, SW4.2, SW5.2, U5.1 (GND), U6.5 (GND); also elsewhere on the board
unnamed: D1.2 (A), R11.2
unnamed: D2.2 (A), R12.1
unnamed: JP1.2 (B), R11.1
unnamed: C4.1, C5.1, R8.1, U6.2 (VDD)
RUN: SW4.1; also elsewhere on the board
SCL: R9.1, U5.3 (SCL), U6.3 (SCL); also elsewhere on the board
SDA: R10.1, U5.4 (SDA), U6.4 (SDA); also elsewhere on the board
SWA: SW1.1; also elsewhere on the board
SWB: SW2.1; also elsewhere on the board
SWC: SW3.1; also elsewhere on the board
SWD: R12.2; also elsewhere on the board
~ON: SW5.1; also elsewhere on the board

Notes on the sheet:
Optional Breakouts
AHT20 Temp/Hum Sensor
Power
I2C-Pullups
Controls

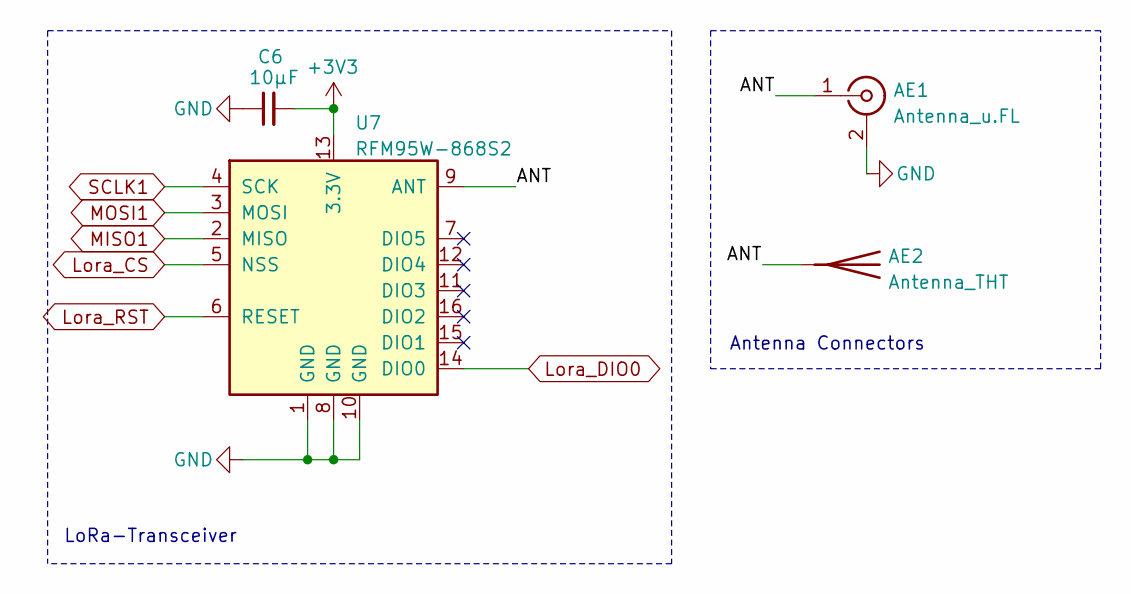
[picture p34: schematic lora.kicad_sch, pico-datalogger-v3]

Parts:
AE1: Antenna_u.FL; U.FL_Hirose_U.FL-R-SMT-1_Vertical; LCSC C88374
AE2: Antenna_THT
C6: 10µF; C_0603_1608Metric; LCSC C19702
U7: RFM95W-868S2; HOPERF_RFM9XW_SMD; LCSC C2844472

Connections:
+3V3: C6.2, U7.13 (3.3V); also elsewhere on the board
/LoRa/ANT: AE1.1 (In), AE2.1 (A), U7.9 (ANT)
GND: AE1.2 (Ext), C6.1, U7.1 (GND), U7.8 (GND), U7.10 (GND); also elsewhere on the board
Lora_CS: U7.5 (NSS); also elsewhere on the board
Lora_DIO0: U7.14 (DIO0); also elsewhere on the board
Lora_RST: U7.6 (RESET); also elsewhere on the board
MISO1: U7.2 (MISO); also elsewhere on the board
MOSI1: U7.3 (MOSI); also elsewhere on the board
SCLK1: U7.4 (SCK); also elsewhere on the board

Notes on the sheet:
Antenna Connectors
LoRa-Transceiver

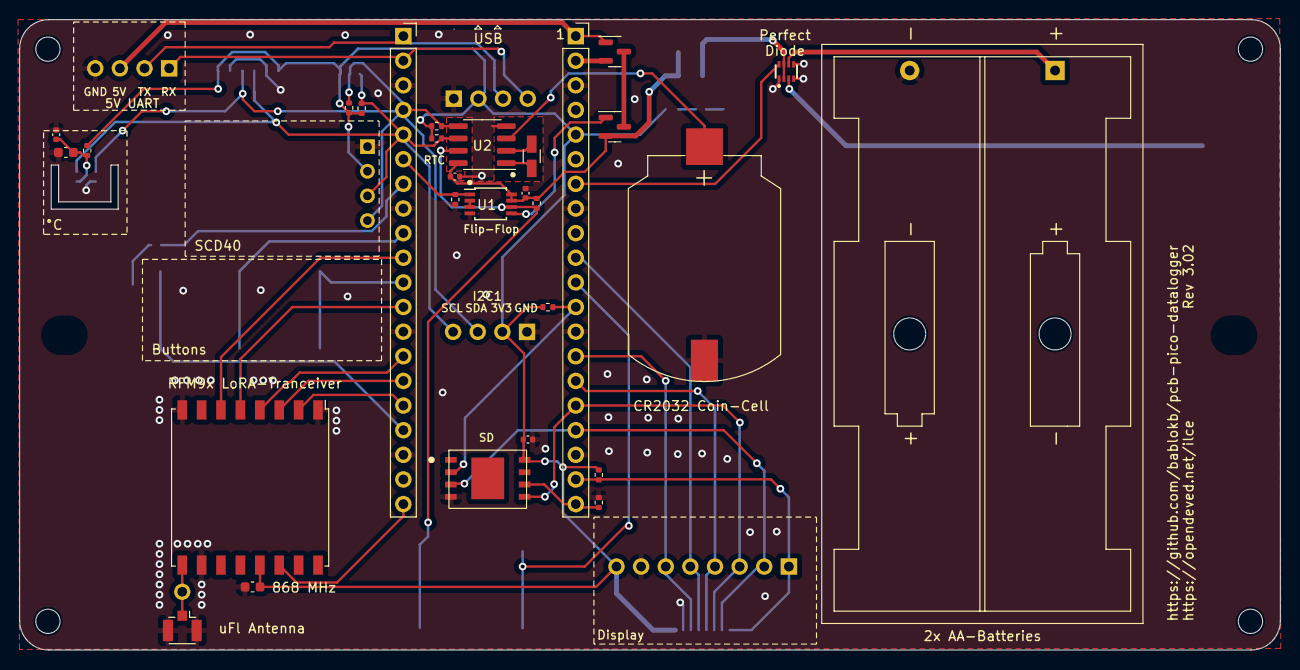
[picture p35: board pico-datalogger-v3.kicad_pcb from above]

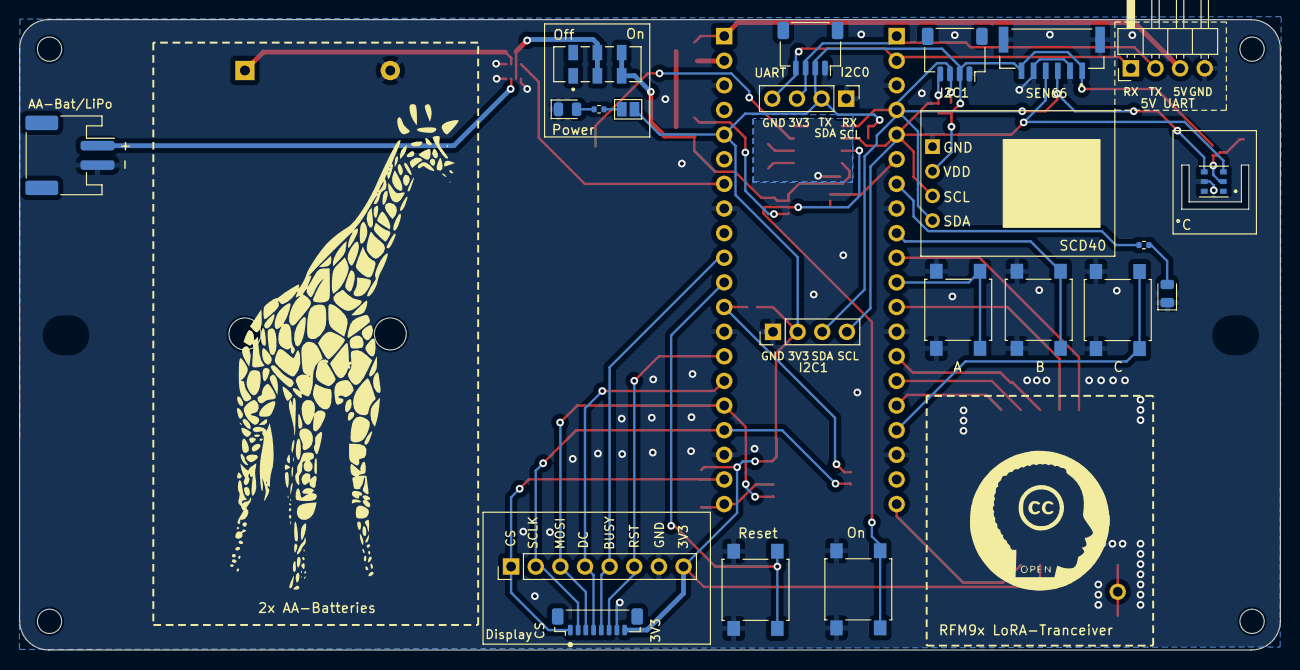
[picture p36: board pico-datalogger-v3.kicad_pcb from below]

Board: 2 copper layers, 130.0 x 65.0 mm, 58 parts (22 on the bottom side), 45 nets.

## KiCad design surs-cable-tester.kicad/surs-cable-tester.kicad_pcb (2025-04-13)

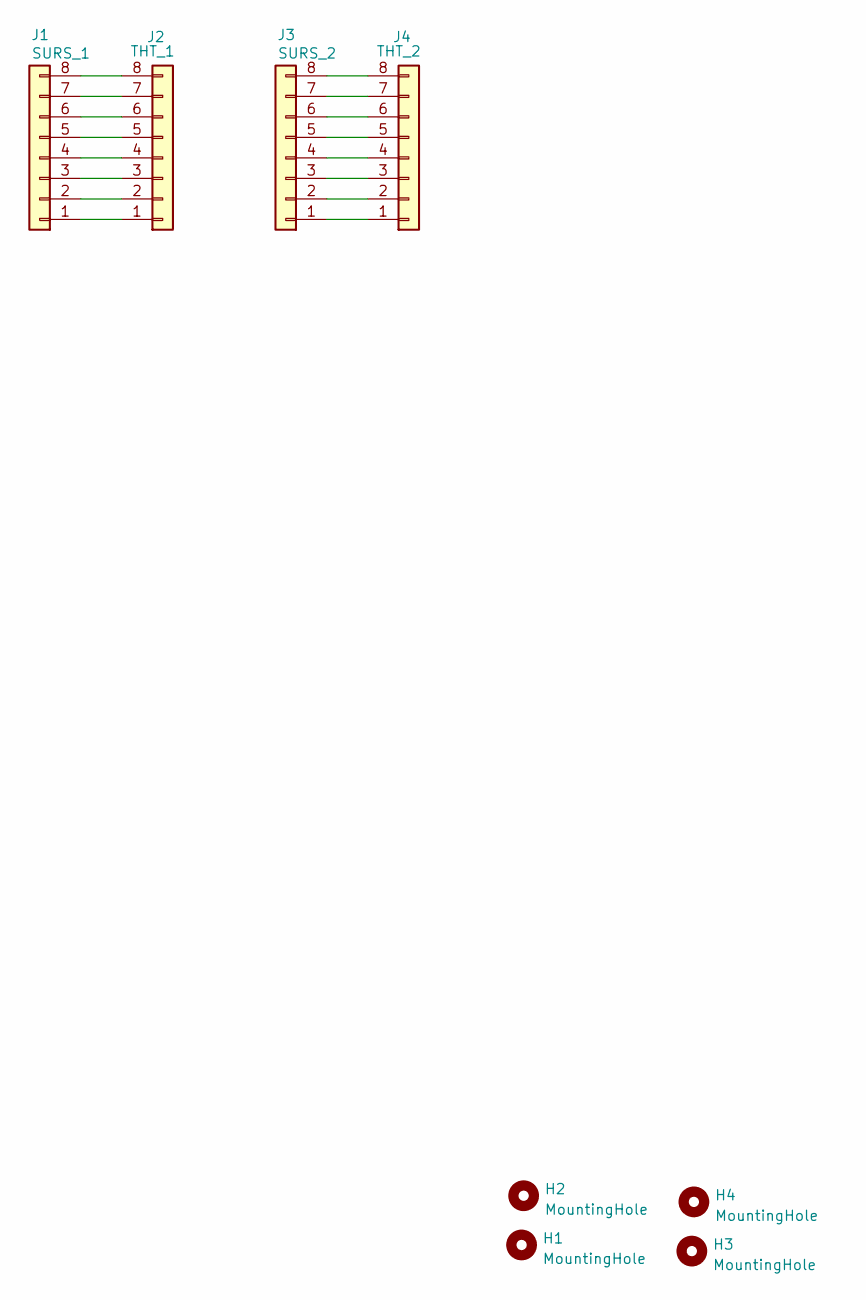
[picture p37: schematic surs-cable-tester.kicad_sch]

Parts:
H1, H2, H3, H4: MountingHole; MountingHole_2.5mm
J1: SURS_1; JST_SUR_BM08B-SURS-TF_1x08-1MP_P0.80mm_Vertical; LCSC C5143489
J2: THT_1; PinHeader_1x08_P2.54mm_Vertical
J3: SURS_2; JST_SUR_BM08B-SURS-TF_1x08-1MP_P0.80mm_Vertical; LCSC C5143489
J4: THT_2; PinHeader_1x08_P2.54mm_Vertical

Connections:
unnamed: J1.1, J2.1
unnamed: J1.2, J2.2
unnamed: J1.3, J2.3
unnamed: J1.4, J2.4
unnamed: J1.5, J2.5
unnamed: J1.6, J2.6
unnamed: J1.7, J2.7
unnamed: J1.8, J2.8
unnamed: J3.1, J4.1
unnamed: J3.2, J4.2
unnamed: J3.3, J4.3
unnamed: J3.4, J4.4
unnamed: J3.5, J4.5
unnamed: J3.6, J4.6
unnamed: J3.7, J4.7
unnamed: J3.8, J4.8

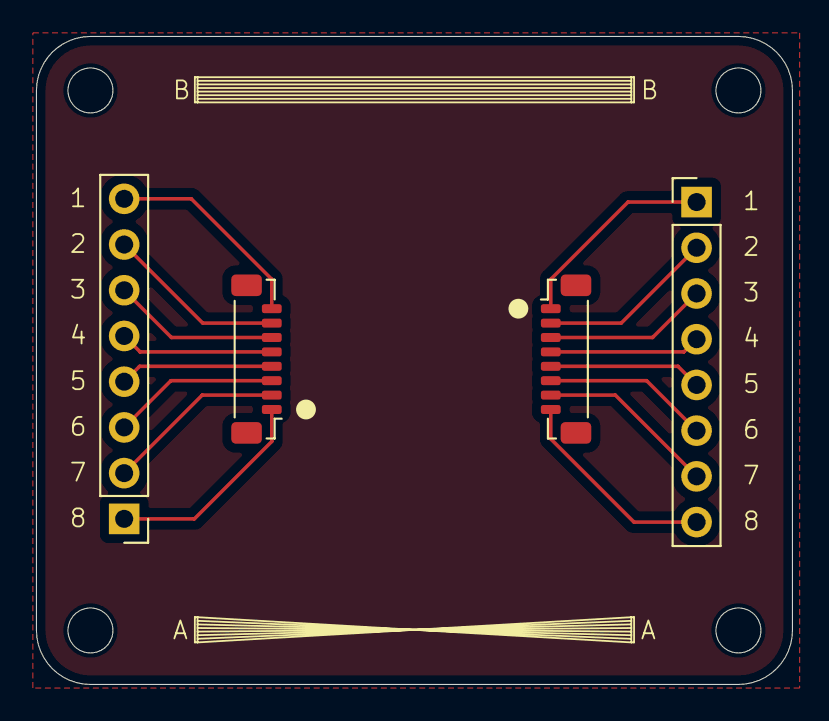
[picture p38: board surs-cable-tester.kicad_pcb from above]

Board: 2 copper layers, 42.0 x 36.0 mm, 8 parts (0 on the bottom side), 16 nets.

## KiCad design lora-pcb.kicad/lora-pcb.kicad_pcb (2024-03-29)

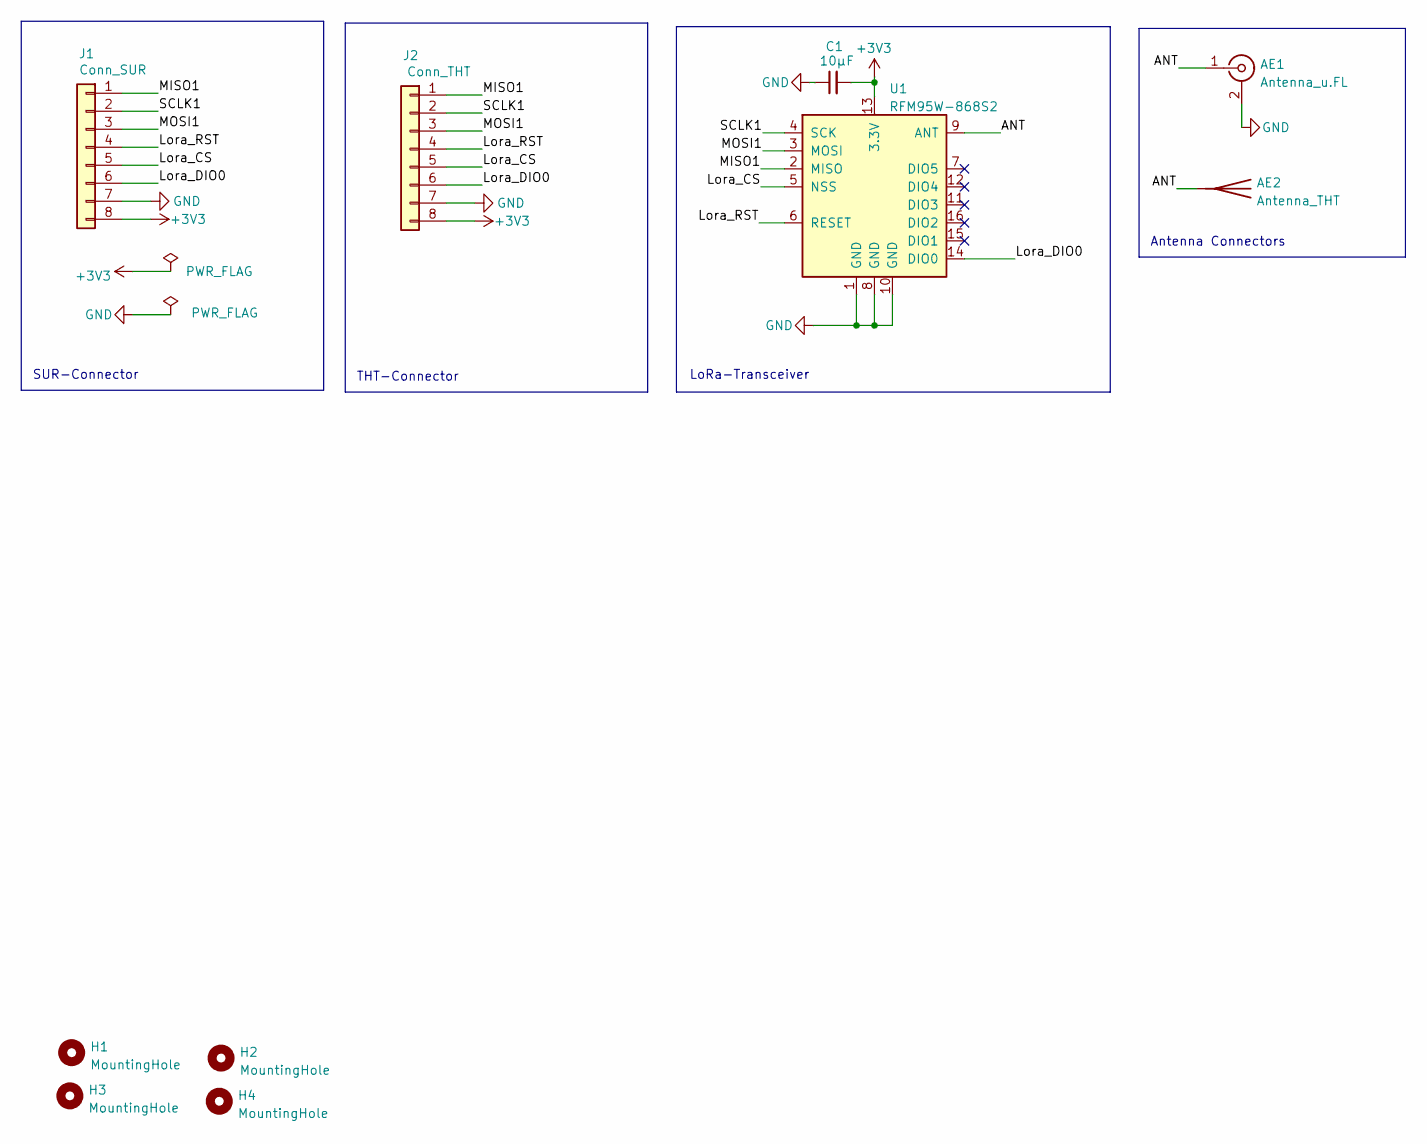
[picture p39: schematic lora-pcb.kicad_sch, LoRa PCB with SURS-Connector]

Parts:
AE1: Antenna_u.FL; U.FL_Hirose_U.FL-R-SMT-1_Vertical; LCSC C88374
AE2: Antenna_THT
C1: 10µF; C_0603_1608Metric; LCSC C19702
H1, H2, H3, H4: MountingHole; MountingHole_2.5mm
J1: Conn_SUR; JST_SUR_BM08B-SURS-TF_1x08-1MP_P0.80mm_Vertical; LCSC C5143489
J2: Conn_THT; PinHeader_1x08_P2.54mm_Vertical; LCSC C5143489
U1: RFM95W-868S2; HOPERF_RFM9XW_SMD; LCSC C2844474

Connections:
+3V3: C1.2, J1.8, J2.8, U1.13 (3.3V)
/ANT: AE1.1 (In), AE2.1 (A), U1.9 (ANT)
/Lora_CS: J1.5, J2.5, U1.5 (NSS)
/Lora_DIO0: J1.6, J2.6, U1.14 (DIO0)
/Lora_RST: J1.4, J2.4, U1.6 (RESET)
/MISO1: J1.1, J2.1, U1.2 (MISO)
/MOSI1: J1.3, J2.3, U1.3 (MOSI)
/SCLK1: J1.2, J2.2, U1.4 (SCK)
GND: AE1.2 (Ext), C1.1, J1.7, J2.7, U1.1 (GND), U1.8 (GND), U1.10 (GND)

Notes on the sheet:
Antenna Connectors
LoRa-Transceiver
THT-Connector
SUR-Connector

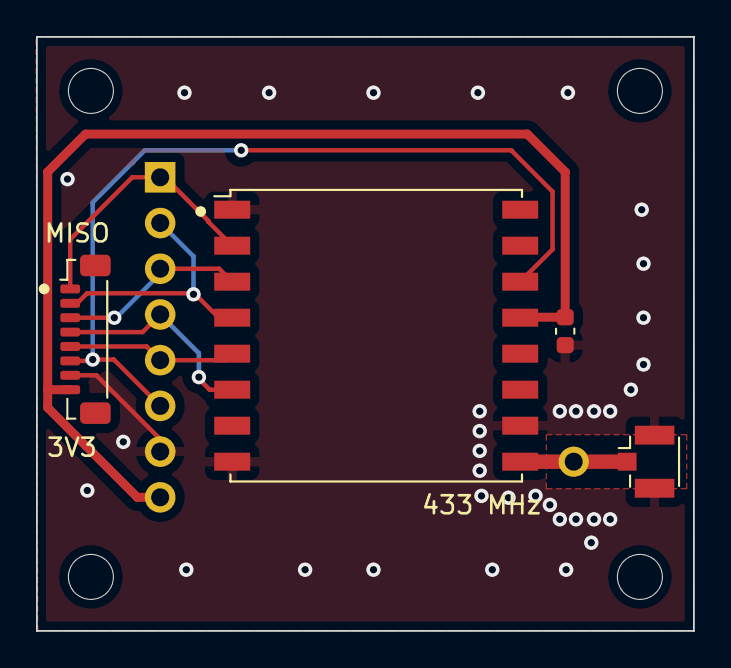
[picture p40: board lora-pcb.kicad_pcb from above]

Board: 2 copper layers, 36.5 x 33.0 mm, 10 parts (1 on the bottom side), 9 nets.

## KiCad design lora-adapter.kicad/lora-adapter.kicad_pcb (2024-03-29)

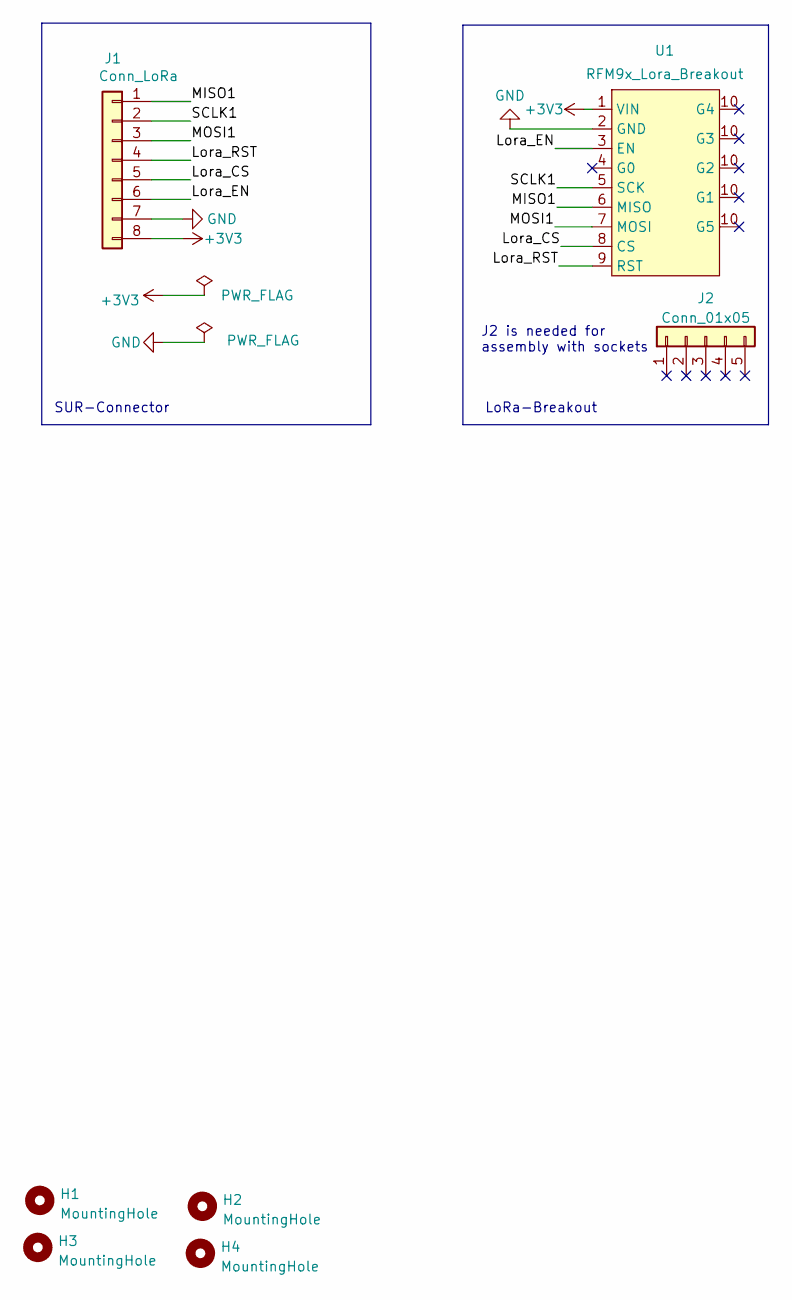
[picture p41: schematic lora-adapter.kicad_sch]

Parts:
H1, H2, H3, H4: MountingHole; MountingHole_2.5mm
J1: Conn_LoRa; JST_SUR_BM08B-SURS-TF_1x08-1MP_P0.80mm_Vertical; LCSC C5143489
J2: Conn_01x05; PinSocket_1x05_P2.54mm_Vertical; LCSC C2897368
U1: RFM9x_Lora_Breakout; PinSocket_1x09_P2.54mm_Vertical; LCSC C2897372

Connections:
+3V3: J1.8, U1.1 (VIN)
/Lora_CS: J1.5, U1.8 (CS)
/Lora_EN: J1.6, U1.3 (EN)
/Lora_RST: J1.4, U1.9 (RST)
/MISO1: J1.1, U1.6 (MISO)
/MOSI1: J1.3, U1.7 (MOSI)
/SCLK1: J1.2, U1.5 (SCK)
GND: J1.7, U1.2 (GND)

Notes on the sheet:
J2 is needed for assembly with sockets
LoRa-Breakout
SUR-Connector

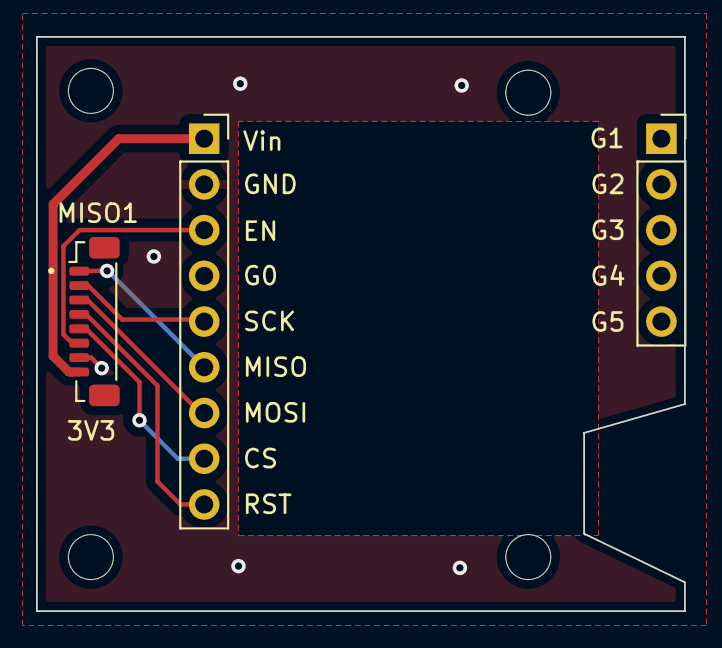
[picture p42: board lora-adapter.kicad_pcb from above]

Board: 2 copper layers, 36.0 x 31.9 mm, 7 parts (0 on the bottom side), 8 nets.

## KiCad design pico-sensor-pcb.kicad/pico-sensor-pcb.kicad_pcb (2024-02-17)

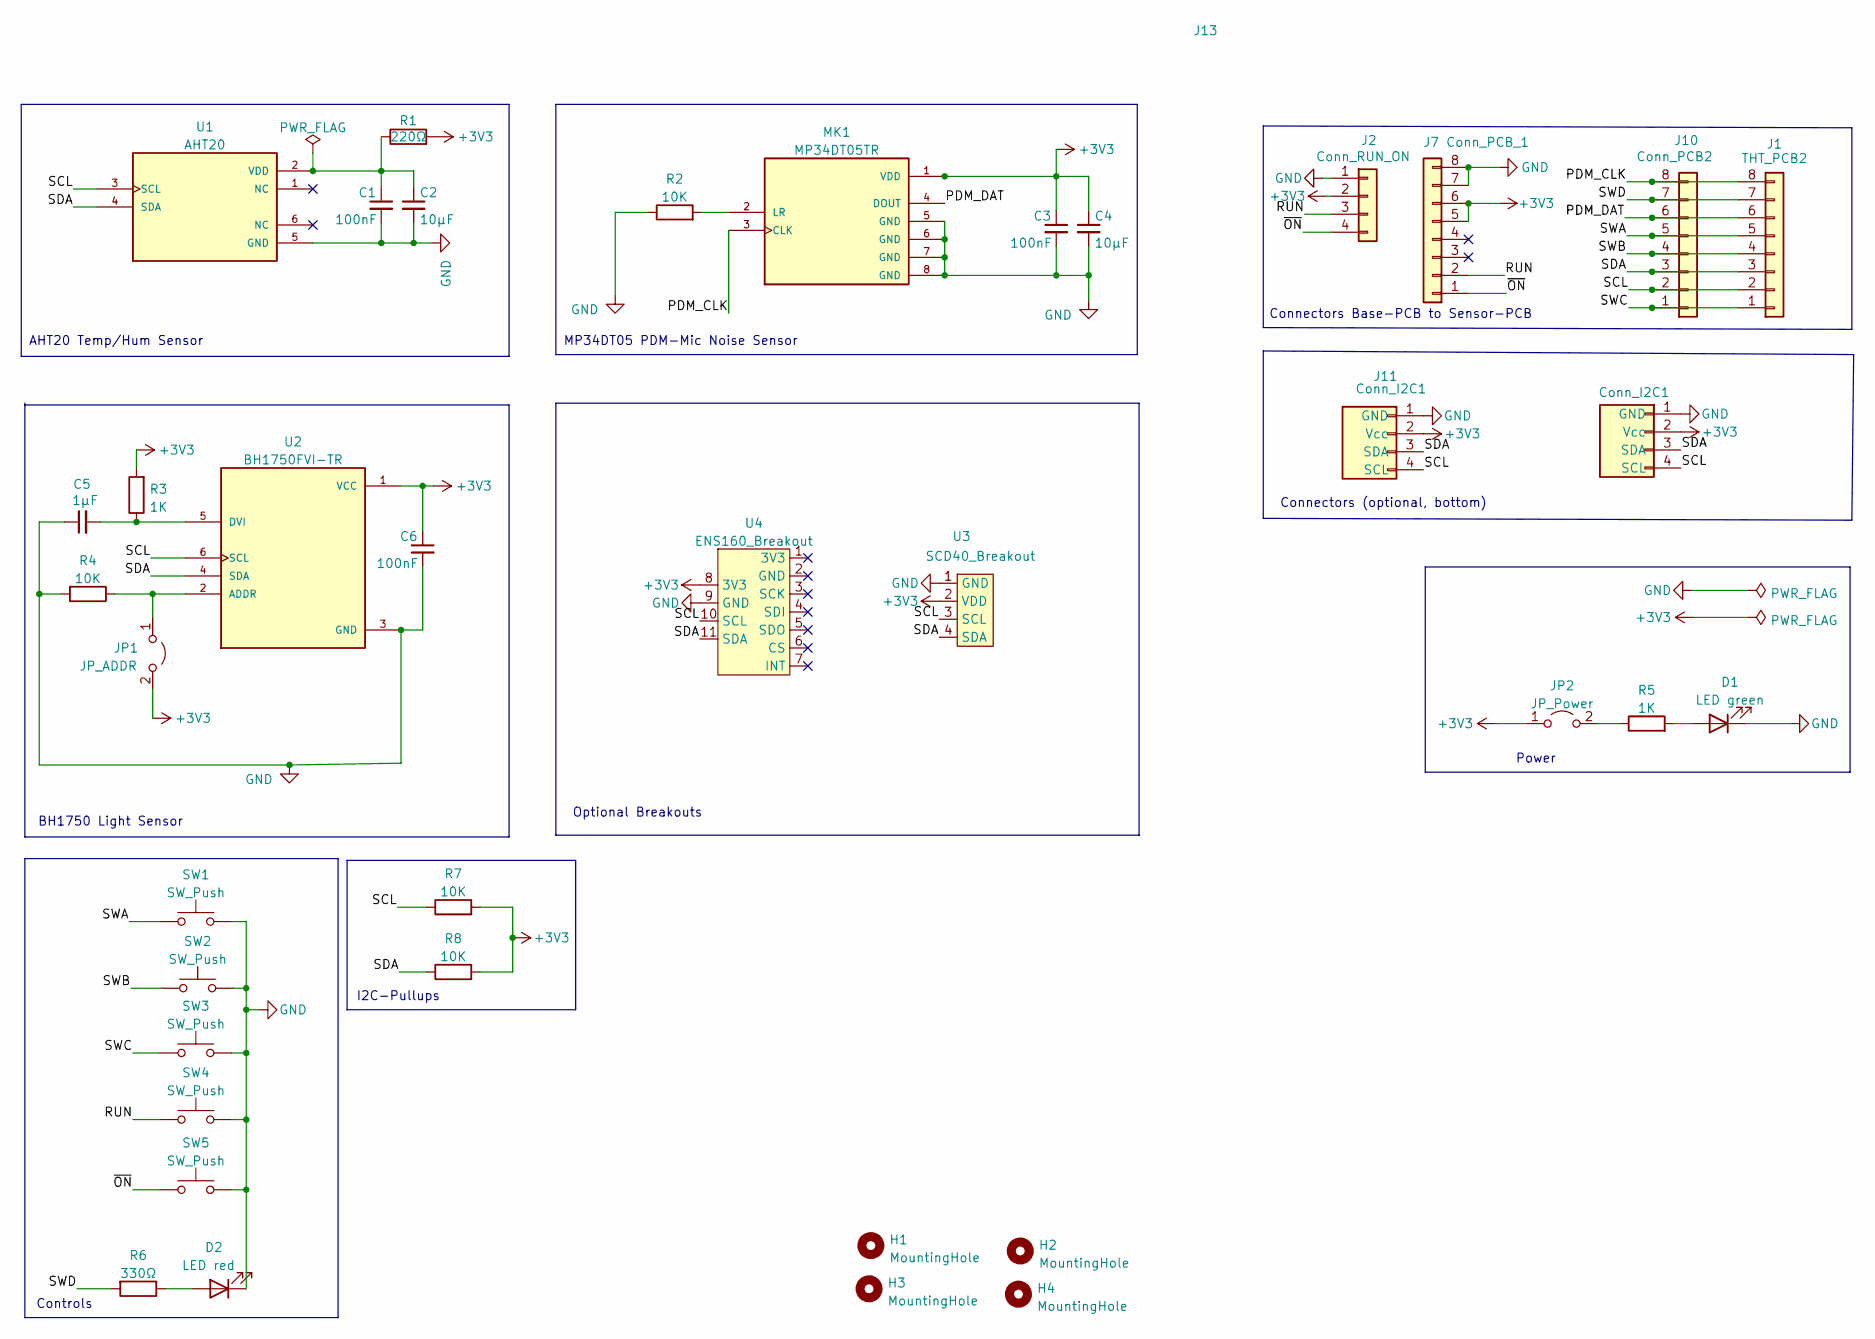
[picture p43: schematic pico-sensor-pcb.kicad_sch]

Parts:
C1, C3, C6: 100nF; C_0402_1005Metric; LCSC C1525
C2, C4: 10µF; C_0603_1608Metric; LCSC C19702
C5: 1µF; C_0603_1608Metric; LCSC C15849
D1: LED green; LED_0805_2012Metric; LCSC C2297
D2: LED red; LED_0805_2012Metric; LCSC C84256
H1, H2, H3, H4: MountingHole; MountingHole_2.5mm
J1: THT_PCB2; PinHeader_1x08_P2.54mm_Vertical
J2: Conn_RUN_ON; PinHeader_1x04_P2.54mm_Vertical
J7: Conn_PCB_1; JST_SUR_BM08B-SURS-TF_1x08-1MP_P0.80mm_Vertical; LCSC C5143489
J10: Conn_PCB2; JST_SUR_BM08B-SURS-TF_1x08-1MP_P0.80mm_Vertical; LCSC C5143489
J11: Conn_I2C1; JST_SH_SM04B-SRSS-TB_1x04-1MP_P1.00mm_Horizontal; LCSC C160404
J13: Conn_I2C1; PinHeader_1x04_P2.54mm_Horizontal
JP1: JP_ADDR; SolderJumper-2_P1.3mm_Open_Pad1.0x1.5mm
JP2: JP_Power; SolderJumper-2_P1.3mm_Open_Pad1.0x1.5mm
MK1: MP34DT05TR; LCSC C2688664
R1: 220Ω; R_0402_1005Metric; LCSC C25091
R2, R4, R7, R8: 10K; R_0402_1005Metric; LCSC C25744
R3, R5: 1K; R_0402_1005Metric; LCSC C11702
R6: 330Ω; R_0402_1005Metric; LCSC C25104
SW1, SW2, SW3, SW4, SW5: SW_Push; SW_SPST_B3S-1000; LCSC C221869
U1: AHT20; LCSC C3012622
U2: BH1750FVI-TR; BH1750; LCSC C78960
U3: SCD40_Breakout
U4: ENS160_Breakout

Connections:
+3V3: C3.1, C4.1, C6.1, J2.2, J7.5, J7.6, J11.2 (Vcc), J13.2 (Vcc), JP1.2 (B), JP2.1 (A), MK1.1 (VDD), R1.2, R3.2, R7.2, R8.2, U2.1 (VCC), U3.2 (VDD), U4.8 (3V3)
/PDM_CLK: J1.8, J10.8, MK1.3 (CLK)
/PDM_DAT: J1.6, J10.6, MK1.4 (DOUT)
/RUN: J2.3, J7.2, SW4.1
/SCL: J1.2, J10.2, J11.4 (SCL), J13.4 (SCL), R7.1, U1.3 (SCL), U2.6 (SCL), U3.3 (SCL), U4.10 (SCL)
/SDA: J1.3, J10.3, J11.3 (SDA), J13.3 (SDA), R8.1, U1.4 (SDA), U2.4 (SDA), U3.4 (SDA), U4.11 (SDA)
/SWA: J1.5, J10.5, SW1.1
/SWB: J1.4, J10.4, SW2.1
/SWC: J1.1, J10.1, SW3.1
/SWD: J1.7, J10.7, R6.2
/~ON: J2.4, J7.1, SW5.1
GND: C1.2, C2.2, C3.2, C4.2, C5.1, C6.2, D1.1 (K), D2.1 (K), J2.1, J7.7, J7.8, J11.1 (GND), J13.1 (GND), MK1.5 (GND), MK1.6 (GND), MK1.7 (GND), MK1.8 (GND), R2.1, R4.2, SW1.2, SW2.2, SW3.2, SW4.2, SW5.2, U1.5 (GND), U2.3 (GND), U3.1 (GND), U4.9 (GND)
unnamed: C1.1, C2.1, R1.1, U1.2 (VDD)
unnamed: C5.2, R3.1, U2.5 (DVI)
unnamed: D1.2 (A), R5.2
unnamed: D2.2 (A), R6.1
unnamed: JP1.1 (A), R4.1, U2.2 (ADDR)
unnamed: JP2.2 (B), R5.1
unnamed: MK1.2 (LR), R2.2

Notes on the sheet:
Optional Breakouts
AHT20 Temp/Hum Sensor
BH1750 Light Sensor
MP34DT05 PDM-Mic Noise Sensor
Power
Connectors (optional, bottom)
I2C-Pullups
Controls
Connectors Base-PCB to Sensor-PCB

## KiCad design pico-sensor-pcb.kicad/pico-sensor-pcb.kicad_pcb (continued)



Board: 2 copper layers, 56.0 x 70.0 mm, 38 parts (8 on the bottom side), 19 nets.

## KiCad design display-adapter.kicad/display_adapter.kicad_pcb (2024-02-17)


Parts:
H1, H2, H3, H4: MountingHole; MountingHole_2.5mm
J1: Conn_Display; JST_SUR_BM08B-SURS-TF_1x08-1MP_P0.80mm_Vertical; LCSC C5143489
J2: Inky_Left_1_20; PinHeader_1x20_P2.54mm_Vertical; LCSC C725952
J3: Inky_Right_21_40; PinHeader_1x20_P2.54mm_Vertical; LCSC C725952
J4: Ada_SPI_Display; PinSocket_1x13_P2.54mm_Vertical

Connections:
+3V3: J1.1, J3.16, J4.1
/Display_BUSY: J1.4, J3.11, J4.12
/Display_CS: J1.8, J3.2, J4.7
/Display_DC: J1.5, J3.6, J4.8
/Display_RST: J1.3, J3.7, J4.11
/MOSI0: J1.6, J3.5, J4.6
/SCLK0: J1.7, J3.4, J4.4
GND: J1.2, J2.3, J2.8, J2.13, J2.18, J3.3, J3.8, J3.18, J4.3

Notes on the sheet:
Pimoroni Inky-Pack
Adafruit SPI Displays
SUR-Connector


Board: 2 copper layers, 36.4 x 68.3 mm, 8 parts (1 on the bottom side), 8 nets.

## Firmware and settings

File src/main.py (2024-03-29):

#-----------------------------------------------------------------------------
# Basic data-collection program.
#
# The code is encapsulated in the class Datacollector, mainly to allow
# the use of precompiled code.
#
# Author: Bernhard Bablok
#
# Website: https://github.com/pcb-pico-datalogger
#-----------------------------------------------------------------------------

import datacollector

try:
  app = datacollector.DataCollector()
  app.run()
except Exception as ex:
  import traceback
  traceback.print_exception(ex)
  try:
    app.cleanup()
  except:
    pass
  print("please press the reset-button!")

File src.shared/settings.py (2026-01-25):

#-----------------------------------------------------------------------------
# Read configuration and set defaults.
#
# Author: Bernhard Bablok
#
# Website: https://github.com/pcb-pico-datalogger
#-----------------------------------------------------------------------------

import gc

class Settings:
  def __init__(self,logger):
    """ constructor """
    self._logger = logger

  def import_config(self):
    """ import config-module and make variables attributes """
    import config

    # set defaults
    self.HAVE_PM       = True
    self.SHUTDOWN_HIGH = True
    self.HAVE_RTC      = "PCF8523(1)"
    self.HAVE_SD       = True
    self.HAVE_I2C0     = False
    self.HAVE_I2C_MP   = None
    self.HAVE_LIPO     = False
    self.HAVE_DISPLAY  = None
    self.HAVE_LORA     = False
    self.HAVE_OLED     = None

    # RTC related
    self.NET_UPDATE  = False   # update RTC from time-server if time is invalid
    self.SAVE_WAKEUP = False   # save wakup-time on SD (workaround for buggy batteries)

    #sample-mode and interval/time-table
    self.STROBE_MODE = True      # strobe-mode or continuous-mode
    self.INTERVAL    = 900       # interval (in seconds)
    self.TIME_TABLE  = None      # no time-table

    # test (dev) mode settings
    self.TEST_MODE        = False
    self.BLINK_START      = 3      # blink n times  before sensor-readout
    self.BLINK_TIME_START = 0.5    # blink duration before sensor-readout
    self.BLINK_END        = 5      # blink n times  after  sensor-readout
    self.BLINK_TIME_END  = 0.25    # blink duration after  sensor-readout

    # various
    self.CSV_FILENAME        = "/sd/log_{ID}_{YMD}.csv"
    self.CSV_HEADER_EXTENDED = False
    self.SENSORS_CSV_ONLY    = ""
    self.SHOW_UNITS          = True   # show units in dump_data
    self.SIMPLE_UI           = False  # use tabular UI
    self.FONT_DISPLAY        = 'DejaVuSansMono-Bold-18-subset'

    # update configuration variables from imported config.py
    for var in dir(config):
      if var[0] != '_':
        self._logger.print(f"{var}={getattr(config,var)}")
        setattr(self,var,getattr(config,var))
    config = None

    # in case we are running within a gateway context:
    if not hasattr(self,"LOGGER_ID"):
      self.LOGGER_ID = "NOID"
    if not hasattr(self,"LOGGER_NAME"):
      self.LOGGER_NAME = "NONAME"
    if not hasattr(self,"LOGGER_TITLE"):
      self.LOGGER_TITLE = f"{self.LOGGER_ID}: {self.LOGGER_NAME}"

    if hasattr(self,"HAVE_PCB"):   # compatibility to old configurations
      self.HAVE_PM = self.HAVE_PCB
      if not self.HAVE_PCB and not hasattr(config,"HAVE_RTC"):
        # HAVE_PCB==False and HAVE_RTC not set
        HAVE_RTC = None

    gc.collect()

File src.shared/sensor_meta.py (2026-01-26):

#-----------------------------------------------------------------------------
# Sensor metadata.
#
# Data definition and tools for processing csv data collected by the
# datalogger.
#
# Author: Bernhard Bablok
#
# Website: https://github.com/pcb-pico-datalogger
#-----------------------------------------------------------------------------

# --- mapping of sensor to DCODE (see src/sensors/dcode.py)   ----------------

SENSOR_MAP = {
  "id":      "0",
  "dcode":   "1",
  "battery": "2",
  "aht20":   "3",
  "am2320":  "4",
  "bh1750":  "5",
  "bme280":  "6",
  "bmp280":  "7",
  "ds18b20": "8",
  "ens160":  "9",
  "htu31d":  "A",
  "ltr559":  "B",
  "mcp9808": "C",
  "pdm":     "D",
  "pms5003": "E",
  "scd40":   "F",
  "scd41":   "G",
  "sht45":   "H",
  "meteo":   "I",
  "location": "J",
  "cputemp": "K",
  "mhz19":   "L",
  "hdc302x": "M",
  "sen6x":   "N",
  "lm66200": "O",
  "tm_power": "P",
  }

# --- mapping of DCODE to sensor properties: dcode -> (sensor,fields)   ------

# A (single) sensor with a variable field count must be last in the
# SENSORS definition

DCODE_MAP = {
  "0": ("id",1),
  "1": ("dcode",1),
  "2": ("battery",1),
  "3": ("aht20",2),
  "4": ("am2320",2),
  "5": ("bh1750",1),
  "6": ("bme280",4),
  "7": ("bmp280",3),
  "8": ("ds18b20",1),    # variable, 1-n
  "9": ("ens160",4),     # has more fields in test-mode
  "A": ("htu31d",2),
  "B": ("ltr559",1),
  "C": ("mcp9808",1),
  "D": ("pdm",1),
  "E": ("pms5003",9),
  "F": ("scd40",3),      # has more fields in test-mode
  "G": ("scd41",3),      # has more fields in test-mode
  "H": ("sht45",2),
  "I": ("meteo",7),
  "J": ("location",1),
  "K": ("cputemp",1),
  "L": ("mhz19",2),
  "M": ("hdc302x",2),
  "N": ("sen6x",13),
  "O": ("lm66200",1),
  "P": ("tm_power",3),    # variable, 3-n*3
  }

# --- convert string data to str/float/int   ---------------------------------

def _convert_data(data):
  """ convert data from str to /str/float/int """

  for i in range(len(data)):
    try:
      data[i] = int(data[i])
    except:
      try:
        data[i] = float(data[i])
      except:
        # leave as string
        pass
  return data

# --- split csv record according to dcode   ----------------------------------

def split_csv(record, dcode_index=2):
  """ split record according to dcode """

  fields = record.split(',')
  ts = fields[0]
  result = []
  index = 1
  id = None
  for dc in fields[dcode_index]:
    item = {}
    item["sensor"] = DCODE_MAP[dc][0]
    if dc == fields[dcode_index][-1]:
      # last sensor, consume all remaining fields
      item["data"] = fields[index:]
    else:
      # consume fields according to metadata
      item["data"] = fields[index:index+DCODE_MAP[dc][1]]

    # extract id, ignore id and dcode
    if item["sensor"] == 'id':
      id = item["data"][0]
    elif item["sensor"] == 'dcode':
      pass
    else:
      item["data"] = _convert_data(item["data"])
      result.append(item)
    index += DCODE_MAP[dc][1]

  return {"ts": ts,"id": id, "record:": result}

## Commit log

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2023-06-15 fixed link to Readme in KiCAD directory
2023-06-15 fixed link to Readme in KiCAD directory (again)
2023-06-15 fixed link to Readme in KiCAD directory (3rd try)
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2023-07-03 added cutout for LoRa
    [case.scad, dimensions.scad]
2023-07-05 fix depth of cutout
    [dimensions.scad]
2023-07-05 fix cutout
    [case.scad]
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2023-07-20 refactored cutout() to shared_modules.scad
    [case.scad, shared_modules.scad]
2023-07-20 refactored dimensions.scad into shared, top, bottom
    [case.scad, dimensions.scad, dimensions_bottom.scad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]
2023-07-20 renamed case.scad to bottom.scad
    [bottom.scad]
2023-07-20 make height a parameter
    [bottom.scad, shared_modules.scad]
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2023-07-27 ignore errors while creating I2C0
    [main.py]
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2023-07-29 fix: renamed am3220.py to am2320.py
    [am2320.py]
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2023-07-29 fix: renamed am3220 to am2320
    [am2320.py]
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2023-08-03 fix handling of bus,addr vs. addr,bus
    [main.py]
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2023-08-05 preliminary version of datalogger-v2
    [pico-datalogger-v2.kicad_sch]
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2023-08-12 (very) preliminary v2 pcb-layout
    [pico-datalogger-v2.kicad_pcb]
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2023-08-18 fixed header comments (arguments,probing)
    [aht20.py, am2320.py, battery.py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]
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2023-08-19 further routing and layout work
    [pico-datalogger-v2.kicad_pcb]
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2023-08-26 added some more optional components (buttons, I2C-connector)
    [pico-datalogger-v2.kicad_pcb, pico-datalogger-v2.kicad_sch]
2023-08-26 added sensor-pcb (draft, only pcb-connectors + edge-cuts)
    [pico-sensor-pcb.kicad_pcb, pico-sensor-pcb.kicad_sch]
2023-08-27 make UART-5V compatible to Pimoroni PMS5003-adapter
    [pico-datalogger-v2.kicad_pcb, pico-datalogger-v2.kicad_sch]
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2023-08-31 bugfix: search task in tasks-module
    [main.py]
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2023-09-01 datalogger-v2 Rev 0.93 production files
    [BOM-pico-datalogger-v2.csv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]
2023-09-02 fixed rotation and part-placement
    [pico-datalogger-v2.kicad_pcb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]
2023-09-15 added basic components, implement AHT20 and BH1750
    [pico-sensor-pcb.kicad_sch]
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2023-09-19 basic schematic with AHT20, BH1750, PDM-mic, buttons, LEDs (incl. footprints/components)
    [pico-sensor-pcb.kicad_sch]
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2023-09-23 (very) initial pcb-layout for sensor-board
    [pico-sensor-pcb.kicad_pcb, pico-sensor-pcb.kicad_sch]
2023-09-30 Rev 0.7: ready for review
    [pico-sensor-pcb.kicad_pcb, pico-sensor-pcb.kicad_sch]
2023-10-07 add compatibility-connector for application-controls (A-D)
    [pico-sensor-pcb.kicad_pcb, pico-sensor-pcb.kicad_sch]
2023-10-14 Rev. 0.80: fixed PCB-connectors
    [pico-sensor-pcb.kicad_pcb, pico-sensor-pcb.kicad_sch]
2023-10-14 added production-files for Rev. 0.80
    [BOM-pico-sensor-pcb.csv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]
2023-10-28 BOM with special JLCPCB-part-number for AHT20
    [BOM-pico-sensor-pcb-preorder.csv]
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2023-11-21 add cutout for qtpy-sensor
    [top.scad]
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2023-11-21 added comment about zsize
    [dimensions_top.scad]
2023-11-21 minor non-functional changes to support readability
    [top.scad]
2023-11-21 added modules for button-pcb
    [btn_pcb.scad]
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2023-11-25 Rev 0.94: use mosfet instead of jumper for VSYS
    [BOM-pico-datalogger-v2.csv, pico-datalogger-v2.kicad_pcb, pico-datalogger-v2.kicad_sch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]
2023-11-25 Rev: 0.90: minor CPL fixes
    [BOM-pico-sensor-pcb-preorder.csv, BOM-pico-sensor-pcb.csv, pico-sensor-pcb.kicad_pcb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]
2023-11-29 fixed rotation of buttons
    [CPL-pico-sensor-pcb.csv]
2023-11-29 fixes and code-cleanup
    [sensors.scad]
2023-11-29 renamed sensors.scad -> qtpy_sensors.scad
    [qtpy_sensors.scad]
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2023-11-29 create pin-cutout for both 2x2 and 3x1 pins
    [btn_pcb.scad]
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2023-11-29 change size and form of cutouts
    [top.scad]
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2023-12-03 Rev 0.90: fix: swap left-right for Inky-Pack
    [display_adapter.kicad_pcb, display_adapter.kicad_sch]
2023-12-03 Rev. 0.90: first version of LoRa-adapter
    [lora-adapter.kicad_pcb, lora-adapter.kicad_sch]
2023-12-07 LoRa-adapter: Rev 1.00 ready for production
    [BOM-lora-adapter.csv, lora-adapter.kicad_pcb, lora-adapter.kicad_sch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]
2023-12-07 display-adapter: Rev 1.00 ready for production
    [BOM-display_adapter.csv, display_adapter.kicad_pcb, display_adapter.kicad_sch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]
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2023-12-18 bugfix: reset timeout-timer with every IO-operation
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2023-12-19 fix markup for radio-buttons
2023-12-19 fix action of previous button on last page
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2023-12-28 fix handling of SENSORS and TASKS
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2023-12-30 fix handling of checkboxes/radio-buttons
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2024-01-09 fixed pinout (LoRa and buttons)
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2024-01-09 bugfix: JS expects millisends since 1970 for unix-timestamps
2024-01-10 Display-Adaper Rev 1.10: add pin-headers to board (and production files)
    [BOM-display_adapter.csv, display_adapter.kicad_pcb, display_adapter.kicad_sch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]
2024-01-10 LoRa-Adaper Rev 1.10: add pin-sockets to board (and production files)
    [BOM-lora-adapter.csv, lora-adapter.kicad_pcb, lora-adapter.kicad_sch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]
2024-01-12 pretend device-time is in UTC-time to prevent conversion
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2024-01-18 LoRa-Adaper Rev 1.20: move SUR-connector to top
    [lora-adapter.kicad_pcb, lora-adapter.kicad_sch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]
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2024-01-19 removed reset-button (did not work as expected)
2024-01-24 added THT-connectors, finished routing
    [pico-datalogger-v2.kicad_pcb, pico-datalogger-v2.kicad_sch]
2024-01-25 Datalogger-v2 Rev 1.95: larger PCB-size, THT-connectors
    [pico-datalogger-v2.kicad_pcb, pico-datalogger-v2.kicad_sch]
2024-01-26 Datalogger-v2 Rev 2.00: larger PCB-size, THT-connectors (ready for prod)
    [BOM-pico-datalogger-v2.csv, pico-datalogger-v2.kicad_pcb, pico-datalogger-v2.kicad_sch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]
2024-02-01 Datalogger-v2 Rev 2.01: rotated display connector (ready for prod)
    [pico-datalogger-v2.kicad_pcb, pico-datalogger-v2.kicad_sch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]
2024-02-02 Sensor-PCB Rev 1.95: larger PCB, I2C-pullups, labels (ready for review)
    [pico-sensor-pcb.kicad_pcb, pico-sensor-pcb.kicad_sch]
2024-02-03 Datalogger-v2 Rev 2.10: Stemma/Qt on top (ready for prod)
    [BOM-pico-datalogger-v2.csv, pico-datalogger-v2.kicad_pcb, pico-datalogger-v2.kicad_sch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]
2024-02-03 Sensor-PCB Rev 2.00: bump version to 2.00 (ready for production)
    [BOM-pico-sensor-pcb-preorder.csv, BOM-pico-sensor-pcb.csv, pico-sensor-pcb.kicad_pcb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]
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2024-02-07 LoRa-PCB Rev 0.90: test-version with 868MHz (ready for production)
    [BOM-lora-pcb.csv, lora-pcb.kicad_pcb, lora-pcb.kicad_sch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]
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2024-02-12 fixed rotation for AHT20
    [CPL-pico-sensor-pcb.csv]
2024-02-12 removed special preorder version since preoder AHT20 is used up
    [BOM-pico-sensor-pcb-preorder.csv]
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2024-02-22 LoRa-PCB Rev 1.00: version with 433MHz (ready for production)
    [BOM-lora-pcb.csv, lora-pcb.kicad_pcb, lora-pcb.kicad_sch]
2024-03-01 minor fix in comment-header
    [main.py]
2024-03-02 fixed data-processing (LORA-class already decodes the packet)
    [gateway.py]
2024-03-05 minor fix in sleep-time
    [gateway.py]
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2024-04-04 remove battery switchover logic (does not work this way)
2024-04-04 replaced adafruit_sdcard with builtin sdcardio
    [admin.py]
2024-04-27 fixed bugs introduced with last commit
    [lora.py]
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2024-05-04 fix bugs introduced with last commit
    [oled.py]
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2024-05-06 fix number of lines for 128x64 display
    [oled.py]
2024-05-06 check i2c0 if i2c1 fails
    [oled.py]
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2024-06-09 fixed offset of display-cutout
    [bottom.scad]
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2024-06-25 fix return-value for status>1
    [ens160.py]
2024-06-26 bugfix: wrong import statement for scd4x
    [scd40.py, scd41.py]
2024-06-26 prevent indefinite wait for data
    [scd4x.py]
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2024-07-05 don't reset device within constructor
2024-07-05 fix cutouts for LoRa breakout/antenna
    [bottom.scad, dimensions.scad, top.scad]
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2024-07-10 don't require i2c1, switch done-pin directly with correct value
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2024-07-19 print more info when reading config.py fails
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2024-07-24 lora.py: fix bug introduced by last commit
    [lora.py]
2024-07-24 fix: window-start and window-end must be strings
    [config_template.py]
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2024-07-25 fix for boards that don't provide VOLTAGE_MONITOR
    [battery.py]
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2024-07-30 replace board.xxx with pins.xxx
    [admin.py, battery.py, scd4x_config.py]
2024-08-01 ens160 does not work with only-lowercase properties
    [ens160.py]
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2024-08-06 rework multi-sample code
2024-08-08 minor fix in labels/header
    [meteo.py]
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2024-08-09 add missing 'ts,' to CSV-header
    [scd4x_config.py]
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2024-08-22 next iteration / refactoring of dimensions to separate files
    [battery_cage.scad, battery_cage_dims.scad, dl_holder.scad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]
2024-08-28 fix depth of sides for top and bottom tube
    [stevenson_holder.scad]
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2024-09-05 copied design from other project to integrate into sensor-holder
    [bmx280_holder.scad]
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2024-11-25 add logger to constructor, fix some defaults
    [settings.py]
2024-11-25 bugfix: wrong raise syntax
    [hw_helper.py]
2024-11-25 treat all configured hardware as mandatory and fail on exception
    [gateway.py]
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2024-12-02 bugfix: add pins to hw_helper.init_rtc()
    [admin.py, gateway.py, hw_helper.py]
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2024-12-05 don't trace exception if netupdate fails
2024-12-12 nonfunctional: fix name within comment
    [gw_tx_noop.py]
2024-12-17 support short options, add -d/--debug for print_err()
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2025-09-01 fix units and scale
    [pms5003.py, sen6x.py]
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2025-11-12 fix pin-order for SEN66-connector
    [front.kicad_sch, lora.kicad_sch, pico-datalogger-v3.kicad_pcb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]
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2025-11-12 flipped I2C0-THT to back-side
    [pico-datalogger-v3.kicad_pcb]
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2025-11-19 swapped SWA/SWB with LoRa-RST/LoRa-CS; initial routing of LoRa and buttons
    [front.kicad_sch, lora.kicad_sch, pico-datalogger-v3.kicad_pcb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]
2025-11-20 swapped additional pins to simplify routing
    [front.kicad_sch, lora.kicad_sch, pico-datalogger-v3.kicad_pcb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]
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2025-11-21 fixes for production files
    [front.kicad_sch, lora.kicad_sch, pico-datalogger-v3.kicad_pcb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]
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2025-12-09 use reverse iteration for freeing i2c-busses
    [hw_helper.py]
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2025-12-12 fixed 3D model for battery-holder
    [pico-datalogger-v3.kicad_pcb]
2025-12-15 fixed calculation of time-factor
    [lora.py]
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2025-12-15 replace LORA_RECEIVE_TIMEOUT with LORA_GW_RECEIVE_TIMEOUT
    [config_template.py]
2025-12-15 fix: receive() needs timeout with keyword
    [gw_rx_lora.py]
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2026-01-07 fix: create SPI, if LoRa and SD are on different busses
    [gw_rx_lora.py]
2026-01-11 added some missing source files
    [InkyPack.py]
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2026-01-12 add timeout, fix csv
    [tm_power.py]
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2026-01-21 return missing values instead of 'None'
    [tm_power.py]
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2026-01-26 fix: extract id as contents of item (which is a single value list)
    [sensor_meta.py]
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2026-01-27 close response/socket in case of problems
    [tm_power.py]
2026-01-27 fix tm_power.py (editor wasn't saved)
    [tm_power.py]
